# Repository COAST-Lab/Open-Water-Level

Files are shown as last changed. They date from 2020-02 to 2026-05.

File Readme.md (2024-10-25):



# Open Water Level Sensor
## ℹ️ About this Repository
This GitHub repository provides updated designs for a low-cost, open-source, cell-equipped water level sensor. The initial design, published in the journal Oceanography in the special section DIY (do-it-yourself) Oceanography, used a lower resolution sensor and had internal datalogging capabilities. In this repo, we describe how to use a higher-resolution sensor with a cellular modem for near-real-time water level information. 

The article, *A Low-Cost, DIY Ultrasonic Water Level Sensor for Education, Citizen Science, and Research*, can be found here: [https://doi.org/10.5670/oceanog.2023.101](https://doi.org/10.5670/oceanog.2023.101). The article corresponds to an older version of the code which can be found here: [https://github.com/SUPScientist/Seaport_Tide-SLR](https://github.com/SUPScientist/Seaport_Tide-SLR).

Please read the following for a high-level overview of the project and the contents of this repository.

## 🔮 Table of Contents 
Scroll down or click the following links for more information: 
- [Introduction to the Sensor](#-introduction-to-the-sensor)
- [How to Build a Sensor](#-how-to-build-a-sensor)
- [Firmware and getting started guide](Firmware)
- [Deployment Considerations](#-Deployment-considerations)
- [Data Analysis](#-example-data-analysis-routine)

Water level sensor

## 🔌 Introduction to the Sensor
There are several versions of the DIY water level sensor. They include different microcontrollers (e.g., an Arduino-based Feather Adalogger with internal logging capabilities and a Particle Boron with cellular communication capabilities) and sensor interfacing options (analog, serial, and pulse-width modulation). 

If you are looking for a cellular data transmission-enabled device with higher resolution, this repository has what you need. To get started on soldering and building your sensor package, click here [Firmware](Firmware). If you are looking for the original, less expensive Arduino version with internal datalogging capabilities, see [https://github.com/SUPScientist/Seaport_Tide-SLR](https://github.com/SUPScientist/Seaport_Tide-SLR).

The device designs in this repository comprise a low-cost open-sourced sensor package designed to measure distance and transmit and store measurements.  It utilizes a Particle Boron with cellular data transfer, an Adafruit Adalogger Featherwing for local data storage, a Maxbotix ultrasonic rangefinder, a rechargeable lithium-ion battery, and a water-resistant enclosure. 

This repository aims to enable students, communities, businesses, and anyone else to monitor their local water level. To get started, read through this page and subsequent directions. 

## 🔨 How to Build a Sensor
We currently have two effective enclosure designs for the DIY sensor, one using a PVC pipe and the other using a Polycase housing. Below, find links to BOMs, enclosure designs, and datasheets for each model.
- Getting started with the code: [Firmware](Firmware) 
- Link to parts, suppliers, and costs: [PVC BOM](Fabrication/PVC-Enclosure/BOM/), [Polycase BOM](Fabrication/Polycase-Enclosure/BOM/)
- Enclosure designs: [PVC Enclosure & Assembly](Fabrication/PVC-Enclosure/Enclosure-and-Assembly/), [Polycase Enclosure & Assembly](Fabrication/Polycase-Enclosure/Enclosure-and-Assembly/)
- More information on parts: [PVC Datasheets](Fabrication/PVC-Enclosure/Datasheets/), [Polycase Datasheets](Fabrication/Polycase-Enclosure/Datasheets/)

## 🌊 Deployment Considerations
Deployment is the last step but it's probably the most exciting, so we'll start our procedural notes here. The Open Water Level sensor has a ~ 6.5 m (21') range with a 1 cm (0.39") resolution. Deployment locations must be chosen with these values in mind. If you are deploying the monitor at a location reasonably close to an existing NOAA tide station, start by examining the known tidal range at your location: [NOAA tide predictions](https://tidesandcurrents.noaa.gov/tide_predictions.html). You will want to deploy the monitor at a location where it can aim straight down (normal) to the water's surface and at a height slightly higher than the highest high tide or floodwater height that the location is expected to experience. You also want it to be low enough to capture the lowest low water. The package is water resistant, but not fully waterproof if submerged for extended periods.

## 💻 Example Data Analysis Routine
Please see this [example notebook](Data%20Analysis/open_water_level_analysis.ipynb) for Python code that reads in, parses, and plots water level data, including the critical conversion of `distance from the sensor to the water` to a `referenced water level`.

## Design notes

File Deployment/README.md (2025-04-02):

Once you have successfully fabricated the **PVC Model** based on these [steps](https://github.com/COAST-Lab/Open-Water-Level/tree/ac8e949a22b2f5b2a5e1ccd7503b6fde46d579b2/Fabrication/PVC-Enclosure), follow this guide for deployment. Extra supplies needed for these steps are PVC cement, Silicon Sealant, Low Density PTFE seal tape, and O-Ring Silicon Grease.
1. Ensure that the extra LiPo battery and Solar system battery are fully charged.
2. Verify that the correct code and firmware is flashed onto your Boron.
3. We recommend including electrical tape to secure the antenna and 3 pin wires to the side of the chassis. This will help decrease any noise and movement within the PVC during deployment. 
4.Use PVC cement to securely bond the PVC Reducer Bushing, PVC Coupler, and PVC Pipe. Follow the manufacturer's guidelines on the PVC cement packaging for best results. **Safety Note:** Always use PVC cement in a well-ventilated area, preferably outdoors, and wear protective gloves. After cementing, place the assembled product in a fume hood to minimize exposure to fumes.
5. Apply O-ring grease to the O-rings on the PVC end cap and cable gland. **Note:** Before greasing, ensure the O-rings and grooves are completely free of dust and other particles. We recommend using Kimwipes and gloves to clean the rings and grooves thoroughly. Additionally, place Kimwipes on your work surface to keep the components clean during the process.
6.Wrap PTFE seal tape around the threads of the Maxsonar. **Note:** Apply the tape in the same direction as the threading to ensure it remains securely in place when tightened into the PVC bushing, preventing it from unraveling.
7. Once fully charged, place the lipo battery back on the chassis, attach the 3-pin wires together, and slide the chassis into the PVC pipe. 
8. Attach the solar cable gland to the PVC end cap. **Note:** Once the Lipo battery or solar panel cable is plugged into the Boron it will turn on and begin collecting data every hour on the hour. This may be important for your cellular usage. 
9. Once all components are securely placed and connected inside the pipe, attach the PVC cap. Apply silicone sealant to seal the gap between the PVC end cap and the pipe, as well as the space between the solar cable gland and the PVC top.

**Field Specific Deployment Considerations**

According to the ultrasonic sensor's datasheet, objects within a 30 cm radius of a beam normal to the sensor's surface could interfere with its measurements. We recommend deploying the sensor at least **45 cm (or a 50% margin)** away from the closest object to the sensor's downward beam. Also condifer that this sensor has a minimum report distance of **25 cm** and a maximum report distance of **700 cm**.

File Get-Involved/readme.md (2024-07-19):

- Check out the "Get Involved" pamphlet above (available in .pdf and .pptx formats) for ways to become involved with the Open Water Level Sensor project!

- Visit this [link](https://blog.iorodeo.com/author/grace/) for articles featuring the water level sensor project on the IO Rodeo Blog, guest-written by lab member Grace Lower.

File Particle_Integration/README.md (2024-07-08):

# Particle Cloud —-> Google Sheets Integration
1. Get an access token: https://docs.particle.io/reference/cloud-apis/access-tokens/
2. Create a new Google Sheet
3. In Google Sheets, navigate to Extenstions --> Apps Script
4. Copy and paste the `particle_integration.js` file into the Apps Script
5. Replace `{YOUR_PARTICLE_TOKEN_HERE}` with your token from #1
6. Save/rename Apps Script
7. Deploy --> New Deployment (if first time deploying)
8. Select type --> Web App
9. Execute as --> Me
10. Who has access --> Anyone
11. Deploy --> Authorize access --> Click through and allow
12. Under Web App and URL, there should be a URL beginning https://script...; click Copy
13. In `console.particle.io`, navigate to your product (or device) and create a new integration
14. Create Webhook and select Edit --> Custom template
15. Copy and paste text from `particle_integration.json` and replace `{GOOGLE_SHEETS_SCRIPT_URL}` with the URL that you get after deploying the Apps Script (Step 12); save.
16. Run your Particle firmware that is supposed to publish to the cloud and check if it ran at all (e.g., any LED or Log indicators). Then, check the device in `console.particle.io` to see if it published, check the integration to see if it triggered, and check your Google Sheet to see if the data have shown up.

## Credit
This routine borrows from and slightly updates [https://docs.particle.io/integrations/community-integrations/publish-to-google-sheets/](https://docs.particle.io/integrations/community-integrations/publish-to-google-sheets/). Hints on what needed to be updated came largely from [https://community.particle.io/t/pushing-data-to-google-sheets-new-thread/60138](https://community.particle.io/t/pushing-data-to-google-sheets-new-thread/60138).

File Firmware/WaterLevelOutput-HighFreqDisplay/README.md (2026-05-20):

# WaterLevelOutputActivity

This firmware project was created using [Particle Developer Tools](https://www.particle.io/developer-tools/) and is compatible with all [Particle Devices](https://www.particle.io/devices/).

Feel free to replace this README.md file with your own content, or keep it for reference.

## Table of Contents
- [Introduction](#introduction)
- [Prerequisites To Use This Template](#prerequisites-to-use-this-repository)
- [Getting Started](#getting-started)
- [Particle Firmware At A Glance](#particle-firmware-at-a-glance)
  - [Logging](#logging)
  - [Setup and Loop](#setup-and-loop)
  - [Delays and Timing](#delays-and-timing)
  - [Testing and Debugging](#testing-and-debugging)
  - [GitHub Actions (CI/CD)](#github-actions-cicd)
  - [OTA](#ota)
- [Support and Feedback](#support-and-feedback)
- [Version](#version)

## Introduction

For an in-depth understanding of this project template, please refer to our [documentation](https://docs.particle.io/firmware/best-practices/firmware-template/).

## Prerequisites To Use This Repository

To use this software/firmware on a device, you'll need:

- A [Particle Device](https://www.particle.io/devices/).
- Windows/Mac/Linux for building the software and flashing it to a device.
- [Particle Development Tools](https://docs.particle.io/getting-started/developer-tools/developer-tools/) installed and set up on your computer.
- Optionally, a nice cup of tea (and perhaps a biscuit).

## Getting Started

1. While not essential, we recommend running the [device setup process](https://setup.particle.io/) on your Particle device first. This ensures your device's firmware is up-to-date and you have a solid baseline to start from.

2. If you haven't already, open this project in Visual Studio Code (File -> Open Folder). Then [compile and flash](https://docs.particle.io/getting-started/developer-tools/workbench/#cloud-build-and-flash) your device. Ensure your device's USB port is connected to your computer.

3. Verify the device's operation by monitoring its logging output:
    - In Visual Studio Code with the Particle Plugin, open the [command palette](https://docs.particle.io/getting-started/developer-tools/workbench/#particle-commands) and choose "Particle: Serial Monitor".
    - Or, using the Particle CLI, execute:
    ```
    particle serial monitor --follow
    ```

4. Uncomment the code at the bottom of the cpp file in your src directory to publish to the Particle Cloud! Login to console.particle.io to view your devices events in real time.

5. Customize this project! For firmware details, see [Particle firmware](https://docs.particle.io/reference/device-os/api/introduction/getting-started/). For information on the project's directory structure, visit [this link](https://docs.particle.io/firmware/best-practices/firmware-template/#project-overview).

## Particle Firmware At A Glance

### Logging

The firmware includes a [logging library](https://docs.particle.io/reference/device-os/api/logging/logger-class/). You can display messages at different levels and filter them:

```
Log.trace("This is trace message");
Log.info("This is info message");
Log.warn("This is warn message");
Log.error("This is error message");
```

### Setup and Loop

Particle projects originate from the Wiring/Processing framework, which is based on C++. Typically, one-time setup functions are placed in `setup()`, and the main application runs from the `loop()` function.

For advanced scenarios, explore our [threading support](https://docs.particle.io/firmware/software-design/threading-explainer/).

### Delays and Timing

By default, the setup() and loop() functions are blocking whilst they run, meaning that if you put in a delay, your entire application will wait for that delay to finish before anything else can run. 

For techniques that allow you to run multiple tasks in parallel without creating threads, checkout the code example [here](https://docs.particle.io/firmware/best-practices/firmware-template/).

(Note: Although using `delay()` isn't recommended for best practices, it's acceptable for testing.)

### Testing and Debugging

For firmware testing and debugging guidance, check [this documentation](https://docs.particle.io/troubleshooting/guides/build-tools-troubleshooting/debugging-firmware-builds/).

### GitHub Actions (CI/CD)

This project provides a YAML file for GitHub, automating firmware compilation whenever changes are pushed. More details on [Particle GitHub Actions](https://docs.particle.io/firmware/best-practices/github-actions/) are available.

### OTA

To learn how to utilize Particle's OTA service for device updates, consult [this documentation](https://docs.particle.io/getting-started/cloud/ota-updates/).

Test OTA with the 'Particle: Cloud Flash' command in Visual Studio Code or the CLI command 'particle flash'!

This firmware supports binary assets in OTA packages, allowing the inclusion of audio, images, configurations, and external microcontroller firmware. More details are [here](https://docs.particle.io/reference/device-os/api/asset-ota/asset-ota/).

## Support and Feedback

For support or feedback on this template or any Particle products, please join our [community](https://community.particle.io)!

## Version

Template version 1.0.2

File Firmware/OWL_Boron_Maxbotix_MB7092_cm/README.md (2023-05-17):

# SLR_Boron_Maxbotix_MB7092_cm

Script intended to operate a 1 cm resolution, waterproof ultrasonic sensor (MB7092 from Maxbotix) with a Particle Boron. Uses SLR_Boron_Maxbotix_Analog firmware and modifies that script (which was designed for a different sensor with 1 in resolution). Modified by L. Edwards in Spring 2023 and pushed to GitHub initially on 17-May-2023 by P. Bresnahan.

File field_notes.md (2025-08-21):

# Field Notes
NB: Bresnahan has spreadsheet with Device IDs, Device OS, user firmware version (e.g., OWL v1.1.0 or 1.0.0, etc.) in Dropbox. This document is intended for miscellaneous notes from the field jotted quickly while servicing instruments.

### 21-Aug-2025
- SMC-N23 is gone. Entire mount missing from bridge. Only epoxy remaining.
- SMC-KERR updated to Device OS 6.3.3 and firmware built to that OS with `const unsigned long MAX_TIME_TO_PUBLISH_MS = 600000;` Used Workbench "flash application and device OS (local)" option.
- Update: SMC-KERR did not connect to cloud after using Workbench flash application and device OS option so used online Device Restore USB option to 6.3.3 which received a success message. 

### 6-Aug-2025
- At SMC-KERR and BMCUpdated Device OS to 6.2.1 and flashed firmware built to that OS with `const unsigned long MAX_TIME_TO_PUBLISH_MS = 600000;` Used Workbench "flash application and device OS (local)" option.

### 19-May-2025
- From SMC-N23, traded solar panel and interior battery due to inexplicable battery failure (suspected to be issue with solar panel/pack)

### 11-Mar-2025
- Chestnut St and Burnt Mill Creek installed
- Activated 10:36 am EDT, waterLevel_0006, longer pvc

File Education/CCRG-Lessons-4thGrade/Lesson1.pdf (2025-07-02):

What is a Watershed?
Location: Classroom
Time: 50+ Minutes

General Lesson Overview: In this lesson, students will learn what a watershed is and how elevation is important in identifying watershed boundaries in a community. Students will learn how to make a topography map and will practice making a 3D model from a topographical map of a watershed. For this lesson in particular we focus on Burnt Mill Creek, but this could be recreated with any watershed as the location.

- ESS.4.2.3. Use models to explain changes in Earth’s surface over time (to include slow changes of erosion and weathering, and fast changes of earthquakes, landslides, and volcanic activity).

Background Information:
What is topography and why is it important?

Topography is the study of the forms and features of land surfaces. When we talk about topographic maps, we are usually referring to maps with elevation contour lines drawn. Understanding variations in elevation helps us to understand how water may move across the surface. We can determine direction by knowing that water moves from higher to lower elevations, or speed by knowing the influence of slope. Elevation and proximity to water features like streams and rivers can also be used to predict potential flooding.

How do you collect elevation data?
Elevation data can be collected in several ways. Ground surveys can be conducted using RTK (Real-Time Kinematic) GPS. Aerial surveys may also be conducted using sensors (typically LiDAR) mounted on drones or piloted aircraft. Stereo photogrammetry, where photographs taken at slightly different locations are cross-referenced against each other and a known surveyed target, may also be used for gathering elevation data.
What is our community's topography?
We reside in the Coastal Plain for North Carolina which is flat and low lying. The gentle slope of the Coastal Plain make the high velocity water associated with flash flooding unlikely, however, we have an abundance of water features, like the Cape Fear River, our various creeks, and the ocean, which may flood nearby low-lying areas when their water levels rise.
What is GIS, how were the maps made?
Maps are made using Geographic Information Systems (GIS), which are computer systems that analyze geographically referenced information. The data processed using GIS can be gathered via ground survey, aerial survey, or satellite.

Materials and supplies:
- Powerpoint Watershed Modeling Lesson.pptx
- Contour box – with preset measuring units on the side
- Water (in gallon jugs)
- Food coloring - blue
- wet/dry erase
- Sections of watershed topomaps
- White Legos or block landforms
- Lego base or landform base

Procedure:
1. Introductions to the project and the task of today.
a. Today we are focusing on understanding the watershed that we live in and how water flows in our community by looking at maps and understanding elevation data.
b. Have you ever been impacted by flooding?
2. What is a watershed? Do you know what watershed you live in?
a. Have student Think, Pair, Share what is a watershed
b. Guide students to the definition of a watershed.
i. A watershed is a land area that drains water to a common outlet, such as a river, bay, or reservoir. Watershed can also be called a drainage basin or catchment.
3. Scientists use maps to talk about land areas. What do you use a map for?
a. Use the powerpoint to project the google earth map of Wilmington. The purpose of looking at this map is for students to see how we talk about land and how directional and landmark data is displayed on 2D models aka the map.
4. Click to the GIS map of the watershed (the map displayed could be of whatever watershed is in discussion). For this lessons purpose we are focusing on Burnt Mill Creek watershed. The watershed is outlined and shown in blue.
a. Ask students to tell you where rain would gather if it rained at different places in the map.
b. Ask student how they think the watershed was identified. What type of data did scientists maybe use? Guide them if you can to elevation data or how high the land is.
5. What is elevation?
a. Elevation is the height of a location above or below sea level.
b. Let's find out how scientists use maps to communicate elevation!
6. Contour box activity – students will draw a topographical map.
a. Demo how students will work in science teams through this activity. By showing how to do the first level at 2cm then pass out the materials to each small group. (prefer 8 small groups)
i. Pour water to 2cm line
ii. Replace lid.
iii. Trace with a marker
iv. Label with the level and also put a dot on the corner where the ruler is so that you always put the lid on the box the same.
b. Pass out boxes, water, marker.
c. Ok everyone goahead and pour to your first line. Once you meet the line set your pitcher down and put the lid on and draw. Raise your hand when you are done.
d. Alright everyone got that? Awesome. Let'sdo the next level together. Pour water to the third line. Ready go.
i. Put your lid on and draw. Raise your hand when you are done.
e. Next level.
f. 5

th level.
g. 6

th level.
7. Great job! you just drew a topographic map of the mountain.

a. What did you find challenging?
b. What are some observations of your map?
i. Some lines are tight together. At those spots on the landform what do you notice? The land is steep!
c. How do you think someone might use this type of map?
*** Clean up the activity by pouring water back into the milk jugs.
d. Jug in a bucket, funnel over hole, mountain out of shoe box, and pour.
e. This can be done by one person while the other walks around during the Lego build part.
8. You all just drew a topo map from a 3D representation of land. Now we are going to work in reverse! In your small groups you guys are going to take a section of the Burnt Mill Creek watershed and build a 3D model using Legos (older students) or other stacking tools (watershed ).
a. Each small group has a map in front of them. What do you see on the map in front of you?
i. There might be landmarks on your map that you recognize or there might not. Have you ever looked at your neighborhood on a map?
ii. What other things do you see on your map?
1. Numbers – the numbers represent elevations just like what you did on the previous activity. That elevation data was most likely collected using LiDar attached to a drone or via satellite. may have been collected using a
2. A grid – to provide you with guidance as you build up the watershed.
a. To do this you will follow the grid pattern on the lego board and map.
i. 1 grid (1.5cmX1.5cm) = 2X2 lego brick = 845ft
ii. 1 brick height = 5 ft. In elevation
b. Demo doing a grid or 2 with the group. Let the groups test it out. Walk around and support students. If everyone is really struggling get the classes attention and open the floor for students share their challenge and work as a class to solve.
9. What does the elevation LOOK like? How does water flow?
10. Any thoughts on why we would start our discussions of flooding by talking about elevation?
- Water flow to the lowest point and it important to understand when those low spots are in a community.
- As rain increase what else increases? Amount of water the the covers more land.
- What is the other thing scientists should study when they are studying flooding and also want communities to stay safe?
- Water LEVEL! The next time we see you we will be engineering a tool that scientists could use to monitor water levels.
11. Put the landform models into the AR Sandbox and see what happens when it rains.

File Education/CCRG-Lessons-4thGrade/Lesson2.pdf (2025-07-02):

Engineer a water level monitoring tool Location: Classroom
Time: 1 hr

General Lesson Overview: In this lesson, students will engineer a water level tool with consumable materials. Students will interact with a water level sensor and learn about data output for water level during a number of different scenarios.

Background Information:

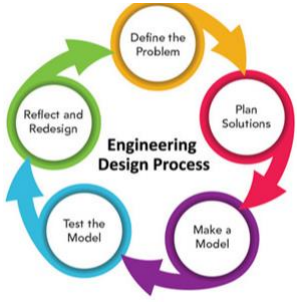
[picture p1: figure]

75% of the world’s population lives within 30 | miles
of a coastline and 90% live within even closer to
freshwater. Our development close to water
bodies requires that water levels stay mostly
stable. Drought that reduces water levels may | have
negative effects on water quality, and excess rain
results in flooding. This is why we monitor water
levels very closely. Federal, state, and local
governments want to know so that we can best prepare and manage.

Why do we care about water level? Flood risk
management, emergency action planning, and | land
and habitat management.
- Environmental health
- Too low = Loss of habitat/food/drinking water, higher concentration of pollutants, erosion or exposed soils.
- Too high = erosion of riverbanks/beds, spread of pollutants and silt, damage vegetation and development, loss of life.
- To manage these risks we engineer levees, spillways, dams ect.
What can we do with water level data?
- Optimize engineering efforts to mitigate flood risks.
- Anticipate floods and take protective measures to reduce people from harms way. Water level measurement methods
1. Staff gauge – giant stick out in the water
2. Wire-weight gauge
3. Shaft encoder/ strip chart recorder – early sensor

4. Pressure transducer – sensor type
5. Bubbler– sensor type
6. Radar– sensor type
7. Hydroacoustic sensors – sensor type - doppler principle to measure.
Definitions:
Water level – the vertical distance (or elevation) from a specific point of reference to the water’s surface. In rivers and streams, it is often referred to as gauge height or stage.
Flood – water on land that is normally dry. Common natural occurrence impacting every US state and territory. Costs of flooding estimate is $8.2 billion and rising annually.
Crest Gage: A Quick Way to Measure River Stage | U.S. Geological Survey (https://www.usgs.gov/special-topics/water-science-school/science/crest-gage-a-quick-way-measure-river-stage)
Materials:
- Bottle caps
- Dowels
- Clear tubing
- Ruler tape
- Floating Styrofoam
- Floats
Procedure:
1. Begin this lesson by having students think about how water moves during a rainstorm. With that in mind, read the picture book FLOOD. FLOOD is a true picture book and does not have any words.
a. If there is time have students sit in a circle and pass the book around with student telling the story by making up sentences to tell the group what is happening on each page. They can create characters or read in 1st person of a kid in the family.
b. If you are tight on time the instructor can walk around telling the story on each page.
i. Key things to point out in the book include:
1. The water body in the back of the property.
2. Ominous storm rolls in.
3. Parents watching the weather and planning while the kids sleep
4. Preparing the property for the storm.
5. Deciding to evacuate.
6. Flood happening overtime
7. Receding flood
8. Resilient and rebuild as community not alone.
2. Review the definitions of a flood and water level, can use to accompanying PowerPoint, EngineerAWaterLevelMonitoringTool.pptx (https://uncw4.sharepoint.com/:p:/r/sites/MarineQuest/Lessons%20and%20Curriculum/Grants/WRRI.CCRG%20-%20Water%20Level/EngineerAWaterLevelMonitoringTool.pptx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)
a. Flood: An overflowing of water onto land that is normally dry.
b. Water level: the vertical depth of water from a reference point. Often referred to as gauge height or stage.
3. Why do we care about the water level???
a. After asking students why we should monitor the water level in present the photo and figure to them.
b. The photo on the slide shows Smith Creek at Kerr Ave. Ask them if they can guess when based on the graph the photo was taking. Using a few context clues they might be able to guess that the photo was taken during TS Debbie in August 2024.
4. Using the engineering cycle, students are tasked with engineering a no tech water level monitoring tool.

a. Present the engineering cycle
b. Brainstorm solutions that are already in existence.
i. Photo of crest gauge.
ii. Ask if they can think of anything students have already seen in the environment.
c. Present the problem: engineer a water level monitoring tool that doesn’t require you to be in the environment to see the highest height of the water level.
d. Review materials with the students

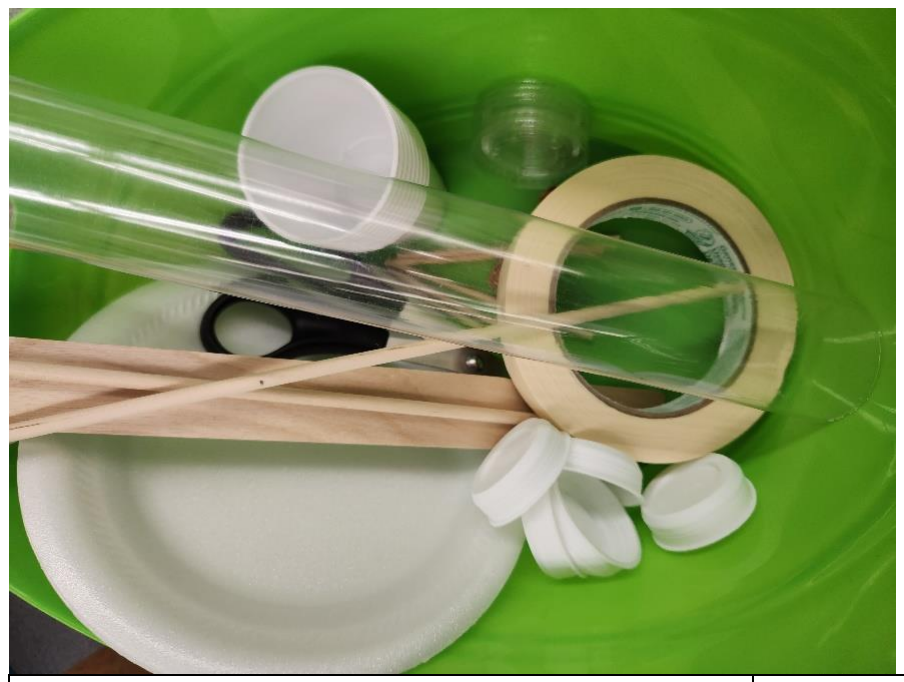
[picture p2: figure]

e. 5 minutes to talk with their table team and draw their design.
f. 10-15 minutes to build.
i. Drilling, box cutting, and dowel cutting ask teacher for help.
g. Test by adding water into a bucket.
i. With about 3 inches of water as the existing water level place the design in the water, for some kids this could be up to the 0 level or at the normal level of the water body (A). Then add more so that the water level increases. You can mimic waters receding as you slowly pull up the monitoring tool (B).

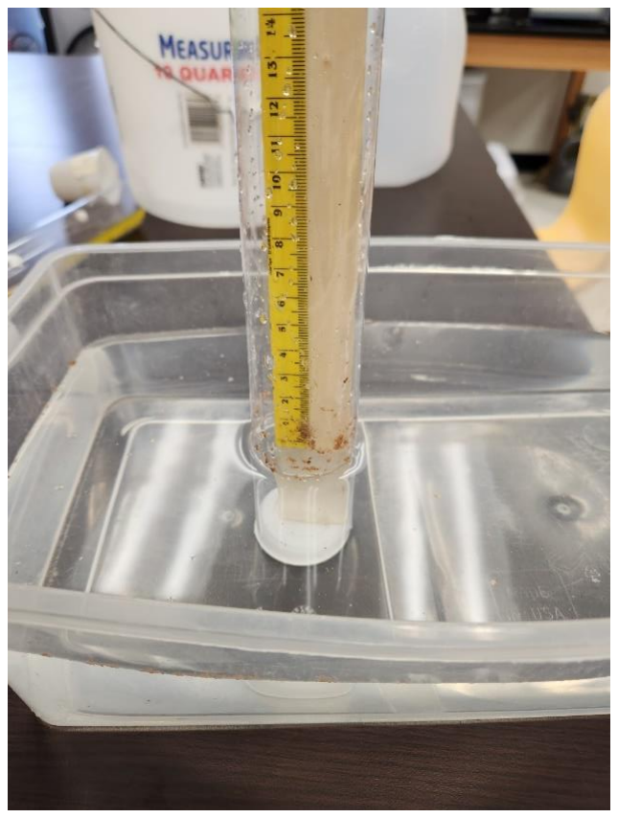
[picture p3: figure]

A. Water monitoring tool in water at mean level.

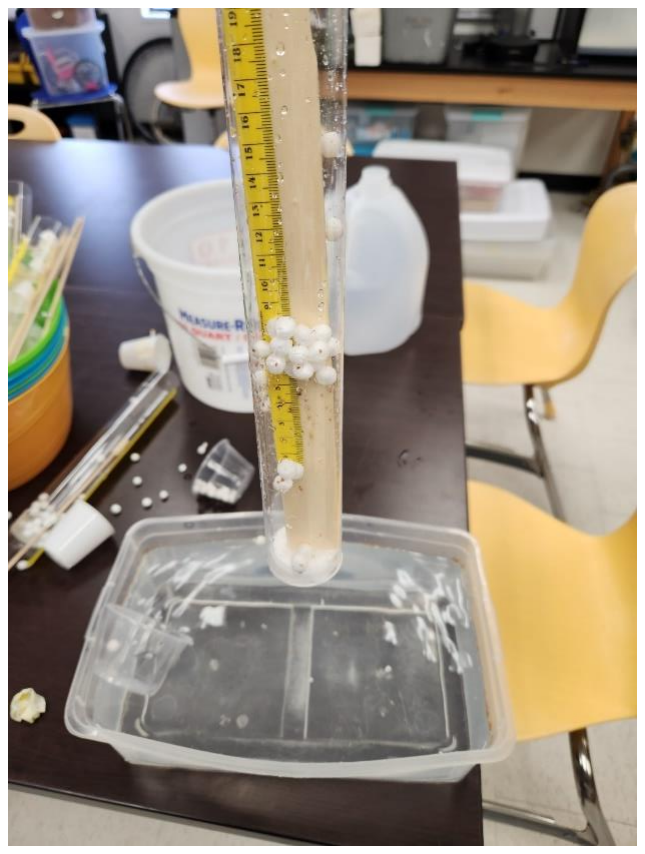
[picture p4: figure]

B. Water level monitor being removed from a flood stage test mimicking water levels receding. Notice how the cork dust and Styrofoam balls stay at the highest high level.
5. If there is time have students present their tool. They should identify pros and cons of their design and what they would do in their redesign.

6. Show students the USGS cork tool.
7. Now that students have designed and identified pros and cons I’m sure they all will want to add some TECH! In the next 5 minutes introduce how electronics have revolutionized environmental monitoring.
a. Show students how the ultrasonic water level sensor works.
b. Give students and opportunity to ask questions and look at the sensor up close.

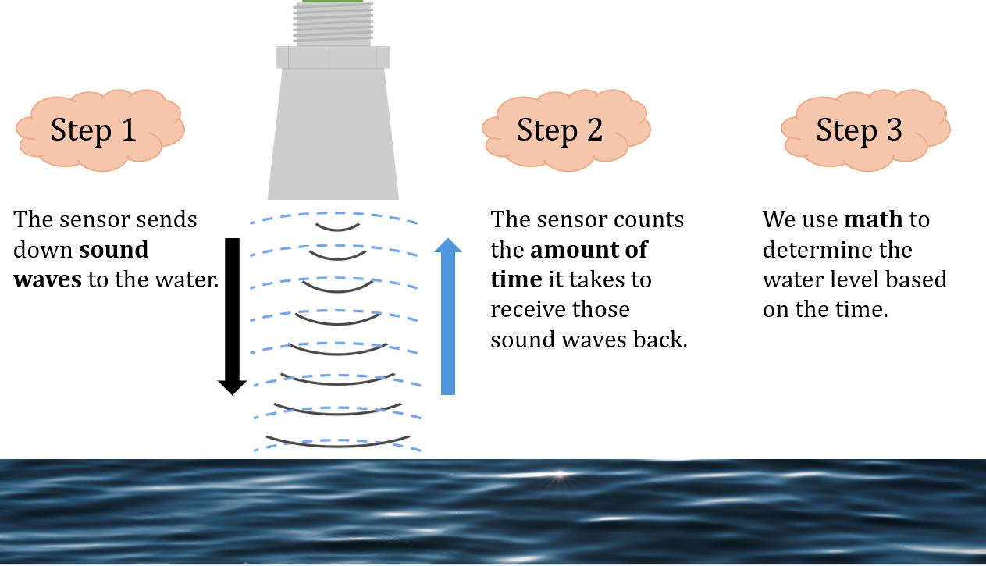
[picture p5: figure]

References:
https://blog.aem.eco/fundamentals_of_water_level_measurement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
Increase the challenge:
Give students a budget for their supplies and they must purchase supplies for the build.

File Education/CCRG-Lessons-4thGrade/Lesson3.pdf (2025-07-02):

VR Burnt Mill Creek Experience
Location: Classroom
Time: 1 hr

General Lesson Overview: Provide students with an immersive experience seeing and making observations of Burnt Mill Creek. This is a general overview of the creek from the headwaters to where it flows into a larger creek, Smith Creek.
Materials:
VR headsets and phones with Expeditions Pro App downloaded
Tablets with Expeditions Pro App downloaded
Wi-Fi router
Internet for downloading the tour onto the tablet https://tours.expeditionspro.com/tour/7929 ***UNCW CESTEM has VR sets available for check-out with the completion of a training course.
Prep:
- Before students arrive, you will need to set up the VR headsets. The phones in the headsets must be charged, have the same version of the app as the teacher tablet, and be connected to the no internet Wi-Fi router if you are using the CESTEM set.
- You must download the tour on the teacher tablet under your specific user account while on the internet. Procedure:
1. Today we are going to go on a virtual field trip hike along Burnt Mill Creek. Using a projected map like the one below, tell the students where they will be going. Headwaters to where the creek joins a larger creek called Smith Creek.

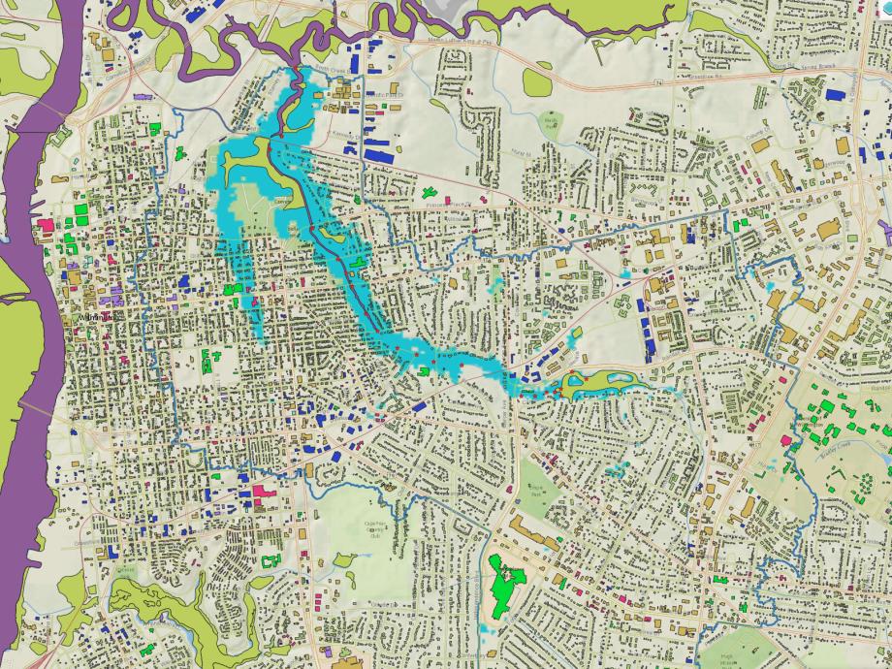
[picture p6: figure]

2. Before students put their headsets up to their faces, please review VR rules and expectations of listening while on the tour.
a. You can stand or sit with the VR headsets. Do not walk.
b. It's ok if you start to feel a little woosie. Just set down your headset. We have a few tablets that we can pass out so that you can still participate.
c. At each tour stop you will have about a minute to look around on your own and be amazed. Once I call everyone back, please stop talking so that everyone can hear.
d. The instructor leads the field trip and will be the one who changes the scene.
3. Let's go! The leader/instructor uses the scene description and asks observation-based questions to keep students engaged.

Trouble shooting
- Make sure the phone is on the correct wi-fi.

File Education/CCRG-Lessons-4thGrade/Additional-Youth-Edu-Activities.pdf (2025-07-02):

# FLOODING LESSON PLAN

Objective: Children of all ages will learn about the effects of flooding and how it connects to the community in Wilmington.

Overview: Kids will be split into two groups based on grade and work on the following highlighted activities about flooding, the issues it brings, and working towards resiliency.

Activity 1: Watersheds (20-30 min)

Kids will work together (can be in groups if there are a lot) to work on the following activities. This gives the kids an understanding of how and where water flows before they move onto the hands-on approach in the next activity.

Group 1 (younger kids) - Branching Out Activity:

Overview: Ideally for ages K-2, kids will use pipe cleaners to make a branching system that goes from streams to rivers. For older students, they can also help name creeks that are local to Wilmington.

Materials needed:

- Pipe cleaners
- Colored pencils, markers, crayons, pencils
- Lined and blank sheets of paper

Directions:

1. Starting with one pipe cleaner, explain to students how this represents a body of water called a creek. Help them understand that this one creek is a small part of the system.
2. Before moving on, relate the creek location to a nearby location (school, community, park, etc.)
3. Continue the branch system by adding another pipe cleaner to the original, making another creek. Help students imagine water flowing from the multiple creeks into the same place.
4. Add more pipe cleaners until you’ve created a stable center connection. Have students guess what this could represent. If they aren’t able to guess correctly, let them know it is a river.
5. Discuss some of the following questions upon completing:

a. What do you think the river flows into? (ocean)
b. Do you think the creeks and river would look the same in a thousand years? Have them think of natural and human-related effects.
c. What would happen if it started to rain a lot?
6. If time permits, students can write a story about or draw a picture of how or where the river flows.

Group 2 (older kids) – Land Coverage Maps

Overview: Students will have maps of Wilmington from two time periods to compare how much land coverage has changed over time and how that can affect runoff in watershed.

Materials:

- Maps of Wilmington from different years
- Wilmington Area Watersheds page

Directions:

1. Ask kids what some major cities might have been like 100 or 50 years ago and how growth has changed those communities today.
2. Present kids with copies of Wilmington from *past year* and present time. Have them look for schools, businesses, restaurants, or others new buildings that didn't exist in the first picture.
3. Once they have pinpointed a few locations, have the kids look to see if they are near water.
4. Introduce the watersheds of this area and have kids compare the locations they have focused on to which watershed that building is a part of.

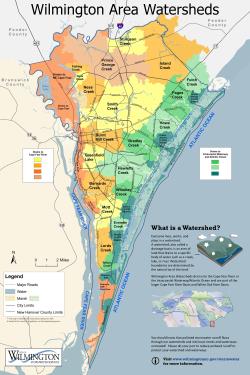
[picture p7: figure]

5. After giving them a few minutes, ask the kids how they think the growth of the city has affected creeks and the river over the years.
a. How would this affect the watersheds?
6. Other questions to ask:
a. How could the proximity to water affect the condition of the buildings?
b. How could these factors contribute to flooding? Have them think about land loss and possible resiliency.
c. How could more greenery reduce flooding?
d. What are other human impacts on water? (ex- trash, runoff)
e. Would you have handled development differently?

Activity 2: Enviroscapes (30-40 min)

Overview: Children will work with Enviroscapes to simulate how flooding works. Ideally, they can split into groups depending on size and age, with each station focusing on something geared more towards the age.

Materials:

- Enviroscape (2)
- Spray bottles (4)
- “Pollution”
- Plastic
- Pet waste (cocoa puffs)
- Oil (soy sauce)

- Chemicals (Kool aid)
- Natural barriers
- Clay or Lego

Directions:

Group 1:

1. Before starting, discuss what flooding is, how it happens, and why it can be dangerous.
2. Start with water filled up in the river and strategically set up buildings and other props to have a better simulation of flooding effects.
3. Have kids observe the water line and building locations close to the river.
4. Students will spray the enviroscape with multiple bottles to simulate a heavy storm for 30 seconds to one minute until an appropriate amount of time has created flooding.
5. Children will then observe the water line again and if any “damage” has occurred.
6. If time permits, sprinkle a pollutant or two around and have the kids spray again. Have them observe where the pollutants go.

Group 2:

1. Before starting, discuss what flooding is, how it happens, and why it can be dangerous. Additionally, discuss the issues pollution and erosion can cause during flooding events.
2. Start with water filled up in the river and strategically set up buildings and other props to have a better simulation of flooding effects.
3. Have kids observe the water line and identify pollutants and/or building locations close to the river.
4. Children will spray the enviroscape with multiple bottles to simulate a heavy storm for 30 seconds to one minute until an appropriate amount of time has created flooding.
5. Children will then observe the water line again and if any “damage” has occurred. They should indicate where pollutants ended up and how much is left in the original location.
6. Next, put up “natural barriers” to simulate shoreline greenery. Explain to students that this strengthens the soil to prevent erosion in addition to providing a barrier to the amount of water getting through.
7. Have kids spray water again and discuss the differences observed versus not having the barriers. If time permits, further discuss real life barriers that could provide solutions to flooding resiliency.

Activity 3: Post Flood Drawing (1 hour)

Overview: Using available tools, kids will choose from the following topics to express their thoughts on one of the given prompt options. Kids can choose to spend their time with just one or move through multiple if they desire. Topics/prompts are bulleted with prompts listed beneath.

*Can be on one large sheet or provide smaller individual one if preferred? Or could be split based on topic

Materials:

- Sheets of paper (medium-large)
- Colored pencils, markers, crayons, pencils
- Prompt cards?

Directions:

Group 1:

- How does flooding make you feel?
- Where have you seen or experienced flooding before? If you haven’t, talk to someone who has.
- How can you stay safe if it’s going to flood?
- What does your nearest river or creek look like?

Group 2:

- Where have you seen or experienced flooding before?
- What did it feel like after a flooding event occurred?
- How can flooding be prevented in the future? Choose one to focus on.
- Living shorelines
- As the name implies, this is a naturally made barrier that provides a habitat for living animals. It creates additional support between land and water to reduce the impact of water and wind hitting the shoreline.
- Land acquisition
- This process involves taking over land to turn it into conservation or preservation areas that provide important greenery to the environment.
- Stormwater drainage systems
- These systems include installing permeable pavement and strategically placed drains to prevent the water from building up quickly.
- Wetland restoration

- In addition to protecting these wetlands, we can plant trees and other native plants near bodies of water to control erosion and store water in their roots
- Rain gardens
- These gardens are built at a lower elevation to collect water from places like gutters, roads, or driveways to reduce runoff and filter pollution. Shrubs and flowers are often used to create one of these gardens.

Conclusion/Take home:

- flood kit sheet
- aimed towards younger children, can realistically be given to anyone who wants to complete
- ICE – have one available for each kid to take home

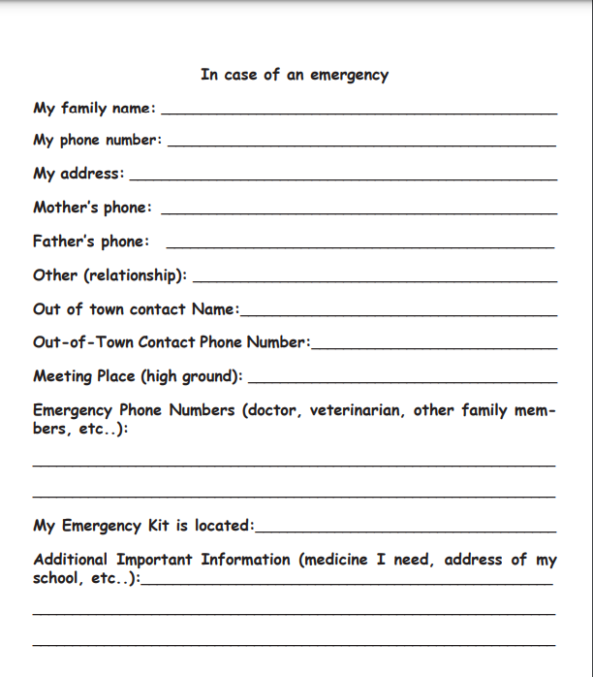
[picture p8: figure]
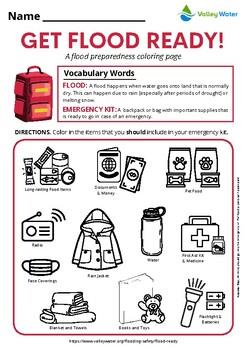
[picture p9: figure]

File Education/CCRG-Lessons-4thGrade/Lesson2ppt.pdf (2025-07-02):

# Flooding and

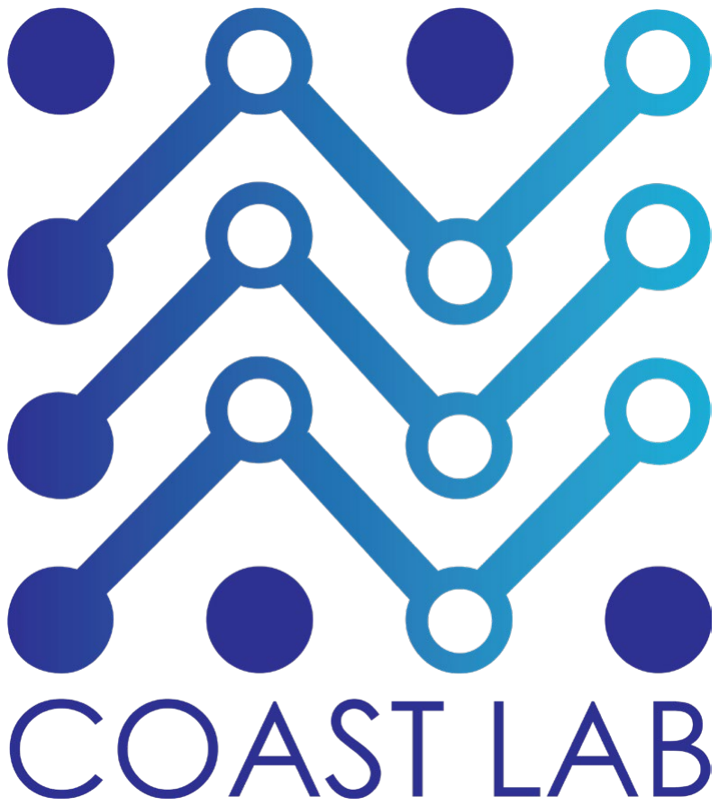
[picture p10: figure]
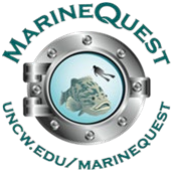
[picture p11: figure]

# Water Level Monitoring

## What is flooding?

An overflowing of water onto land that is normally dry.
We monitor and describe flooding with water level data.

Water level – the vertical depth of water from a reference point. Often referred to as gauge height or stage.
- NOT the depth of the water. It’s the deviation from normal or mean if the area is tidal.

## Why do we monitor water

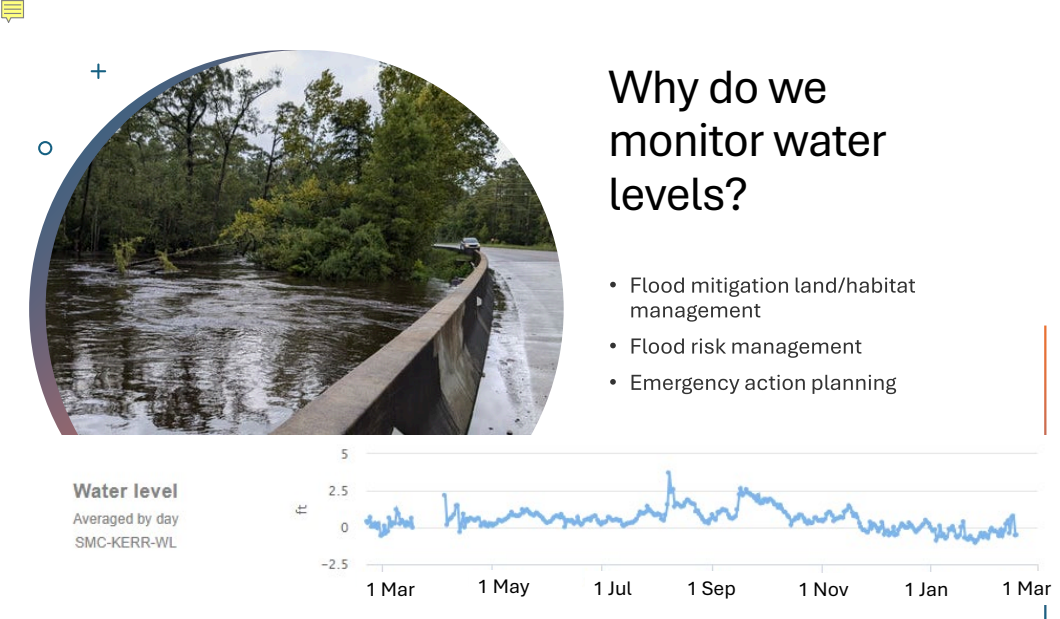
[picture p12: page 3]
levels?; 1 Mar; 1 May; 1 Jul; 1 Sep; 1 Nov; 1 Jan

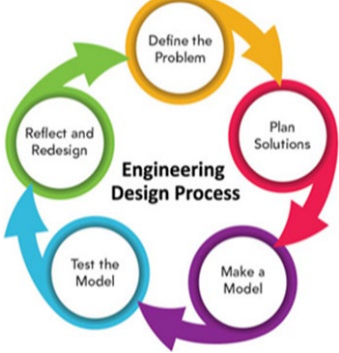
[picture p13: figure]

## The Engineering Cycle

Problem: Notify communities when they need to be prepared for flooding impacts.

1. Brainstorm solutions and research what's already in existence
2. Make a model
3. Test

## Low-tech No-tech monitoring

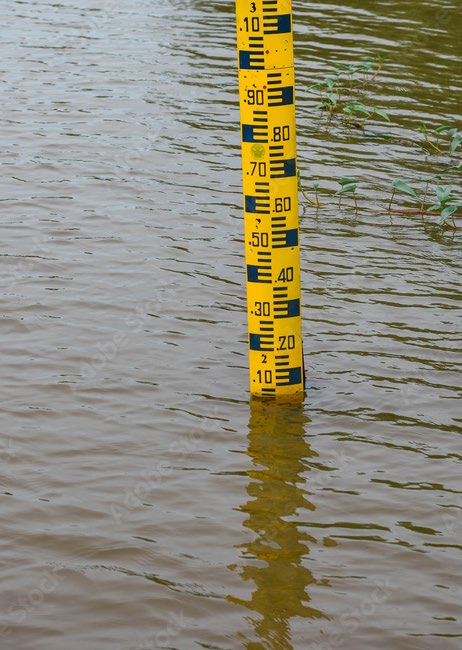
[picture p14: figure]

Pros | Cons
- Low cost
- Easy
installation
- Must monitor
| by viewing at regular intervals.

## Procedure

- 5 minute make a plan
- 10 minutes build
- Test
- While you wait to test…
- What are pros & cons
of your design?
- What would you do in
a redesign?
Pros | Cons

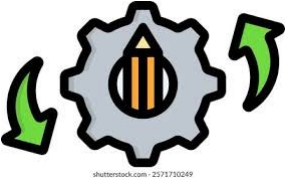
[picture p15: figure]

## USGS Crest Stage Guage

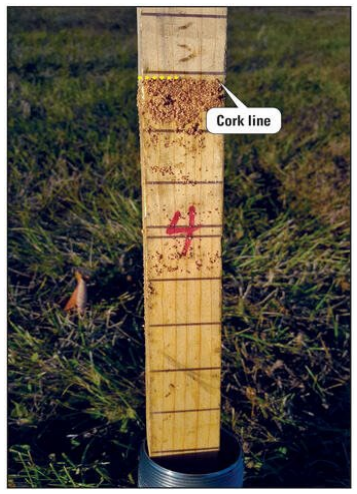
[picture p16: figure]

Pros | Cons
- Records the
highest water
level
- Don’t have to be
in the field to
record the high.
- Must reset
| between each storm.
- Increased room
| for error.

# Step 1 Step 2 Step 3

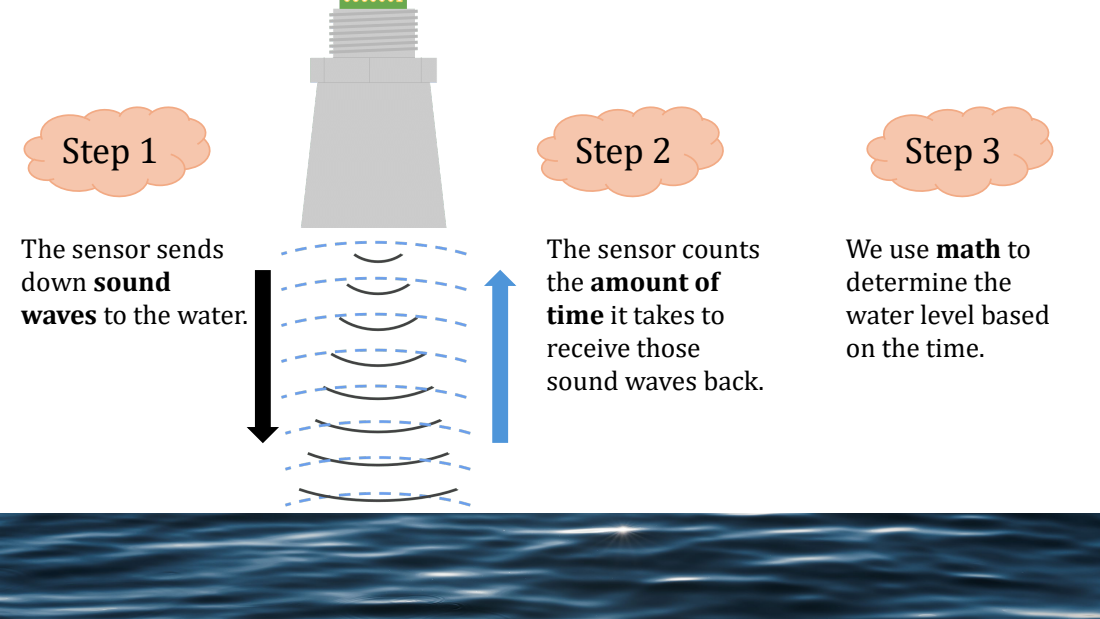
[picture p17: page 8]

The sensor sends
down sound
waves to the water.

We use math to
The sensor counts
determine the
water level based
time it takes to
on the time.
receive those
sound waves back.

the amount of

## What does the data look like?

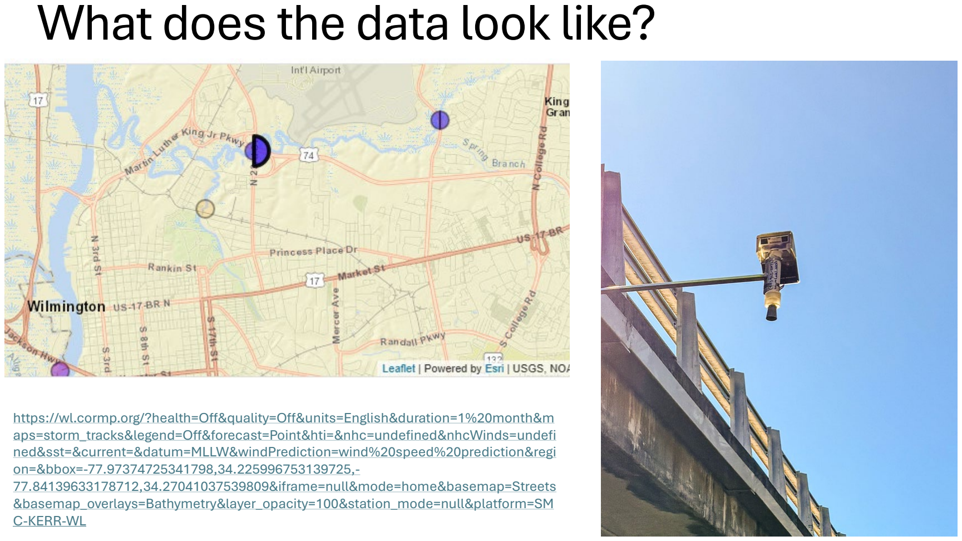
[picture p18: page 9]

https://wl.cormp.org/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,34.225996753139725,-77.84139633178712,34.27041037539809&iframe=null&mode=home&basemap=Streets &basemap_overlays=Bathymetry&layer_opacity=100&station_mode=null&platform=SM C-KERR-WL (https://wl.cormp.org/?health=Off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)

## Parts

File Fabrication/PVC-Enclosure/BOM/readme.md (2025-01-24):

# Bill of Materials for PVC Design
Please note: Prices are listed in USD and are subject to change based on market value and availability.

Parts | Function | Cost | URL
| :---------------- | :------ | :---- | :---- |
Boron LTE CAT-M1 (NorAm) with EtherSIM (BRN404X) | Microcontroller, cell modem, power management | $65.31 (available at lower cost from Particle?) | https://www.digikey.com/en/products/detail/particle-industries-inc/BRN404X/17632424
Antenna (included in above) | Cellular communications | |
MB7092 XL-MaxSonar-WRMA1 | Distance sensor | $99.95 | https://www.adafruit.com/product/1137
Adalogger FeatherWing - RTC + SD Add-on For All Feather Boards | Data storage board | $8.95 | https://www.adafruit.com/product/2922
Stacking header pins for FeatherWing | Stack Boron on FeatherWing | $1.95 | https://www.adafruit.com/product/2940
PVC Pipe 1-1/2 in. x 10 ft. 330 psi Schedule 40 DWV | Enclosure | $1.28 per ft; $10.24 | https://www.homedepot.com/p/1-1-2-in-x-10-ft-330-psi-White-PVC-Schedule-40-DWV-Plain-End-Pipe-531111/100135041
PVC Pipe Fitting for Water, Bushing Reducer, 1-1/2 Socket Male x 3/4 NPT Female | Connect ultrasonic distance sensor to PVC pipe | $2.63 | https://www.mcmaster.com/4880K208/
PVC Pipe Fitting for Water, Straight Connector 1-1/2 Socket-Connect Female | Connect pipe bushing to PVC | $1.27 | https://www.mcmaster.com/4880K75/
FormLabs Clear Resin V4 | Chassis to secure internal parts | $150 per L | https://formlabs.com/store/materials/clear-resin-v4/
Super-Corrosion-Resistant 316 Stainless Steel Socket Head Screw M2x0.4mm Thread, 16mm long | Secure Boron and FeatherWing to chassis | $13.32 per 50; $1.0656 for 4 | https://www.mcmaster.com/92290A746/
Super-Corrosion-Resistant 316 Stainless Steel Hex Nut M2x0.4mm Thread 1.6mm height | Receive 16mm screws | $5.88 per 50; $0.4704 for 4 | https://www.mcmaster.com/94150A305/
SD/MicroSD Memory Card (8 GB SDHC) | Data storage | $9.95 | https://www.adafruit.com/product/1294
Loctite Epoxy Marine | Glue hex nuts to chassis, seal holes | $5.88 per 25 mL | https://www.loctiteproducts.com/products/central-pdp.html/loctite-epoxy-marine/SAP_0201OIL029V5.html
3-pin cable | Power, ground, and analog signal to/from sonar | $0.95 | https://www.adafruit.com/product/4721
5 Watt 5 Volt 35Wh Solar System | Solar charging | $99.00 | https://voltaicsystems.com/5-watt-5-volt-35wh-solar-system/
USB A to Micro-B cable | Splice to solar panel power for Boron USB connection | $2.95 | https://www.adafruit.com/product/592
Cable gland for 0.08"-0.24" Cord OD | Waterproof cable entry | $2.45 | https://www.digikey.com/en/products/detail/lapp/S2209/11200603
1/2" x 520" PTFE pipe tape | Tape threads on distance sensor | $1.68 per roll | https://www.homedepot.com/p/William-H-Harvey-Company-1-2-in-x-520-in-White-PTFE-Tape-177333/100025685
Gripper 1-1/2 in. Plastic Mechanical Test Plug | Sealing end of PVC | $5.65 | https://www.homedepot.com/p/Oatey-Gripper-1-1-2-in-Plastic-Mechanical-Test-Plug-33400D/100342630
FormLabs Clear Resin V4 | Chassis to secure internal parts | $150 per L | https://formlabs.com/store/materials/clear-resin-v4/
FormLabs Tough Resin 2000 | Resin for PVC Top | $149.00 | https://formlabs.com/store/materials/tough-2000-resin/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
O-rings | Seal on PVC end cap | $7.81 | https://www.mcmaster.com/9464K291/
Lithium Ion Battery Pack - 3.7V 4400mAh | Adjacent battery | $19.95 | https://www.adafruit.com/product/354
PVC Coupler | Attachment between Maxsonar and PVC pipe | $5.79 | https://www.amazon.com/LASCO-FITTINGS-429-015-SLIP-COUPLING/dp/B004VU99S4
Silicon Grease |O-ring effectiveness and ease with PVC top removal| $24.92 | https://www.grainger.com/product/436P94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
Silicon Sealant |Water and air protection| $11.32 |https://www.grainger.com/product/3LA50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
PVC Cement | Water and air protection| Dependent on type |https://www.grainger.com/category/adhesives-sealants-and-tape/caulks-sealants-gasket-makers/pipe-sealants/pipe-cement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
1-1/2" x 3/4" Schedule 40 PVC Reducer Bushing| Connector between PVC and Maxsonar|$1.73|https://www.pvcfittingsonline.com/438-210-1-1-2-x-3-4-schedule-40-pvc-reducer-bushing-flush-style.html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
PVC Pipe Tape |Tape around Maxsonar threads | $1.07| https://www.grainger.com/product/3PDL5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
Cell plan (for now: Particle's Free Plan) | Cloud data management | $0.00 | [INSERT LINK]
Approx. cost per sensor unit | | ~311 USD |

Adafruit wishlist: http://www.adafruit.com/wishlists/589193  
Digi-Key wishlist: https://www.digikey.com/en/mylists/list/3G4W9NENB6

Please note: These wishlists may need to be udpated as design changes progress.

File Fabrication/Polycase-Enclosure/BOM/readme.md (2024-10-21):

We're working on this page! An updated BOM will be added soon.

# Bill of Materials for Polycase Design
Please note: Prices are listed in USD and are subject to change based on market value and availability.

Parts | Function | Cost | URL
| :---------------- | :------ | :---- | :---- |
Boron LTE CAT-M1 (NorAm) with EtherSIM (BRN404X) | Microcontroller, cell modem, power management | $65.31 | https://www.digikey.com/en/products/detail/particle-industries-inc/BRN404X/17632424
Antenna (included in above) | Cellular communications | |
MB7092 XL-MaxSonar-WRMA1 | Distance sensor | $99.95 | https://www.adafruit.com/product/1137
Adalogger FeatherWing - RTC + SD Add-on For All Feather Boards | Data storage board | $8.95 | https://www.adafruit.com/product/2922
Stacking header pins for FeatherWing | Stack Boron on FeatherWing | $1.95 | https://www.adafruit.com/product/2940
ML-24F Outdoor NEMA Enclosure | Enclosure | $14.24 | https://www.polycase.com/ml-24f
FormLabs Clear Resin V4 | Chassis to secure internal parts using | $150 per L | https://formlabs.com/store/materials/clear-resin-v4/
Rounded Head Thread-Forming Screws for Brittle Plastic, 18-8 Stainless Steel, #4-24 1/4" long | Mounting chassis to Polycase | $5.29 per 100; $0.2116 per 4 | https://www.mcmaster.com/97349A415/
18-8 Stainless Steel Socket Head Screw M2.5x0.45mm Thread, 18mm long | Mounting Boron + FeatherWing and antenna frame to chassis | $15.75 per 50; $1.26 per 4 | https://www.mcmaster.com/91292A028/
18-8 Stainless Steel Hex Nut M2.5x0.45mm Thread, 2mm height | Receive chassis screws | $6.45 per 100; $0.258 per 4 | https://www.mcmaster.com/91828A113/
SD/MicroSD Memory Card (8 GB SDHC) | Data storage | $9.95 | https://www.adafruit.com/product/1294
3-pin cable | Power, ground, and analog signal to/from sonar | $0.95 | https://www.adafruit.com/product/4721
5 Watt 5 Volt 35Wh Solar System | Solar charging | $99.00 | https://voltaicsystems.com/5-watt-5-volt-35wh-solar-system/
USB A to Micro-B cable | Splice to solar panel power for Boron USB connection | $2.95 | https://www.adafruit.com/product/592
Cable gland for 0.08"-0.24" Cord OD | Waterproof cable entry | $2.45 | https://www.digikey.com/en/products/detail/lapp/S2209/11200603
1/2" x 520" PTFE pipe tape | Tape threads on distance sensor | $1.68 per roll | https://www.homedepot.com/p/William-H-Harvey-Company-1-2-in-x-520-in-White-PTFE-Tape-177333/100025685
Loctite Epoxy Marine | Glue hex nuts to chassis, seal holes | $5.88 per 25 mL | https://www.loctiteproducts.com/products/central-pdp.html/loctite-epoxy-marine/SAP_0201OIL029V5.html
Cell plan (for now: Particle's Free Plan) | Cloud data management | $0.00 | [INSERT LINK]
Approx. cost per sensor unit | | ~312 USD |

Adafruit wishlist: http://www.adafruit.com/wishlists/589193
Digi-Key wishlist: https://www.digikey.com/en/mylists/list/3G4W9NENB6
*Please note: These wishlists may need to be udpated as design changes progress.*

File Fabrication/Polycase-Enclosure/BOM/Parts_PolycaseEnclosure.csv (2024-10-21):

Part | Size | Link
Polycase (ML-24F) + screws | External: 114 x 67 x 52 mm, Internal: 106 x 59 x 44 mm | ML-24F Outdoor NEMA Enclosure
Chassis | Custom | 3D printed chassis
FormLabs Resin | 1 L | Clear V4 Resin
Mounting screws for chassis | #4-24 1/4" | Mounting boss screws
Boron 404X | 0.9 x 2 in | Boron 404X
Adalogger FeatherWing | 50.8 x 22.9 x 1.6 mm | Adalogger FeatherWing
Stacking header pins | 12- & 16-pin | Short header pins
Mounting screws for electronics | M2.5 x 0.45, 18mm length | M2.5 screws
Hex nuts for electronics | M2.5 x 0.45, 2mm height, 5mm width | M2.5 hex nuts
Cellular antenna (included with Boron) | 122.1 x 12.8 x 0.2 mm | Antenna
Maxbotix Ultrasonic Rangefinder | 71.09 x 43.84 mm | Maxbotix
Pipe tape | 1/2" x 520" | Pipe tape
3-pin cable | 40 cm x 1.25 mm | 3-pin cable
Solar system | See site for parts dimensions | 5 Watt 5 Volt 35Wh Solar System
USB cable | USB A to Micro-B | USB Cable
Cable gland | Cable range 0.08" - 0.24" | Cable gland
Adhesive | 25 mL | Loctite Marine Epoxy

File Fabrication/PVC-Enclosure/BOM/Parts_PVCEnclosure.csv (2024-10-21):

Part | Size | Link | Notes
PVC pipe | Nominal internal diameter 1.5" x 10' | 1-1/2 in x 10 ft 330 psi PVC
End cap (gripper) | 1.5" (40mm) | Oatey Gripper
Pipe bushing | 1-1/2" pipe, 3/4" NPT | Pipe bushing
Pipe coupling | Pipe size 1-1/2" (ID) | Pipe coupling
Adhesive | 25 mL | Loctite Marine Epoxy | Can be used for gluing hex nuts into chassis, connecting PVC pipe/coupling/bushing, & sealing external holes (if not using cable glands)
Pipe cement primer | 8 fl oz | Pipe cement primer | Not needed if using marine epoxy instead
Pipe cement | 8 fl oz | Pipe cement | Not needed if using marine epoxy instead
Chassis | Custom | 3D printed chassis
FormLabs Resin | n/a | Clear V4 Resin
Boron 404X | 0.9 x 2 in | Boron 404X
Adalogger FeatherWing | 50.8 x 22.9 x 1.6 mm | Adalogger FeatherWing
Stacking header pins | See website | Short header pins
Mounting screws for electronics | M2 x 0.4, 16mm length | M2 Screws
Hex nuts for electronics | M2 x 0.4, 1.6mm height | Hex Nut
MicroSD card | 8 GB | SanDisk MicroSD
Cellular antenna (included with Boron) | 122.1 x 12.8 x 0.2 mm | Antenna
Maxbotix Ultrasonic Rangefinder | 71.09 x 43.84 mm | Maxbotix
Pipe tape | 1/2" x 520" | Pipe tape
3-pin cable | 40 cm x 1.25 mm | 3-pin cable
Solar system | See site for indv'l parts dimensions | 5 Watt 5 Volt 35Wh Solar System
USB cable | USB A to Micro-B | USB Cable

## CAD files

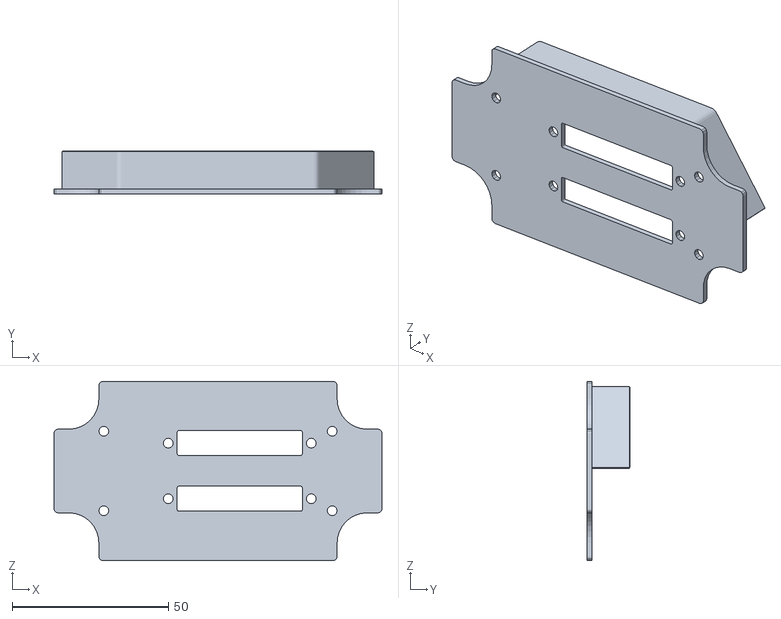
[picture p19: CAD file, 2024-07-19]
Fabrication/Polycase-Enclosure/Enclosure-and-Assembly/Chassis_Polycase_20240718.stl
104.9 x 13.6 x 57.3

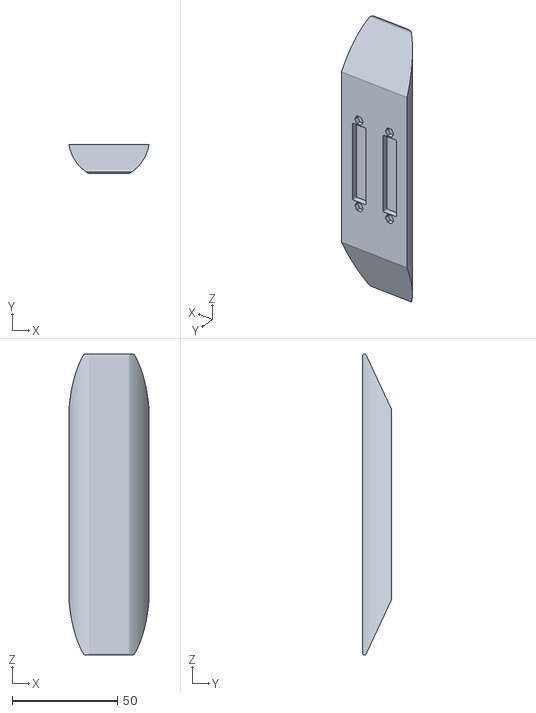
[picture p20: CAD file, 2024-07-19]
Fabrication/PVC-Enclosure/Enclosure-and-Assembly/Chassis_PVC_20240718.stl
38.1 x 14.0 x 143.0

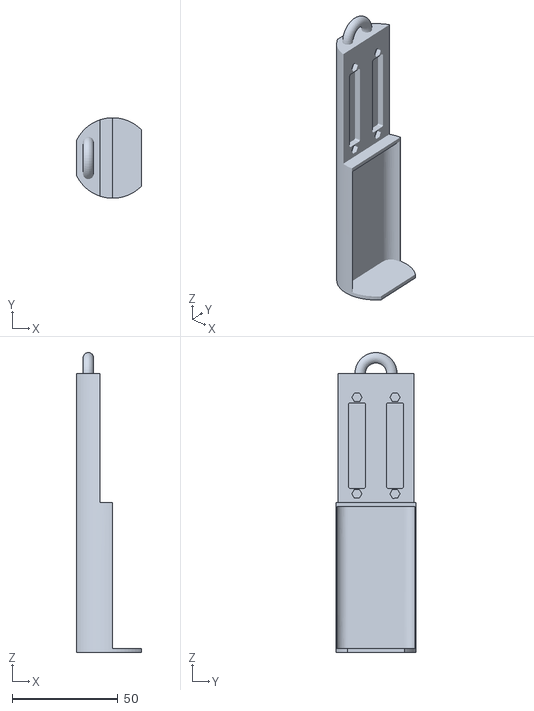
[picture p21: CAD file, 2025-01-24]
Fabrication/PVC-Enclosure/Enclosure-and-Assembly/PVC-Chassis/Chassis_PVC.stl
30.6 x 38.1 x 142.0

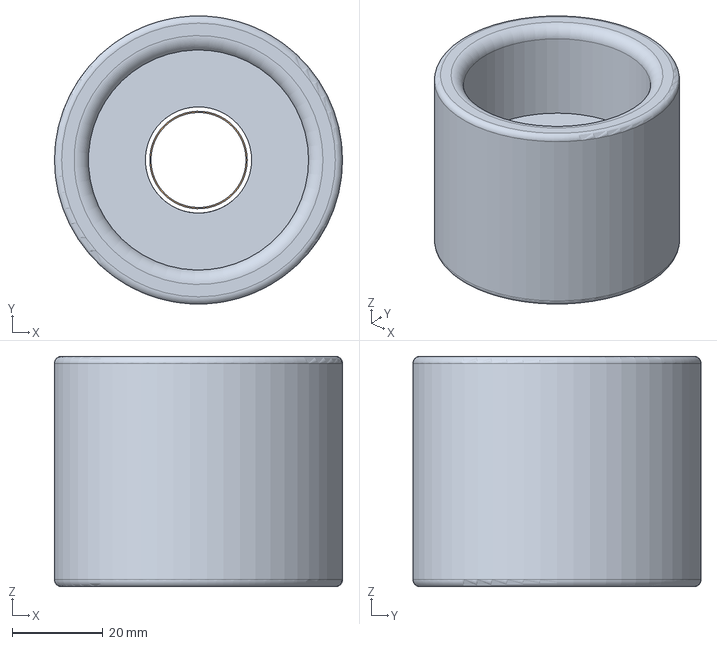
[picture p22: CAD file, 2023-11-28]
Fabrication/PVC-Enclosure/Enclosure-and-Assembly/PVC-End-Caps/STEP/WaterLevel_BottomCap_ACL v2.step
63.5 x 63.5 x 50.8 mm

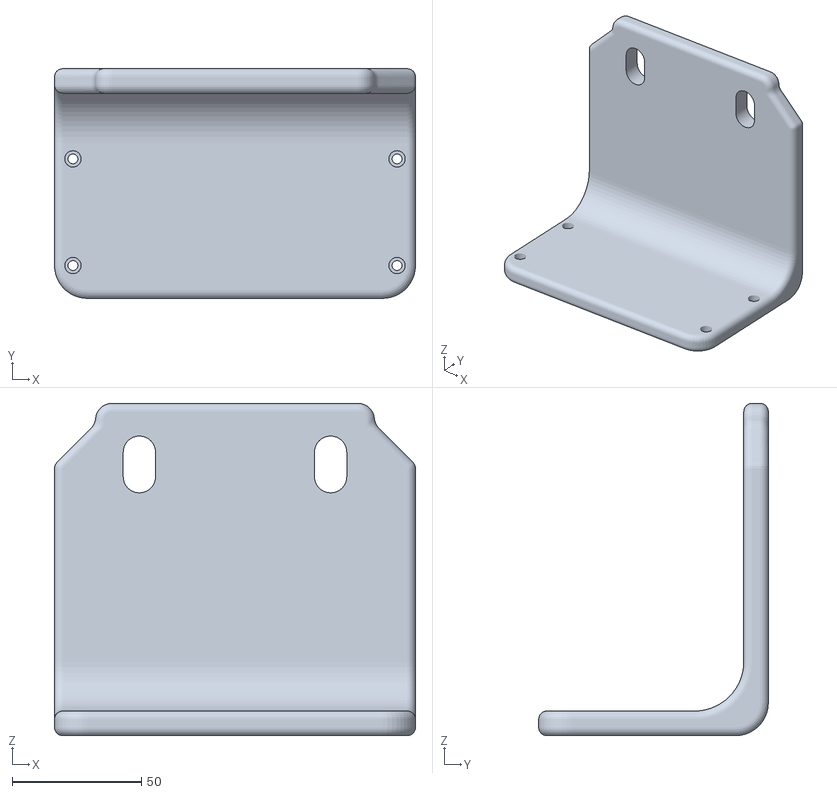
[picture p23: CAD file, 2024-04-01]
Fabrication/PVC-Enclosure/Enclosure-and-Assembly/Voltaic-Polycase-Bracket/Polycase-Voltaic-Bracket v12.stl
139.7 x 88.9 x 128.6

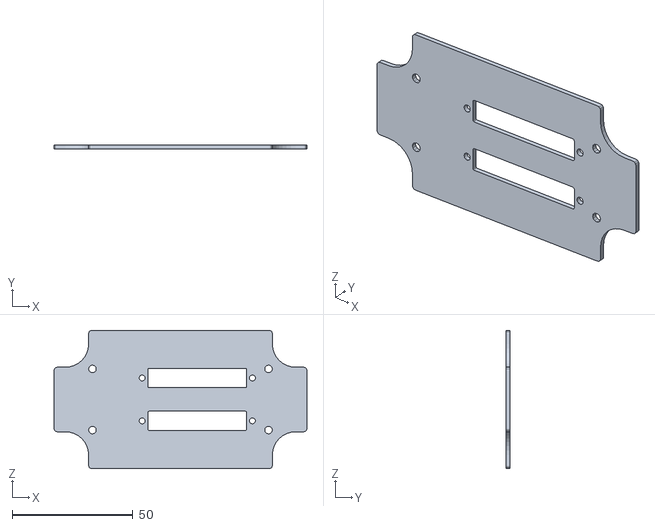
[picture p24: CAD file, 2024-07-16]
Fabrication/Polycase-Enclosure/Enclosure-and-Assembly/Chassis_Polycase_20240702.stl
104.9 x 1.59 x 57.3

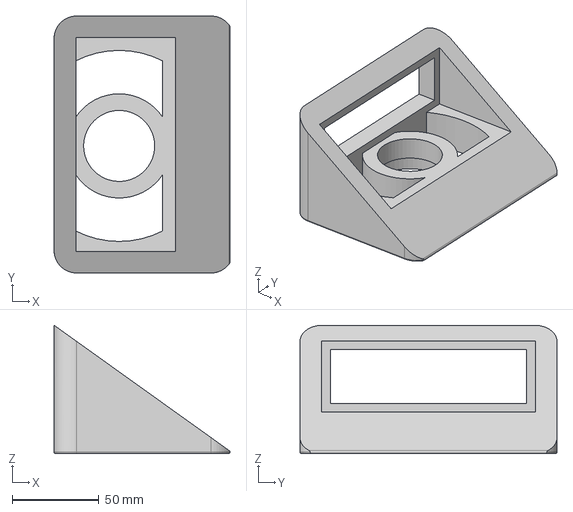
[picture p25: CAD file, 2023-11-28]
Fabrication/PVC-Enclosure/Enclosure-and-Assembly/PVC-End-Caps/STEP/WaterLevel_Top v10.step
101.3 x 148.0 x 74.0 mm

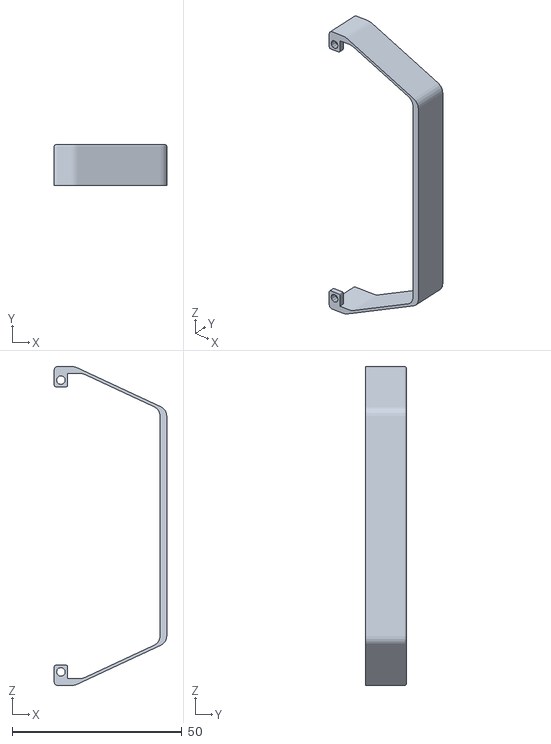
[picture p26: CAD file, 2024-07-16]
Fabrication/Polycase-Enclosure/Enclosure-and-Assembly/AntennaFrame_20240702.stl
33.2 x 12.0 x 93.9

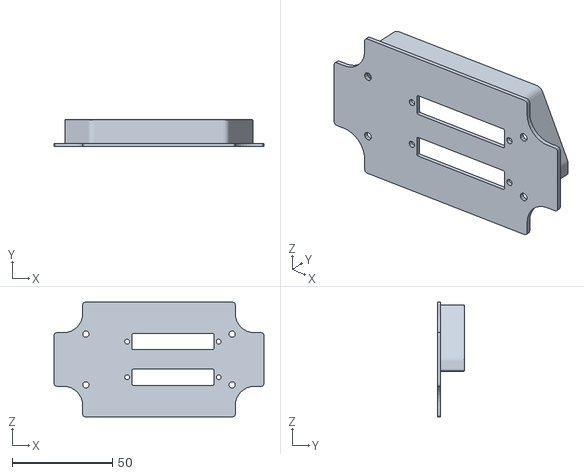
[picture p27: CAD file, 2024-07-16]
Fabrication/Polycase-Enclosure/Enclosure-and-Assembly/Chassis_Polycase_Simplified_20240709.stl
104.9 x 13.6 x 57.3

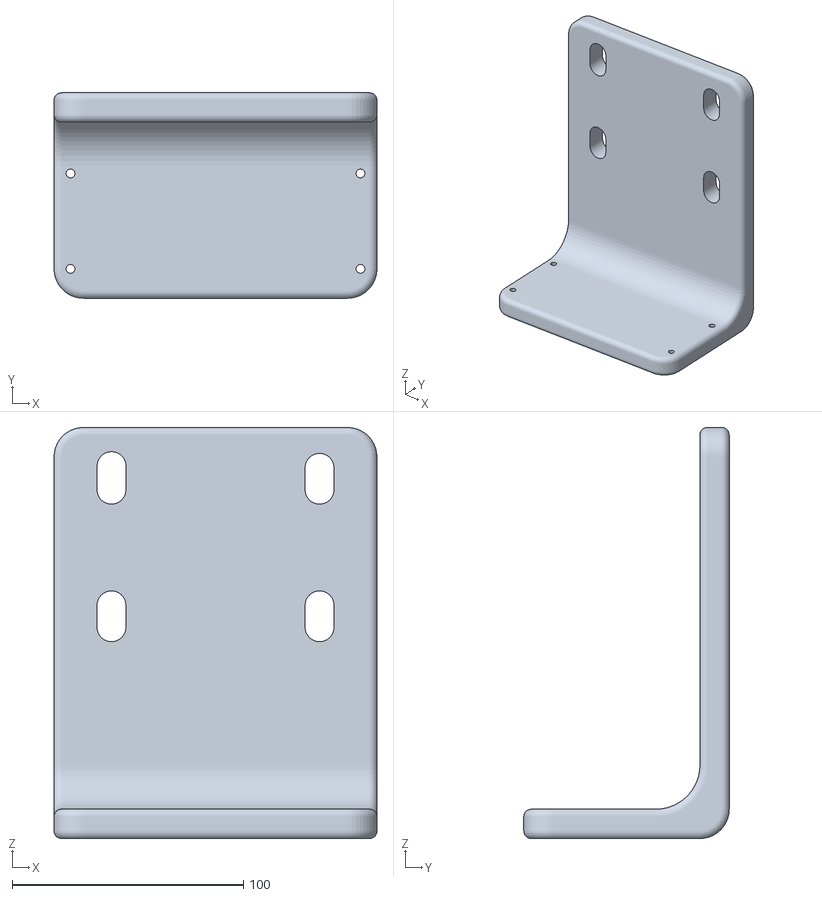
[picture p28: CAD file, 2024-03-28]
Fabrication/PVC-Enclosure/Enclosure-and-Assembly/Voltaic-Polycase-Bracket/Polycase-Voltaic-Bracket_shorter.stl
139.7 x 88.9 x 177.8

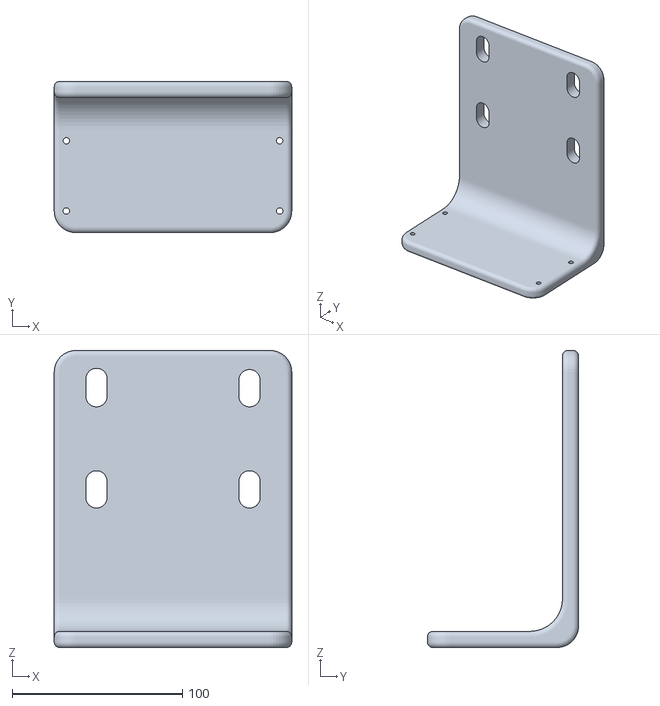
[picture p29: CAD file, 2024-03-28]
Fabrication/PVC-Enclosure/Enclosure-and-Assembly/Voltaic-Polycase-Bracket/Polycase-Voltaic-Bracket_shorterThinner.stl
139.7 x 88.9 x 174.6

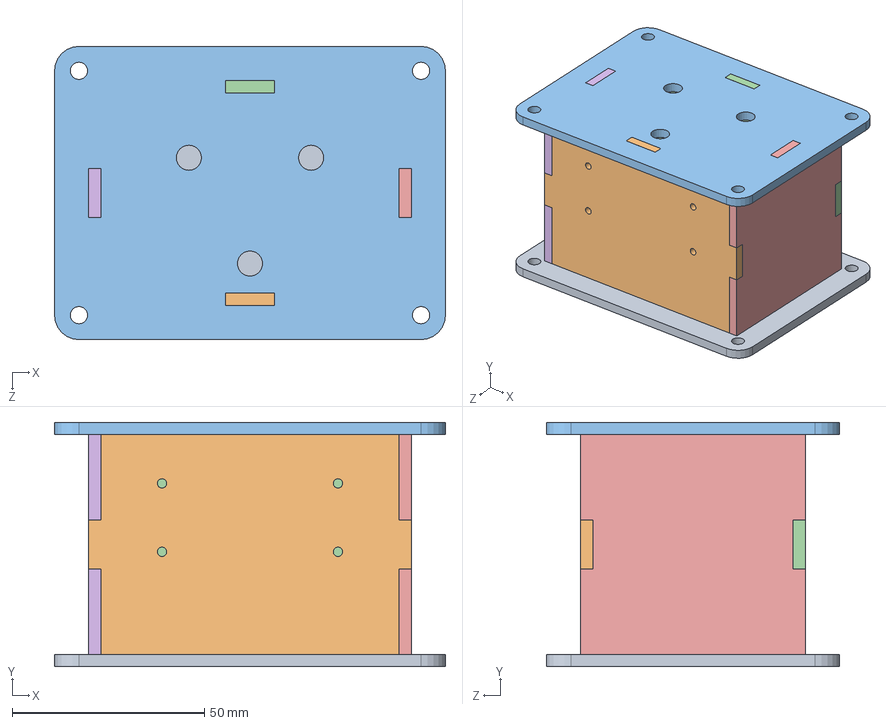
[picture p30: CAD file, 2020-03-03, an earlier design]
Fabrication/Old/Enclosure and Assembly/SolidWorks/Enclosure.SLDASM
101.6 x 63.5 x 76.2 mm
Bottom
Front
Top
Back
Left
Right

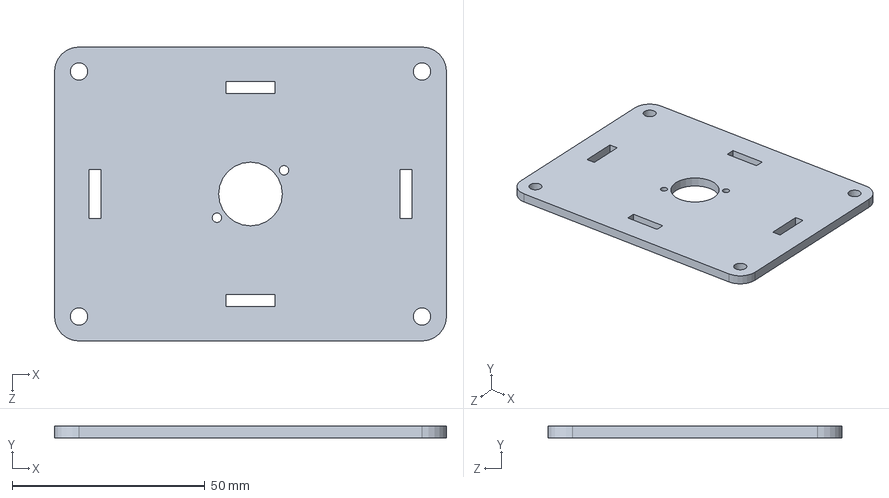
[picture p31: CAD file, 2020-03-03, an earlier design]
Fabrication/Old/Enclosure and Assembly/SolidWorks/Bottom.SLDPRT
101.6 x 3.17 x 76.2 mm

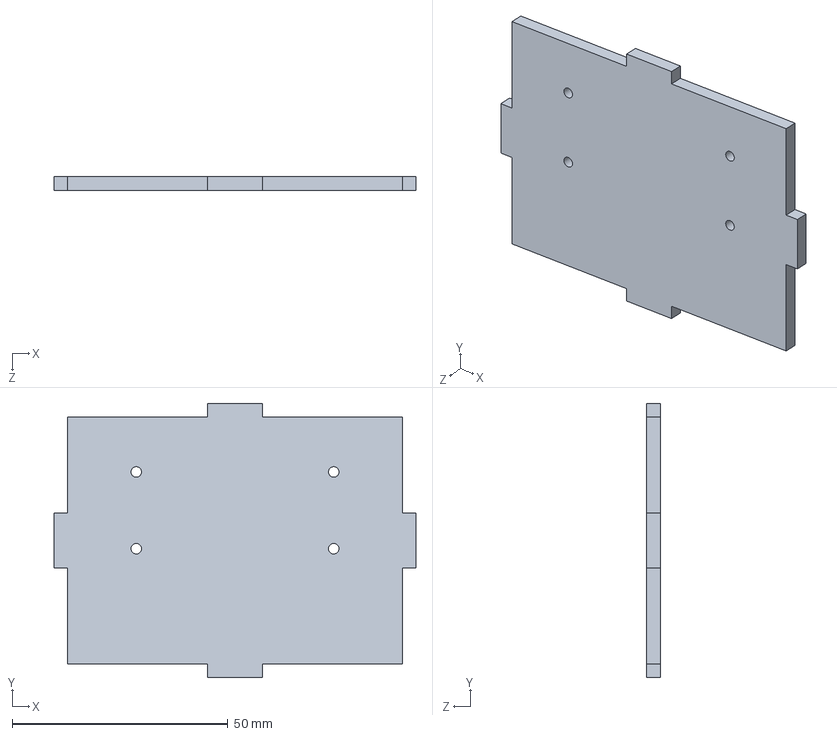
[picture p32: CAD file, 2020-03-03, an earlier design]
Fabrication/Old/Enclosure and Assembly/SolidWorks/Front.SLDPRT
83.8 x 63.5 x 3.17 mm

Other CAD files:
Fabrication/PVC-Enclosure/Enclosure-and-Assembly/Chassis_PVC_20240701(1).stl
Fabrication/Polycase-Enclosure/Enclosure-and-Assembly/Chassis_Polycase_Simplified_20240715.stl
Fabrication/Old/Enclosure and Assembly/SolidWorks/Back.SLDPRT
Fabrication/Old/Enclosure and Assembly/SolidWorks/Enclosure Drawing.SLDDRW
Fabrication/Old/Enclosure and Assembly/SolidWorks/Left.SLDPRT
Fabrication/Old/Enclosure and Assembly/SolidWorks/Right.SLDPRT
Fabrication/Old/Enclosure and Assembly/SolidWorks/Top.SLDPRT
Fabrication/PVC-Enclosure/Enclosure-and-Assembly/PVC-Chassis/Chassis_PVC.f3d
Fabrication/PVC-Enclosure/Enclosure-and-Assembly/PVC-End-Cap/PVCEndCap.ipt
Fabrication/PVC-Enclosure/Enclosure-and-Assembly/PVC-End-Caps/F3D/WaterLevel_BottomCap_ACL v2.f3d
Fabrication/PVC-Enclosure/Enclosure-and-Assembly/PVC-End-Caps/F3D/WaterLevel_Top v10.f3d
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

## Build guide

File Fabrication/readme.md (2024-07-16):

# What's in this `Fabrication` directory?
## Inside the "PVC-Enclosure" and "Polycase-Enclosure" folders, find:
- "BOM" (Bill of Materials) lists parts, costs, and where to purchase them.
- "Enclosure-and-Assembly" houses information about assembling the hardware for your sensor.
- "Datasheets" are documents from manufacturers that detail individual parts.

## What design should I use?
If you're deciding whether to proceed with a PVC or Polycase housing for your DIY sensor, we suggest exploring the folders in this directory to determine which design best fits your needs.

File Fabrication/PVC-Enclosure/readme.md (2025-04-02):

We're working on this page!
Come back soon for accurate step-by-step assembly instructions.

# How to assemble a DIY Open Water Level Sensor with a PVC enclosure
See:
- BOM, for bills of materials / lists of parts
- Datasheets, for manufacturer datasheets
- Enclosure and Assembly, for 3D print files

## Assembling the chassis
Parts:
- Boron 404X
- Adalogger FeatherWing
- MicroSD card
- Short stacking header pins
- 1.5” sch-40 330 psi PVC
- 3D printed custom chassis
- M2x0.4mm threaded 16mm screws
- M2x0.4mm 1.6mm hex nuts
- Cellular antenna
- Maxbotix Ultrasonic Rangefinder
- 3-pin cable
- Solar system
- USB A to Micro-B cable
- 1.5" gripper
- Pipe bushing
- Pipe coupling
- Pipe tape
- Epoxy

# Fabricating electronics to prepare for firmware update
1. Place the stacking header pins through the pin holes of the Adalogger FeatherWing; solder.

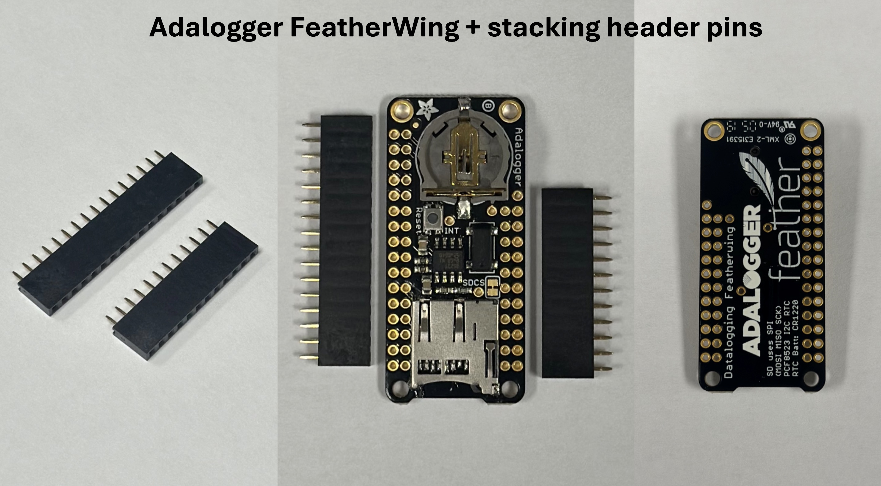
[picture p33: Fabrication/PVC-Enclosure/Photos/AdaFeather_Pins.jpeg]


2. Place the Boron 404X atop the Adalogger FeatherWing so the Boron pins fit into the stacking header holes. (The assembled Boron 404X, Adalogger FeatherWing, and stacking header pins will hereby referred to as the BAda.)
- MicroUSB connector
- O-rings
- Lithium Ion Battery Pack - 3.7V 4400mAh

1. Update Boron 404X system firmware to match current firmware as shown in the Firmware/target directory.

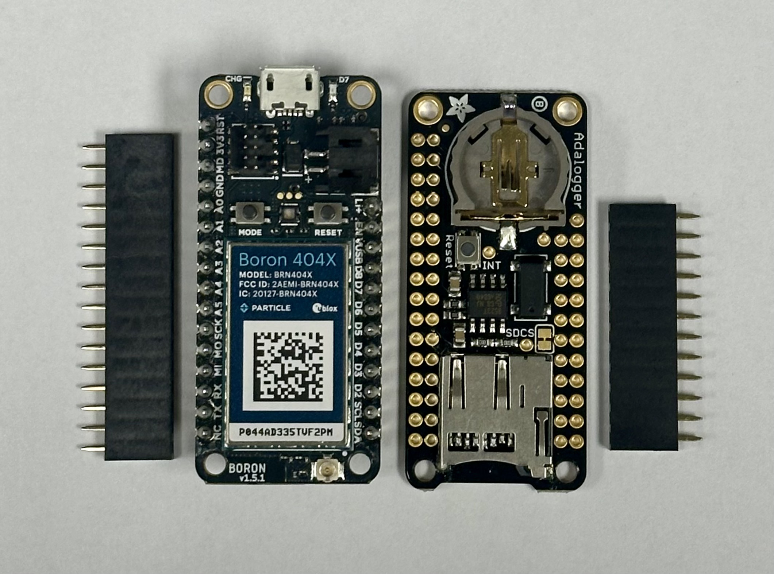
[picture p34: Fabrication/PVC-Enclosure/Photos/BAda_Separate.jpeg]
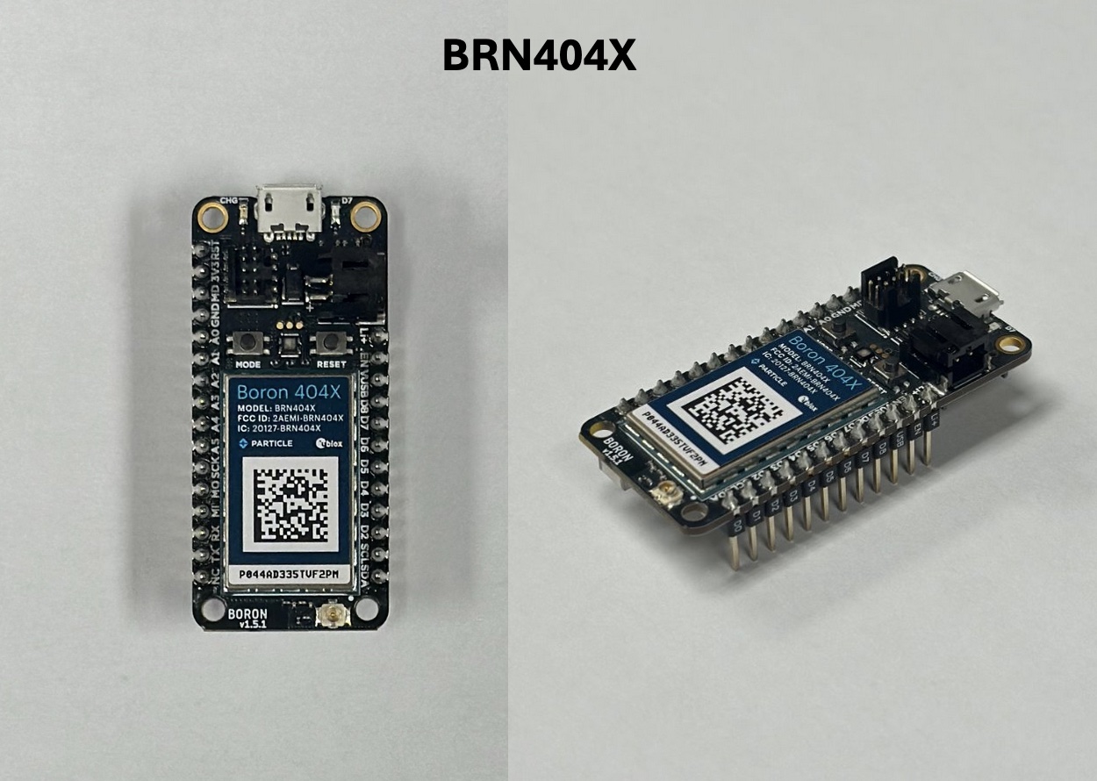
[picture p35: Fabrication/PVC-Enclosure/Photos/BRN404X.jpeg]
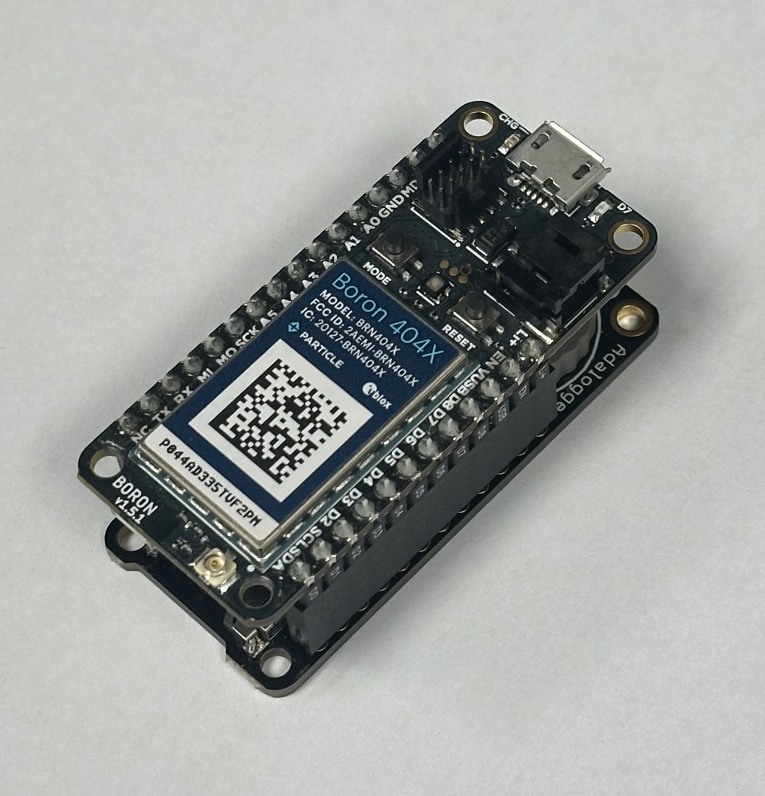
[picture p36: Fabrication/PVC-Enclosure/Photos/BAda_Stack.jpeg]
  

3. Gently press the microSD card into the Adalogger FeatherWing until it clicks into place.
2. Using epoxy, carefully glue four M2x0.4mm 1.6mm length hex nuts in the four hexagonal holes of the chassis. Let dry / cure fully.

3. Solder microUSB connector to solar cable with shrink tubing over the bare wire.

4. Stack short stacking header pins onto Adalogger FeatherWing; solder.



5. Insert microSD card into FeatherWing microSD port. (microSD card may need to be manually formatted by inserting it into your computer first.)

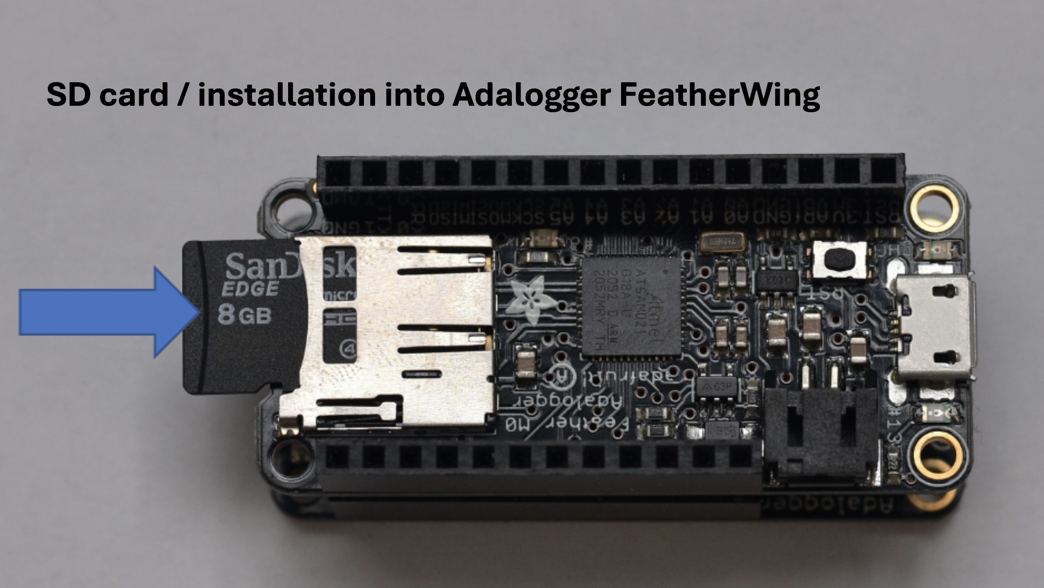
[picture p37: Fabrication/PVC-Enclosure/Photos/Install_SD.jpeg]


4. Using the USB A to Micro-B cable and your computer, udate the Boron's system firmware using the steps listed in the `Firmware` directory.

# Fabrication of electronics with enclosure

*Note: Start by taking the Boron off the Adalogger FeatherWing for ease.*
8. Stack Boron 404X on FeatherWing; solder.

1. Using epoxy, carefully glue four M2x0.4mm 1.6mm length hex nuts in the four hexagonal holes of the chassis. Let dry / cure fully.

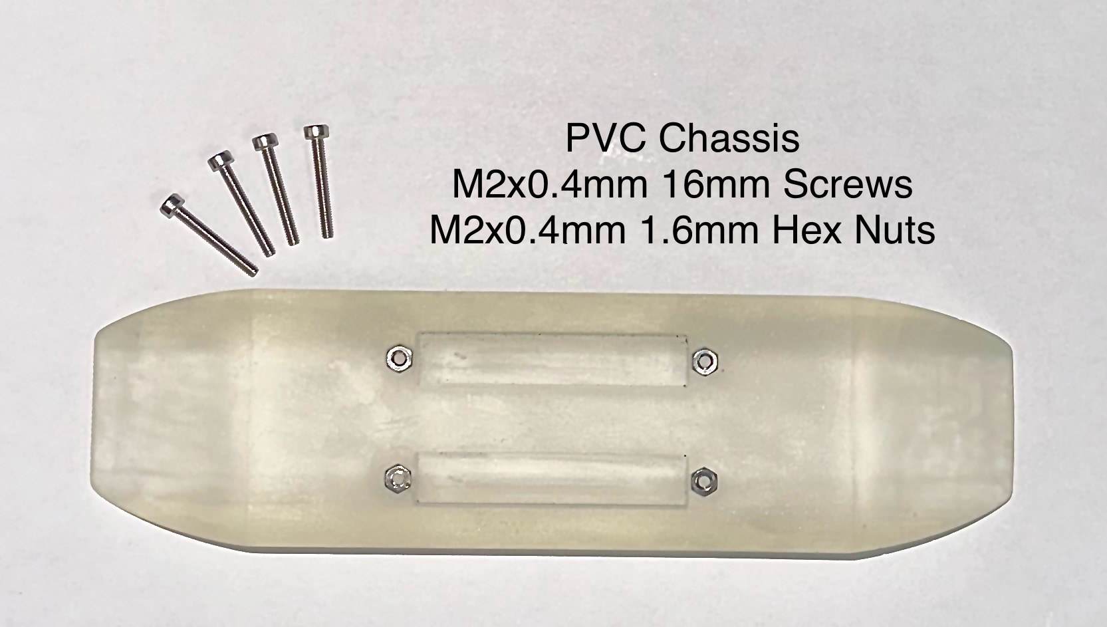
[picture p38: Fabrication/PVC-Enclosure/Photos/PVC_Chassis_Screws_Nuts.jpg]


Optional: Twist the 3-pin cables (insert into a drill bit and spin slowly). Use shrink tubing to cover the cables.
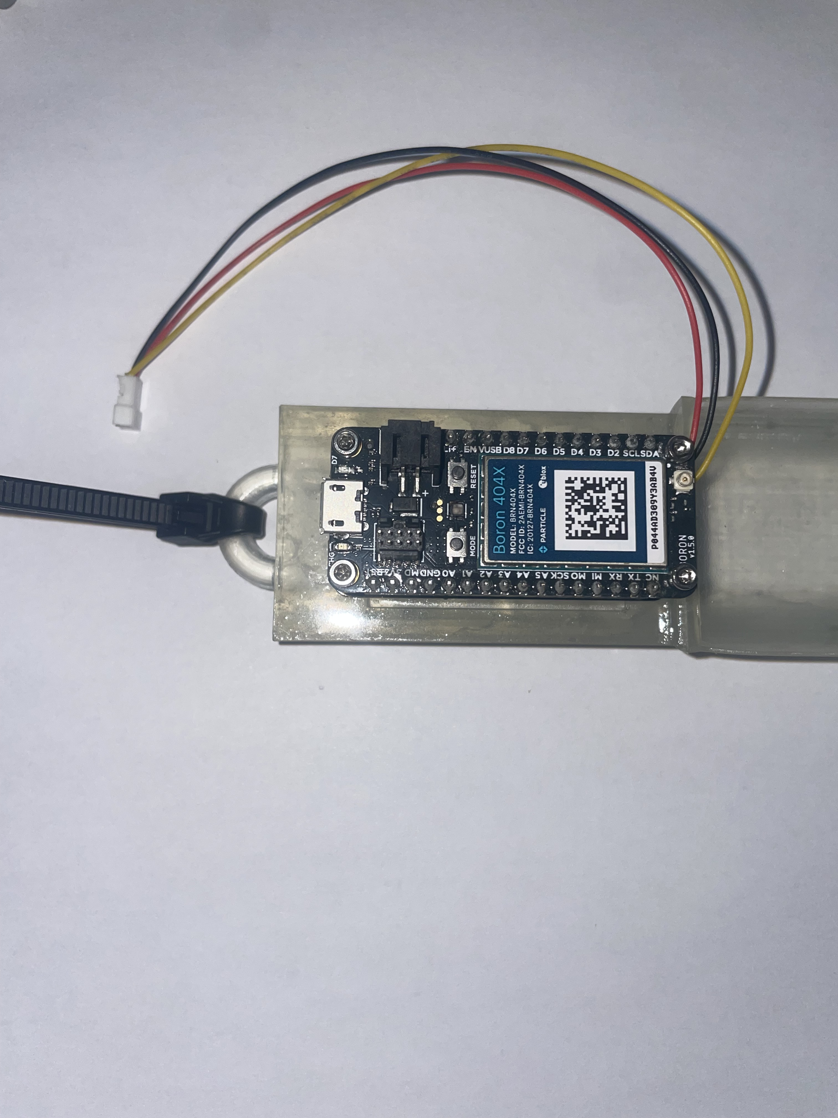
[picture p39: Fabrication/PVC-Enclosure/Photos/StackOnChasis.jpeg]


2. Solder the 3-pin cable female receptacle onto the FeatherWing spare pins corresponding to the power, ground, and analog inputs.

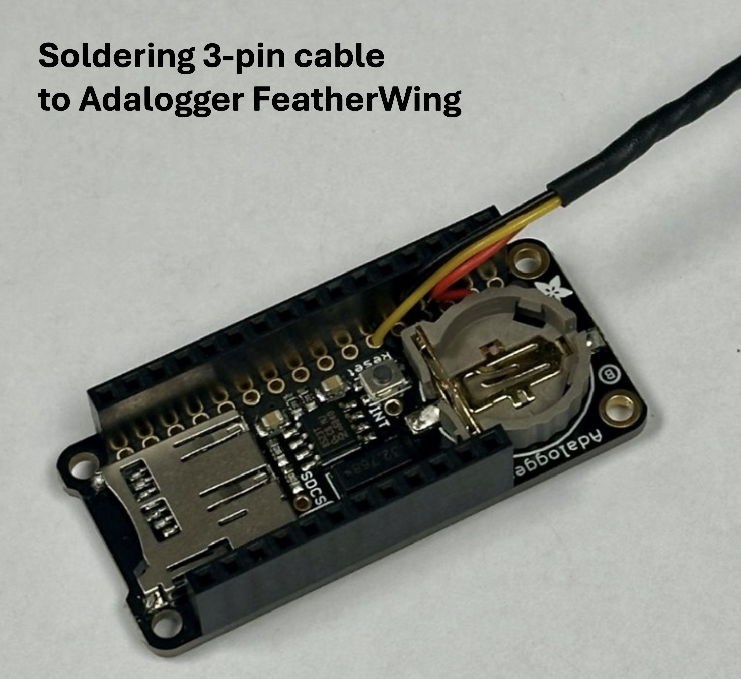
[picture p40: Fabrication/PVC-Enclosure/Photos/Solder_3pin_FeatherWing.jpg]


3. Solder the 3-pin cable male block onto the ultrasonic distance sensor on pins corresponding to the power, ground, and analog outputs.

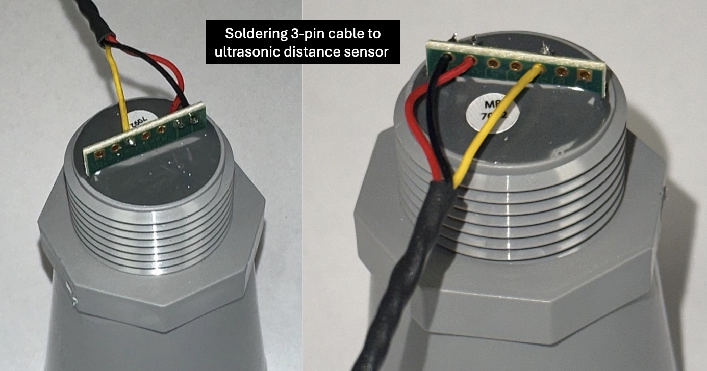
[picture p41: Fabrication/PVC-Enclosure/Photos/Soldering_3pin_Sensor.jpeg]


4. Using M2x0.4mm screws, attach the BAda atop the chassis so that ...
- ... the soldered header pins rest in the rectangular slots without touching anything
- ... the screw holes in the Boron and FeatherWing line up with the four hex nuts in the chassis

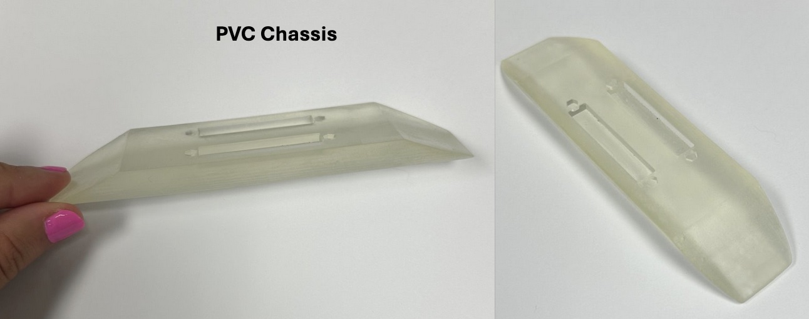
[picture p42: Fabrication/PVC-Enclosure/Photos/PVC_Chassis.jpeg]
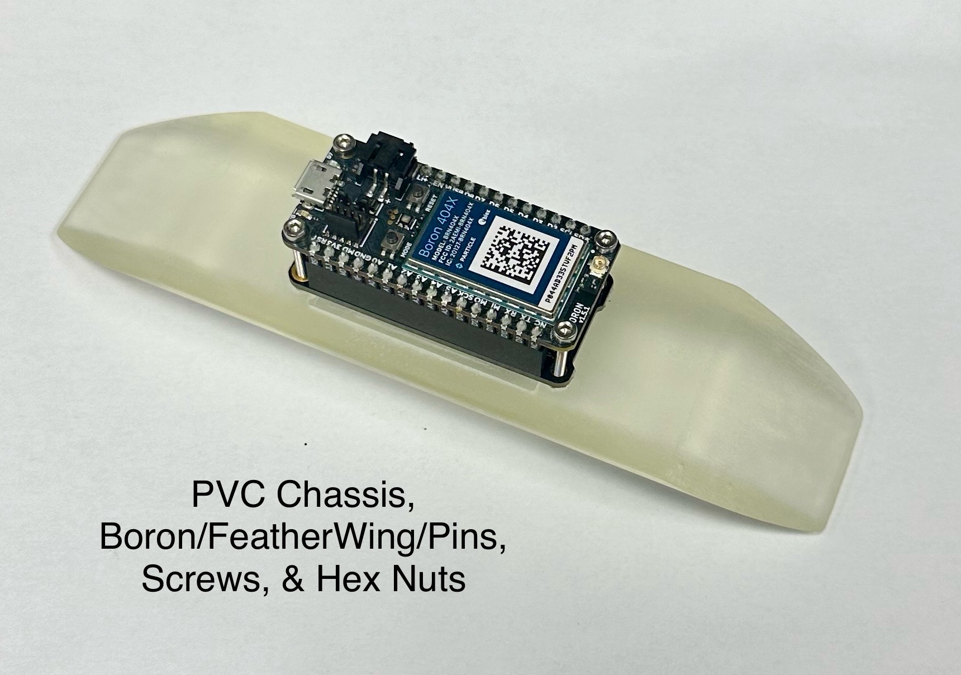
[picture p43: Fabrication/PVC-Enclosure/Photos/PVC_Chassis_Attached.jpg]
 

5. Attach cellular antenna cable to Boron 404X.

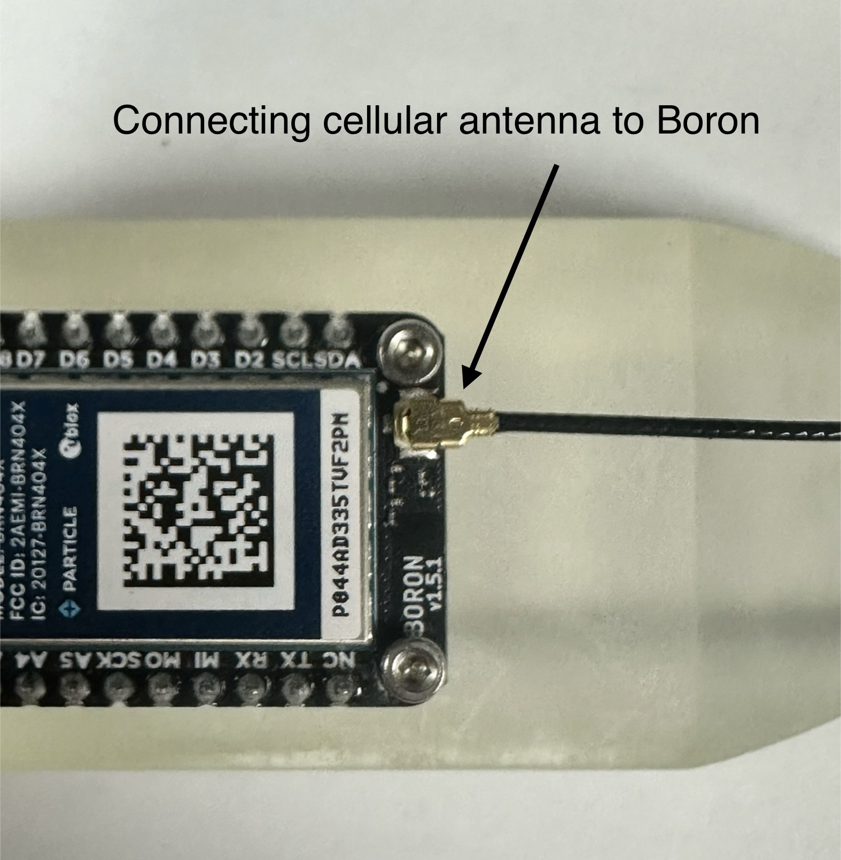
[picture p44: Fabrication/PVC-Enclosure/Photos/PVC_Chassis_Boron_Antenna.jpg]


6. Peel sticker backing off of cellular antenna and gently stick to flat underside of chassis.

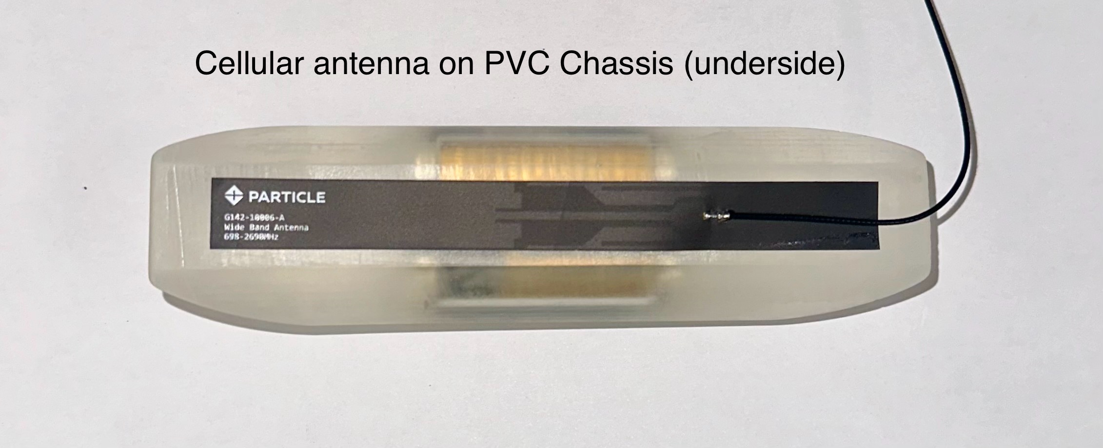
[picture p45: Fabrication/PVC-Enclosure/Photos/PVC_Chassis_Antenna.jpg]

12. Attach the lithium battery to the slot under the Boron/FeatherWing stack.

13. Attach a zip tie to designated hook on the chasis. This will help with electronic removal from within the PVC pipe.

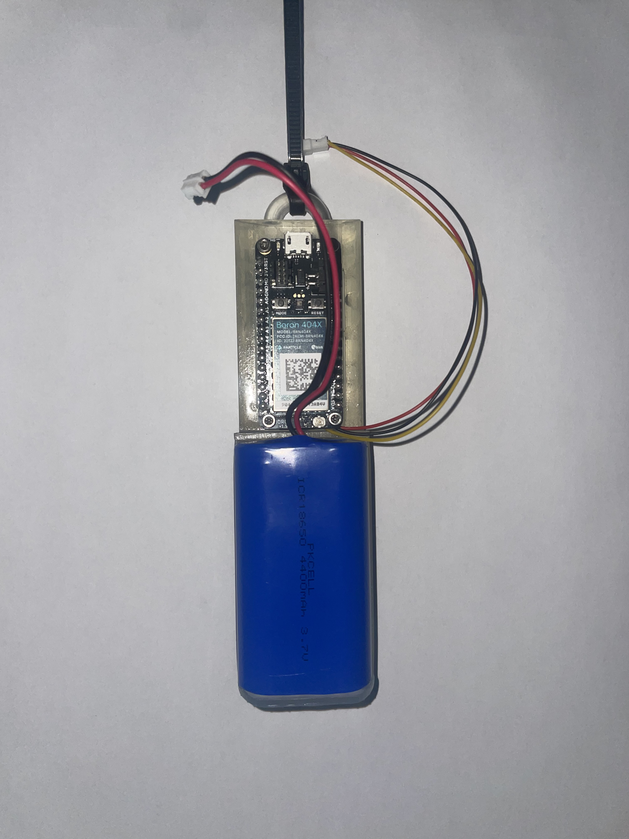
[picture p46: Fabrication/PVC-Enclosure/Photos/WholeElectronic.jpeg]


7. Chop 1.5" sch-40 PVC into an 8" section.

8. Drill a 9/64" hole 5cm from top of an 8" PVC section (this hole will be for solar panel cable).

9. Cut the female 5V 2A connector off of the solar cable and feed it through the 9/64" hole so the stripped end is inside the PVC pipe.
 
10. Cut the USB A connector of the USB A to Micro-B cable and strip the end.

11. Solder the +5V wires and GND wires of the USB and solar cables together. (Can use shrink tubing to keep red and black internal wires separate). Cover this connection with shrink tubing / electrical tape / your preference.

12. Plug the Micro-B connector into the Boron's Micro-B port.

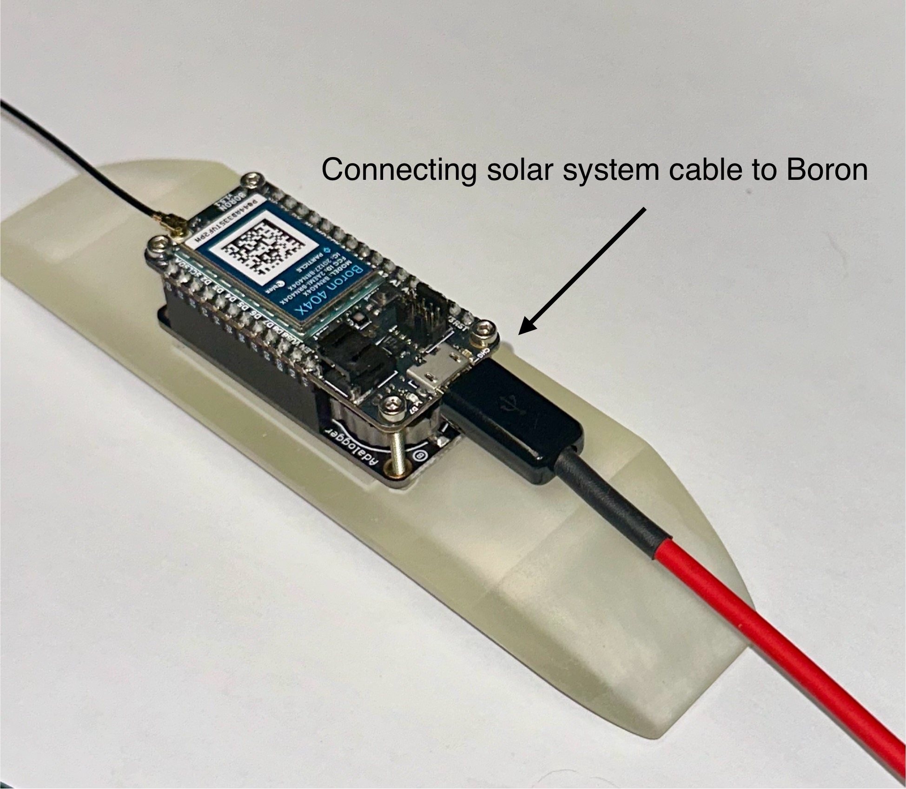
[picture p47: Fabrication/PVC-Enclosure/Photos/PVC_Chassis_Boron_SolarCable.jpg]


## Assembling the PVC enclosure
Parts:
- 1.5” sch-40 330 psi PVC
- PVC coupler
- PVC reducer
- Maxbotix Ultrasonic Rangefinder
- Solar system
- Silicon grease
- Silicon sealant
- PVC cement
- PVC pipe tape
- Assembled chassis with electronics
- 3D printed PVC Cap

1. Chop 1.5" sch-40 PVC into 8" sections.
2. Designate one side for the solar cable connection and one for the coupler and MaxSonar
3. The side you have designated for the solar cable connection slightly shave down the internal edge. 
4. On the PVC printed end cap attach the cable gland. Run the spliced solar cable through this cable gland.
5. Using silicon grease carefully place O-rings onto designated grooves on end cap. Be sure to wipe the o-rings and grooves with a Kim wipe to remove any particles or lint before adding grease.
6. Place cap, with o-rings and cable gland, onto desginated end.

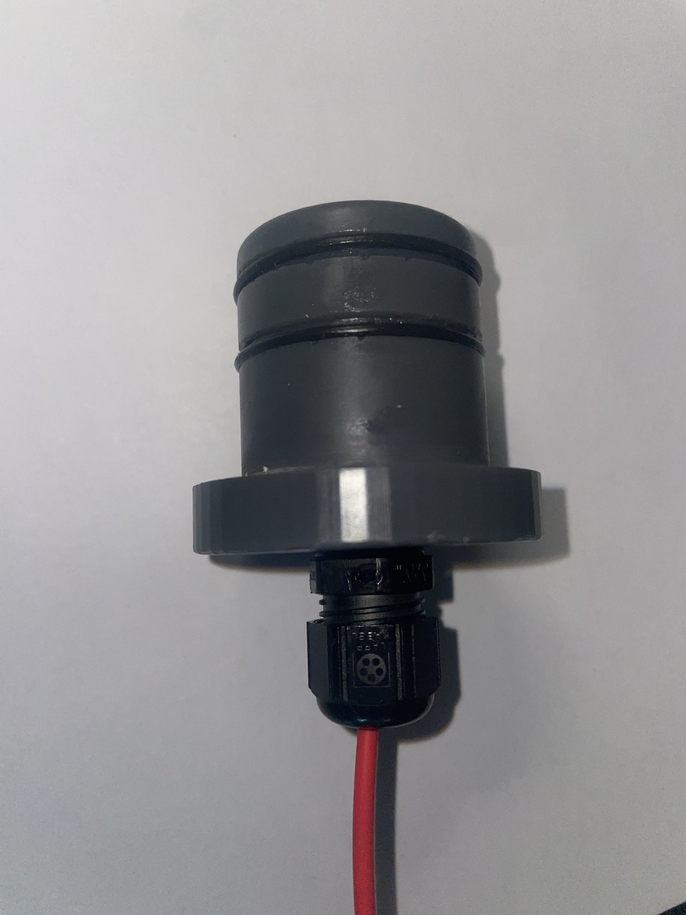
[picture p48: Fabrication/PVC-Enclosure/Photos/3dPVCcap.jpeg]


7. Put coupler and PVC Reducer Bushing together
   
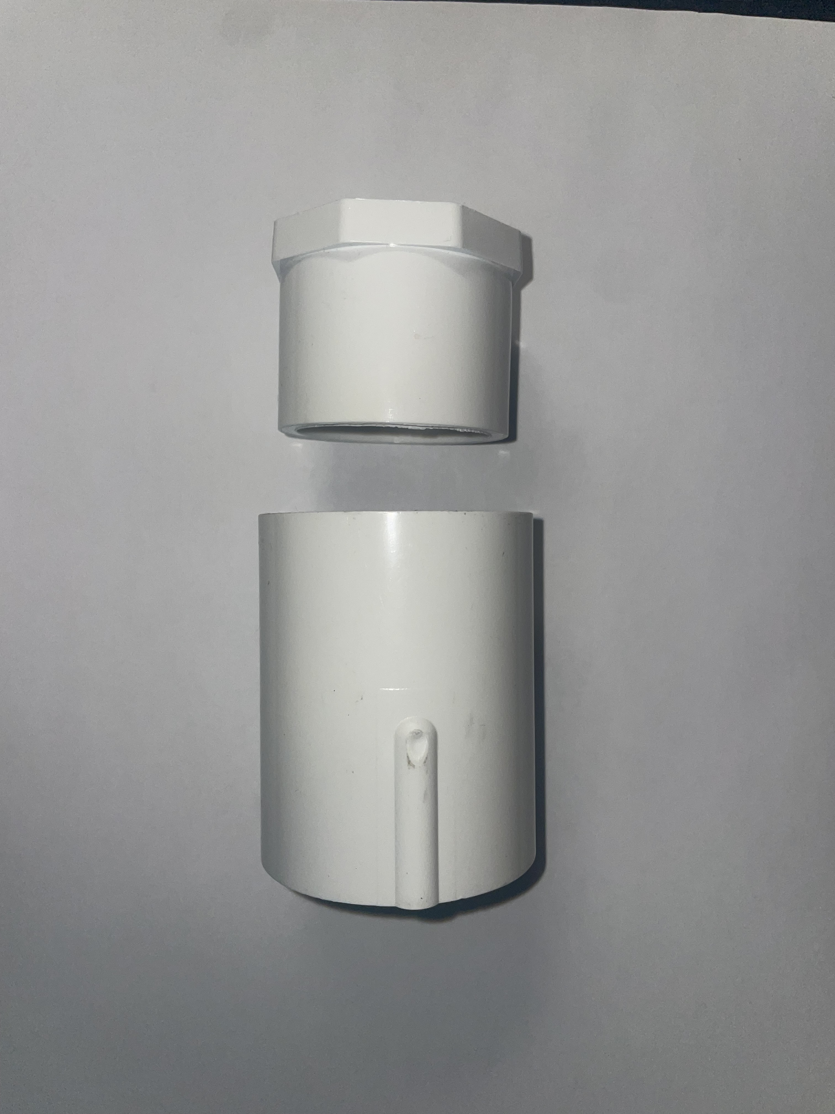
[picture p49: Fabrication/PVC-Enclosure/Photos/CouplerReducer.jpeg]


**Deployment (more details found in Deployment Folder)**
   
8. Wrap Maxsonar threads with PVC pipe tape (only usable for one entry and removal). Attach coupler/reducer part with MaxSonar.

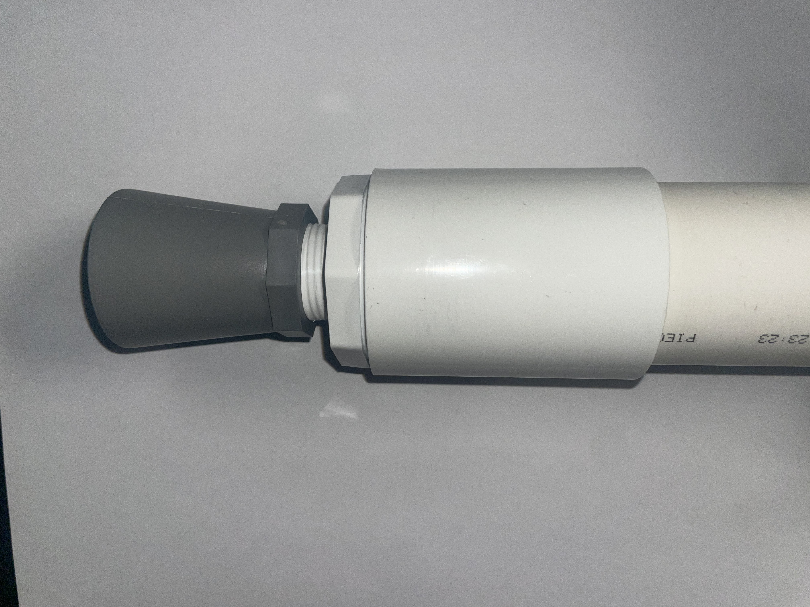
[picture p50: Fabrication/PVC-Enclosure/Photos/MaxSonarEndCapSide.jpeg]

    
9. Attach solar cable to Boron; Attach 3 pin on stack to Maxsonar 3-pin. Connect 3-pin wire between Boron stack and Maxsonar; slide chassis and electronics into PVC pipe. 

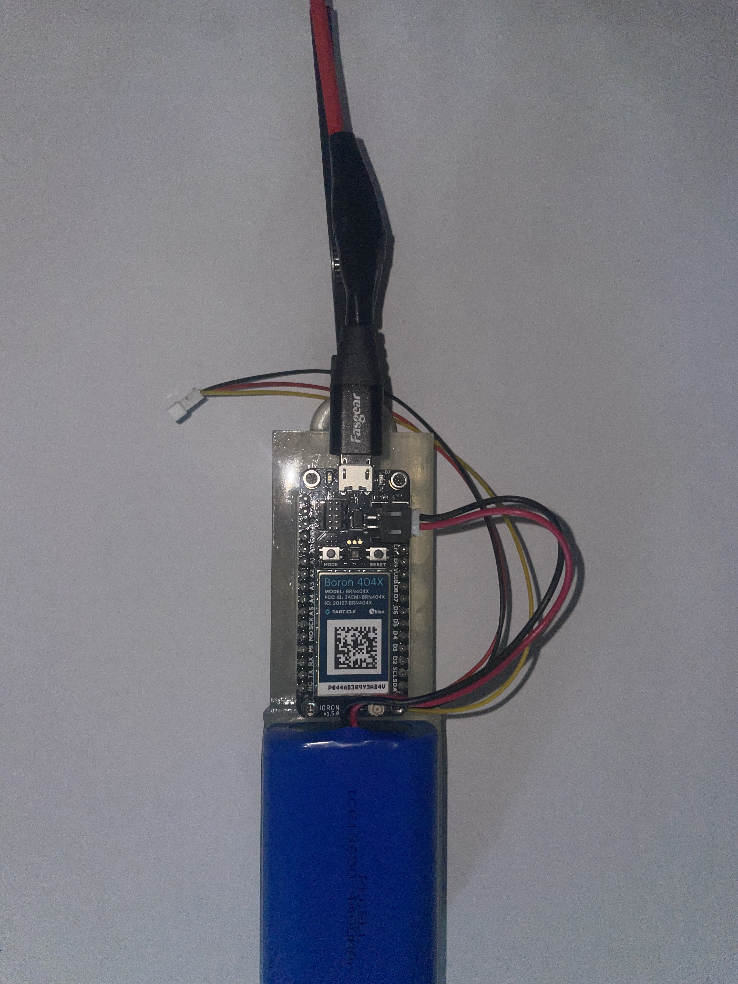
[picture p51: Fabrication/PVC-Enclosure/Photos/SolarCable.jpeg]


10. We recommend including electrical tape to secure the antenna and 3 pin wires to the side of the chassis. This will help decrease any noise and movement within the PVC during deployment. 

11. Once everything is inside of the PVC pipe and you are ready for deployment, grab the silicon sealant and PVC cement.
    
12. Using silicon sealant, seal where the PVC 3D cap directly meets PVC pipe, seal around the cable gland o-ring too.

13. Lastly, using PVC cement, seal the space between the coupler and PVC pipe. 

14. Wrap the ultrasonic distance sensor's threads with pipe tape; gently screw the distance sensor into pipe bushing.

15. Using the pipe coupling, connect the pipe bushing (with distance sensor) and the PVC pipe. Make sure you connect the white cap ends of the 3-pin cables inside the enclosure.

16. Seal the opposite PVC end with the 1.5" gripper.

17. Seal the solar cable entry hole with silicon sealant to prevent water damage.

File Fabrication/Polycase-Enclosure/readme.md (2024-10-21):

# How to assemble a DIY Open Water Level Sensor with a Polycase enclosure

See:
- BOM, for full bill of materials
- Datasheets, for manufacturer datasheets
- Enclosure and Assembly, for 3D print files

Parts:
- Boron 404X
- Adalogger FeatherWing
- MicroSD card
- Short stacking header pins
- 3D printed custom chassis
- M2.5x0.45 screws/hex nuts
- Cellular antenna
- Polycase ML-24K + screws (included)
- Hi-Lo #4-24 screws
- Maxbotix Ultrasonic Rangefinder
- 3-pin cable
- Solar system
- USB A to Micro-B cable
- Pipe tape
- Epoxy

# Fabricating electronics to prepare for firmware update

1. Place the stacking header pins through the pin holes of the Adalogger FeatherWing; solder.



2. Place the Boron 404X atop the Adalogger FeatherWing so the Boron pins fit into the stacking header holes.

  

3. Gently press the microSD card into the Adalogger FeatherWing until it clicks into place.



4. Using the USB A to Micro-B cable and your computer, udate the Boron's system firmware using the steps listed in the `Firmware` directory.

# Fabrication of electronics with enclosure

*Note: Start by taking the Boron off the Adalogger FeatherWing for ease.*

Optional: Twist the 3-pin cables (insert into a drill bit and spin slowly). Use shrink tubing to cover the cables.

1. Solder the 3-pin cable female receptacle onto the FeatherWing spare pins corresponding to the power, ground, and analog inputs.



2. Solder the 3-pin cable male block onto the ultrasonic distance sensor on pins corresponding to the power, ground, and analog outputs.



3. Using a 5/8" spade bit, drill a hole in one of the Polycase's short ends 3/4" from the inner lip and centered horizontally.

4. Cut a 1" hole 1-1/4" into the Polycase lid. Tap 3/4 NPT threads

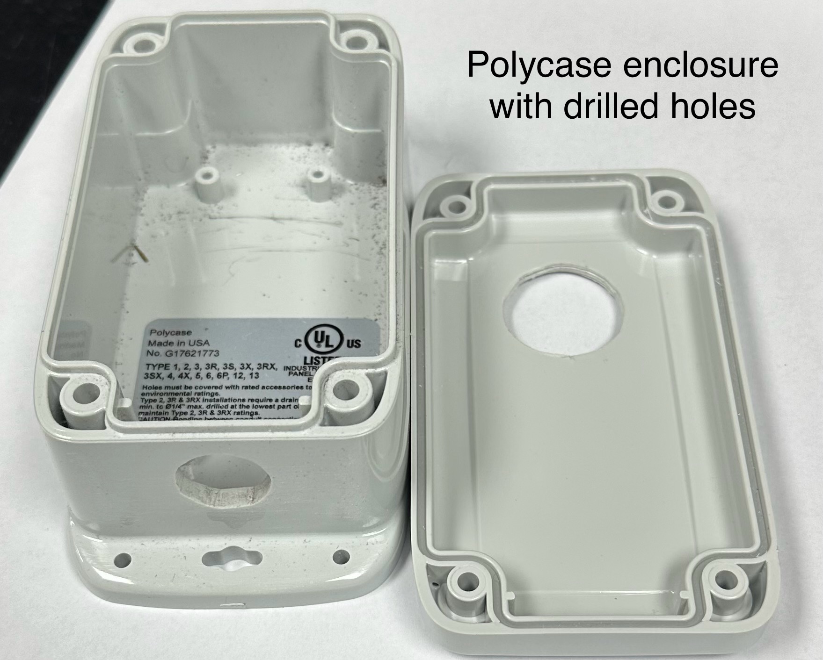
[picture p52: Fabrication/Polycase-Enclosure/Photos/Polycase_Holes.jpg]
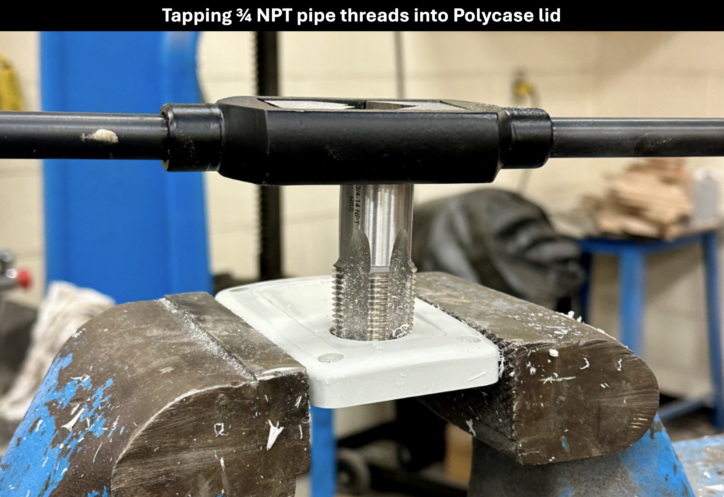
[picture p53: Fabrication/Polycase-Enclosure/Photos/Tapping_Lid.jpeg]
 

5. Wrap the ultrasonic distance sensor's threads with pipe tape; gently screw the distance sensor into the lid's hole. Use marine epoxy to create a waterproof connection here.

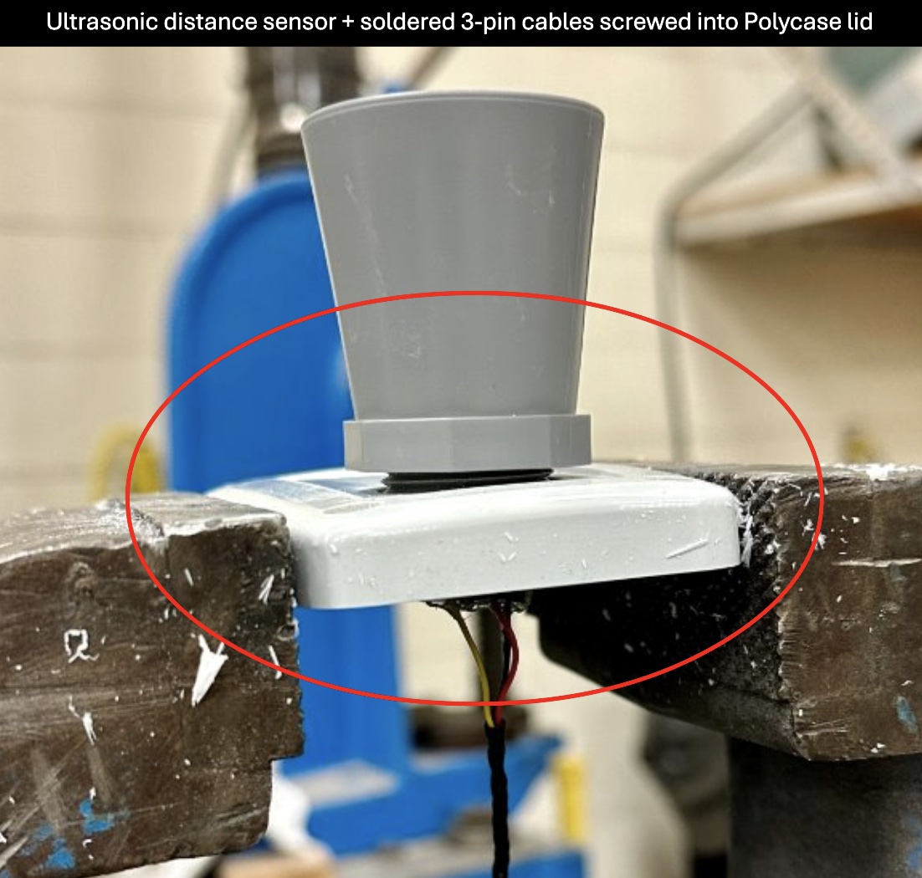
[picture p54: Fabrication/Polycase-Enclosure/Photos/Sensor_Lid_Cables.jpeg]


6. Cut the female 5V 2A connector of of the solar cable and strip the end. Cut the USB A connector of the USB A to Micro-B cable and strip the end. Solder the +5V wires together and the GND wires together. (Can use shrink tubing to keep red and black internal wires separate.) Cover this connection with shrink tubing / electrical tape / your preference.

7. Thread the upper two components of the cable gland onto the solar cable. Thread the solar cable through the 5/8" hole. Thread the bottom component of the cable gland onto the solar cable from inside the enclosure. Tighten cable gland.

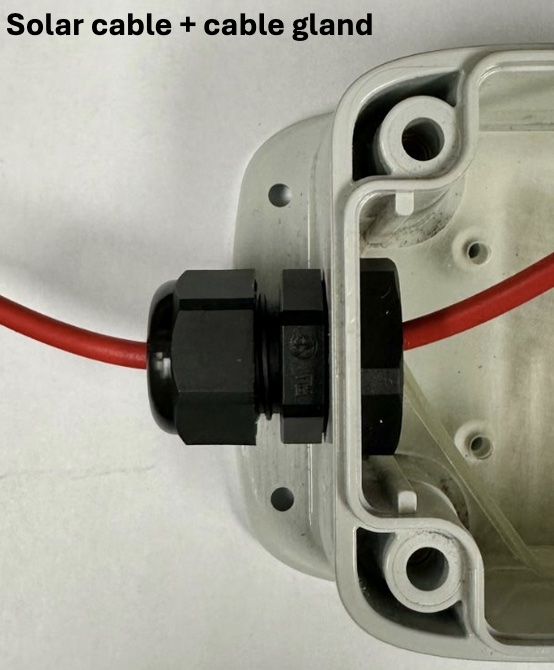
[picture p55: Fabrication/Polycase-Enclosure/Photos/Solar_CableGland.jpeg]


# Assembling the Chassis

1. Lay the Boron 404X and Adalogger FeatherWing with soldered header pins (hereby referred to as the BAda) atop the chassis so that the ...
- pins fit in the rectangular slots
- four holes in the BAda corners align with the four small holes in the chassis
- the microUSB port and 3-pin cable of the BAda are facing the end of the chassis with more lengthwise space

2. Screw the BAda to the chassis using the M2x0.45 18mm screws. Screw M2.5x0.45mm threaded 2mm length hex nuts to the screws on the underside of the chassis.
- Be cautious not to move too quickly or harshly, as you can strip the screw / hex nut, or crack the chassis!

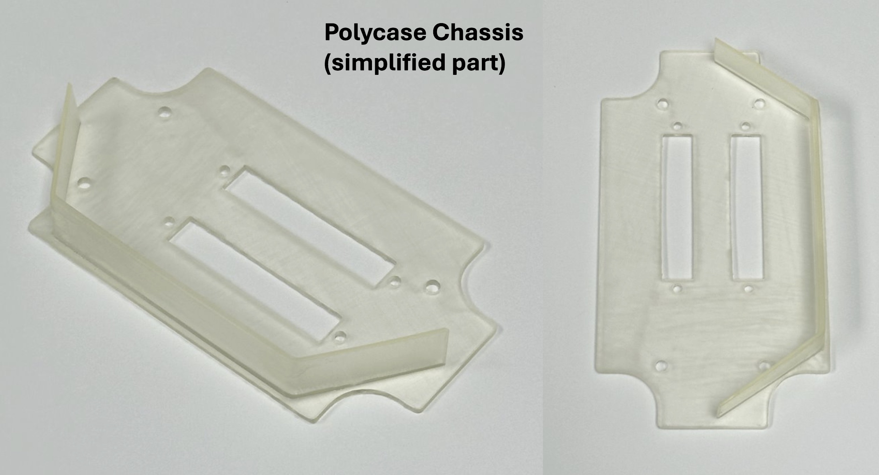
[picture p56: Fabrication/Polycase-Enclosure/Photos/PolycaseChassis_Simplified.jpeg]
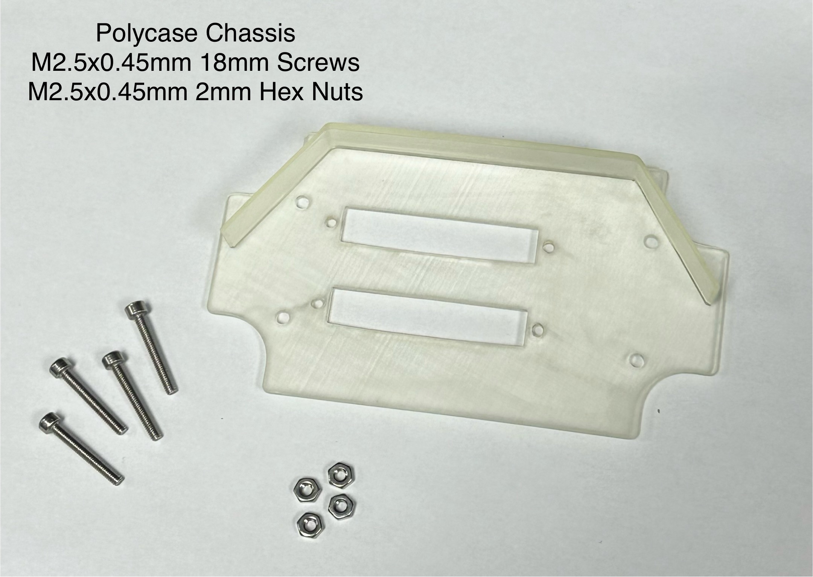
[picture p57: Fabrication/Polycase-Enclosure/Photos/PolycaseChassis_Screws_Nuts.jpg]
 
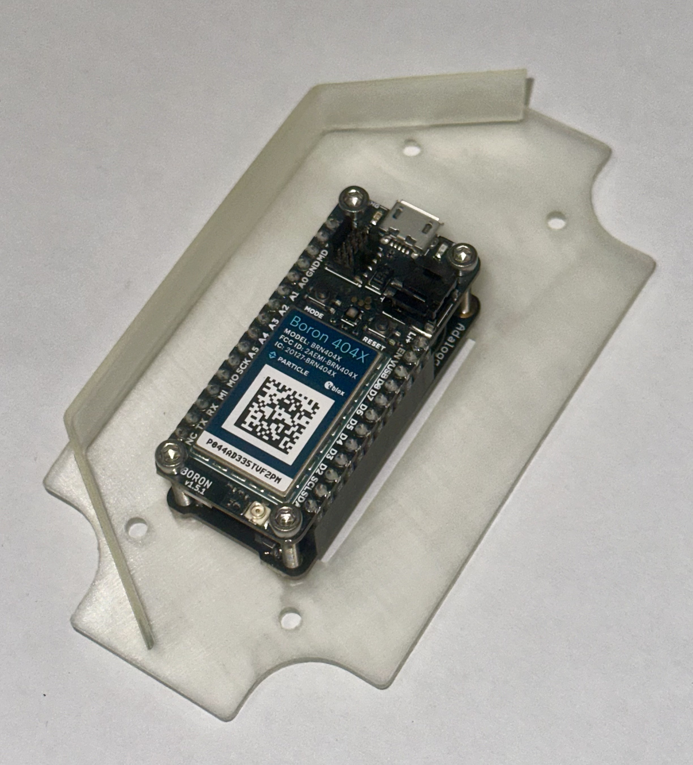
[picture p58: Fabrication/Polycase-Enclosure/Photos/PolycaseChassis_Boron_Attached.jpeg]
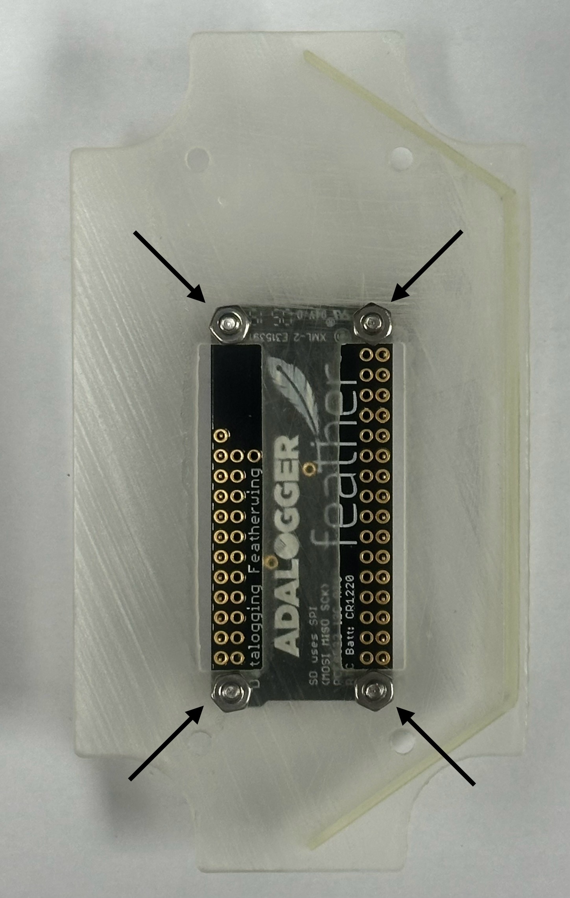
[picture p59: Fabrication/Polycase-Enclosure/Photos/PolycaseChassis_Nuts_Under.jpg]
 

3. Carefully peel the sticker backing off of the cellular antenna and gently stick to the outside of the antenna frame on the chassis. Attach the antenna cable to the BAda.

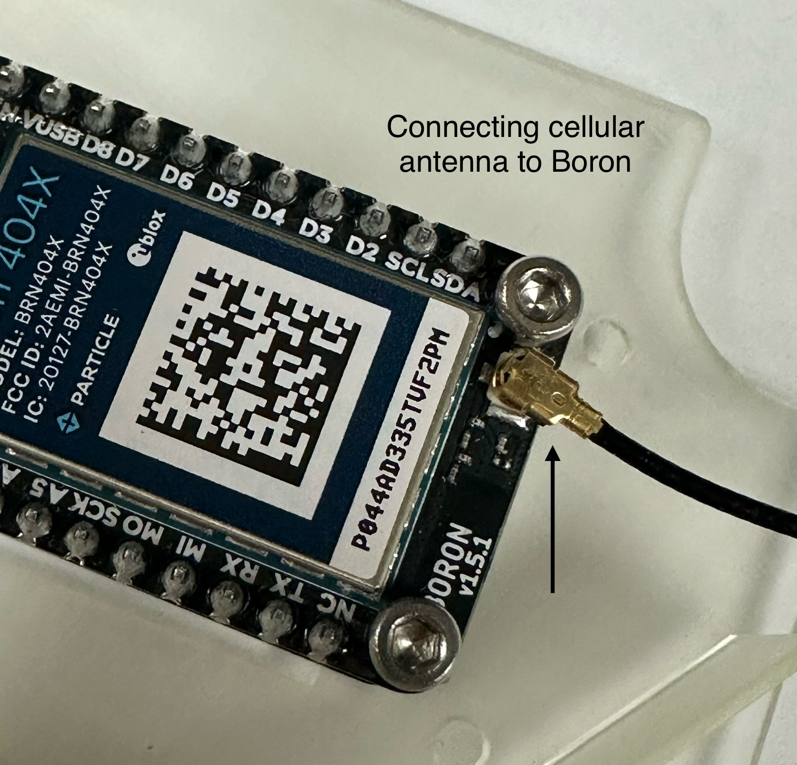
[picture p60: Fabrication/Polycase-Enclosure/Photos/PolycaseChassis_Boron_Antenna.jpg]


4. Lay the chassis and electronics inside the Polycase so the BAda's microUSB port faces the side with the solar cable entry / cable gland.

5. Plug the microUSB solar cable into the port.

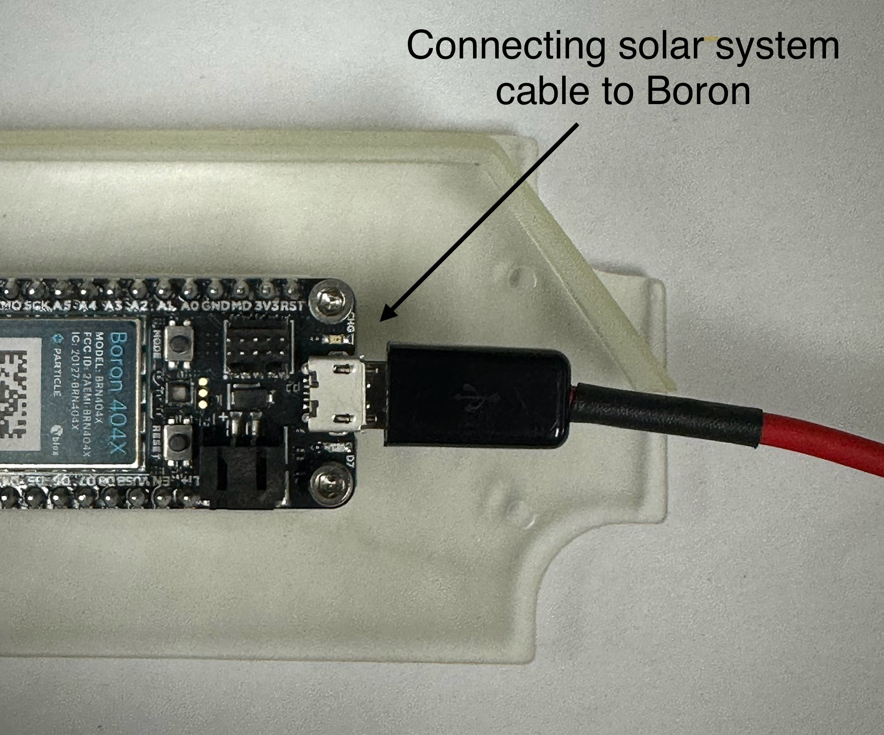
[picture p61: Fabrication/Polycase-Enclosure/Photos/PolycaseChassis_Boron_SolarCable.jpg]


6. Screw the chassis with attached electronics into the Polycase using the Hi-Lo screws.
- Move with caution so as not to cause stripping!

7. Connect the white cap ends of the 3-pin cables.

8. Carefully fit all cords into the Polycase enclosure.

9. Place the Polycase lid on the enclosure, screwing it on with the included screws.

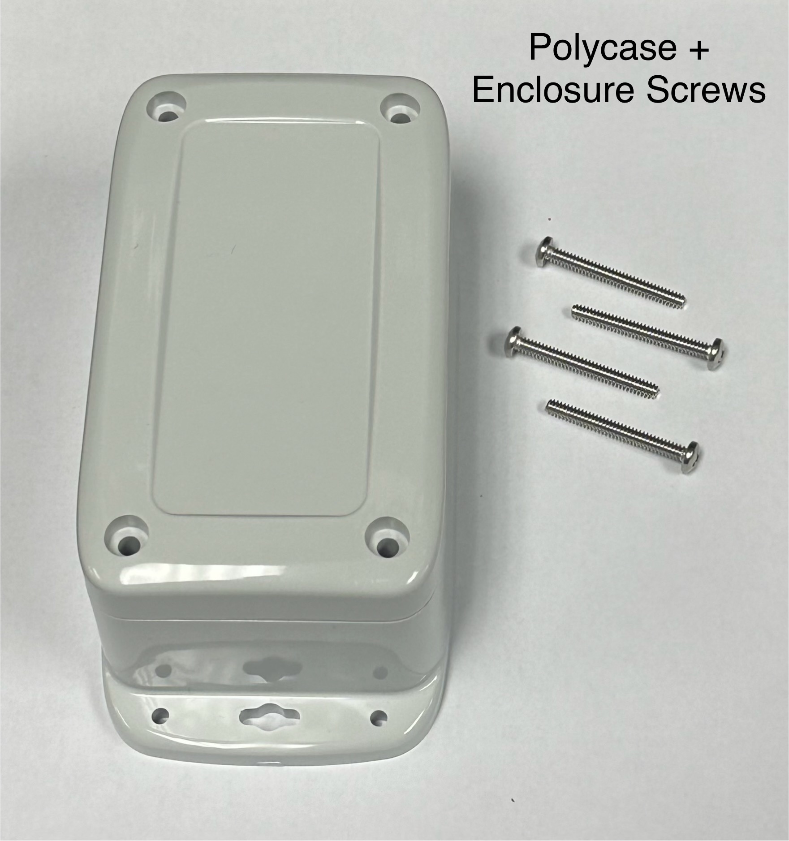
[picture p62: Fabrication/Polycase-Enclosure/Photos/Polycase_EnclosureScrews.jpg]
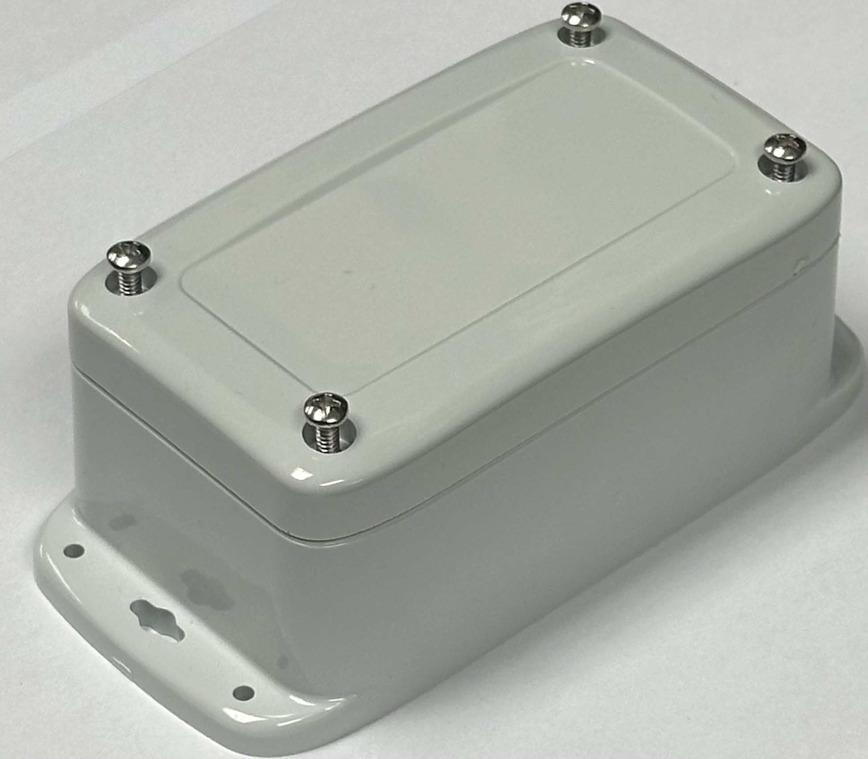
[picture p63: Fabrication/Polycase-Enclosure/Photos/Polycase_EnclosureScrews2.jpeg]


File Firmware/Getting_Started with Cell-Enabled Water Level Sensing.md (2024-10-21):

# Getting Started with Cell-Enabled Water Level Sensing
## Particle and Visual Studio
This section will help you set up Visual Studio Code and Particle Workbench, two important platforms you'll need for the following exercises.

1. Download Visual Studio (the one with the blue icon, not purple) [here](https://code.visualstudio.com/).
2. Download Particle Workbench [here](https://www.particle.io/workbench/) and create an account using your email address of choice (select 'Education' for account type if applicable). Make sure you have Visual Studio installed prior to running the installer.
	- The installer says that it will install Visual Studio (VS) along with Particle, but this does not work properly and will fail if VS is not installed first.
3. Log into Particle on Visual Studio if it doesn’t automatically (this is important because you won’t be able to install necessary libraries without being logged in).

## Useful features
This section lists some commands and programming features that will be helpful in the following exercises.

1. Open the Particle Command Palette: Ctrl+Shift+P on Windows; or Command+Shift+P on Mac; or select the 'view' tab -> Command Palette; or click the 'Launch Command Palette' button on the 'welcome' tab).
2. In the top right corner, there are some important symbols in white circles:
	- Compile: checkmark
	- Flash: lightning bolt
3. These symbols will be used later to compile and flash code (i.e. importing code to the Boron device).
4. Save your projects frequently using Ctrl+S on Windows or Command+S on Mac. Make sure your directories are exactly how you want them to avoid pathway issues in your coding projects!
5. Keep this in your back pocket, but don't use it yet: in cases where the Boron stops responding as expected or displaying error LED sequences, you may need to restore the device. Particle has an online, USB-based option here: [https://docs.particle.io/tools/device-restore/device-restore-usb/](https://docs.particle.io/tools/device-restore/device-restore-usb/).

## Common problems
This section lists some common problems you may encounter in the following exercises and how to address them.

Skip this section for now and try the **Practice Code with Boron** section first. Refer back to this list if you encounter problems.
1. If you receive a "No Device Found" or "Serial Time Out" message when using "Particle: Identify" ... First, double-check that you have selected Boron in the bottom right bar, have selected the correct OS version (for me, it is 4.2.0), and put the device in listening mode (by pressing and holding the Mode button until the LED blinks blue). If those settings are correct but you're still having issues, try unplugging/replugging the device or restarting VS and/or your computer.
2. If you have problems in **Practice code with Boron and Adalogger** ... If Initializing SD Card and initialization failed, check that the micro SD card is empty. Plug it into your computer, open the SD card, and delete every file on it.
3. If met with unsuccessful compiling and a message stating that your file is dirty, try accepting the offer to 'clean' your file. If this doesn't fix the issue, try closing VS, deleting the project from your computer, and starting over.

## Practice code with Boron
This section will take you through an exercise to set up your Boron device and practice using code with it.

1. Plug in the Boron device to your computer using a micro-USB cable. Visit [https://docs.particle.io/tools/device-restore/device-restore-usb/](https://docs.particle.io/tools/device-restore/device-restore-usb/) and click 'Select Device.' Restore to the default system firmware version matching the example (not 'custom user firmware') and set the current compiled [target](SLR_Boron_Maxbotix_MB7092_cm/target) to be 4.2.0 (this is the version I am using).
	- Note: If you get the message `Could not identify device: No serial port identified` but the Boron powers up, ensure that your cable has data transfer capabilities (many are only capable of charging). Or, if no device is found using the device restore page, Put the Boron into DFU (Device Firmware Update) mode by pressing and holding the 'Mode' button on the Boron while simultaneously pressing and releasing the 'Reset' button.
2. Create a folder on your computer to store Particle-related items (no spaces in the title; use underscores (_) ... something like Particle_Items).
3. Create a new project by opening the Particle Command Palette (see: 'Useful features') and selecting 'Particle: Create New Project.' You can also click the blue text that says 'Create New Project' on the welcome page under Development Workflow -> Code.
4. Choose the folder you just made on your computer for this class when asked to choose the 'parent' folder.
5. Once you have the directory in which you want to store your Particle projects, create a project name (no spaces) ... Something like Blink_LED.
6. Copy the code from the file named `Blink_LED.ino` (not the one you just made but from the example [here](https://github.com/SUPScientist/Smart-Coasts/blob/main/Class-01-Intro/Blink_LED.ino)).
7. Navigate to the .cpp file that is generated for your new project under the 'src' tab on the left-hand side of screen (under 'explorer').
8. Delete all the text in the .cpp file after line 10 and paste the code you just copied.
	- Note: Make sure you leave lines 9-10 (seen below), as your .cpp file will not run properly without line 10. <br />
`// Include Particle Device OS APIs` <br />
`#include "Particle.h"`
	- Optional: Fill in lines 2-4 of the .cpp file (i.e. project name, author name, date); this info is for organizational purposes and will not affect your code if you leave it blank.

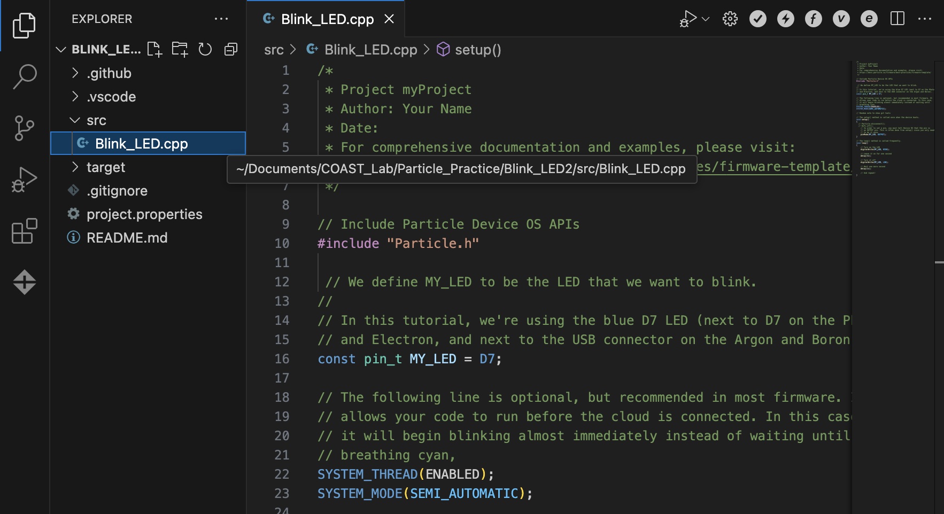
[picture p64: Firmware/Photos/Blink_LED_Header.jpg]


9. Open the Command Palette. Type 'Particle' and select 'Particle Launch CLI.'
10. Configure Workbench to work with the Device OS that you confirmed you're using in the beginning of this section. Your settings should be across the bottom of the page; make sure the first setting says 'Boron' and the second says "deviceOS@[4.2.0 or your specific number]" by clicking and changing them if need be.
11. Put the Boron into DFU (Device Firmware Update) mode again by pressing and holding the 'Mode' button on the Boron while simultaneously pressing and releasing the 'Reset' button. Continue holding 'Mode' until the RGB (Red Green Blue) LED starts flashing yellow.
12. Put the Boron in listening mode by pressing and holding 'Mode' until the LED blinks blue).
	- Note: You may have to press the ‘Reset’ button after putting the Boron in DFU mode and before putting it in listening mode if the LED doesn't begin blinking blue after a few seconds.
13. Type the following command into the CLI: `particle identify` ... The CLI results should present the OS with which you're working; for me, it is 4.2.0.
14. Open the Command Palette and run 'Particle: flash application (local)' to compile and flash your script (your .cpp file) to your device. If successful, this will result in the blinking of a blue LED near the micro-USB socket on the Boron.
15. Be sure to save your project before closing it.

## Practice code with Boron and Adalogger 
This section will take you through an exercise to set up the Boron and Adalogger devices and practice using code with them.

1. Stack the Boron on top of the Adalogger using female headers.

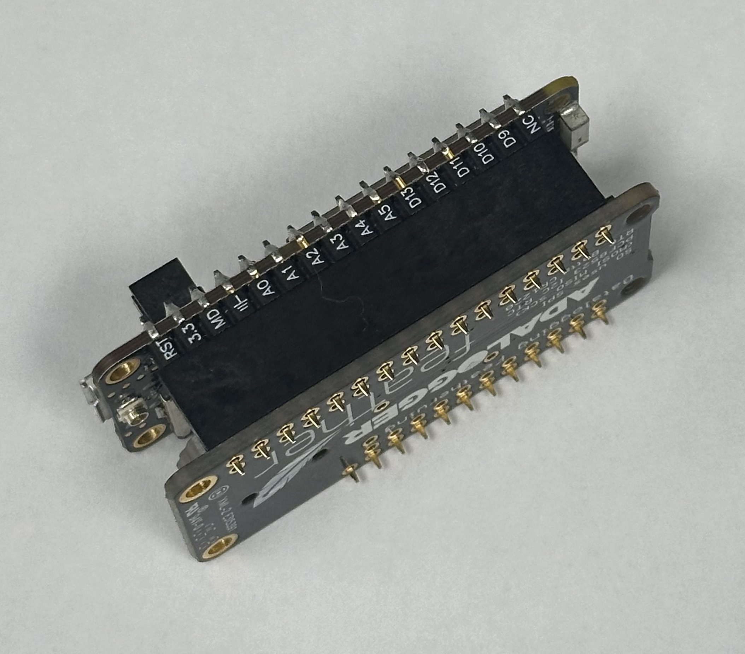
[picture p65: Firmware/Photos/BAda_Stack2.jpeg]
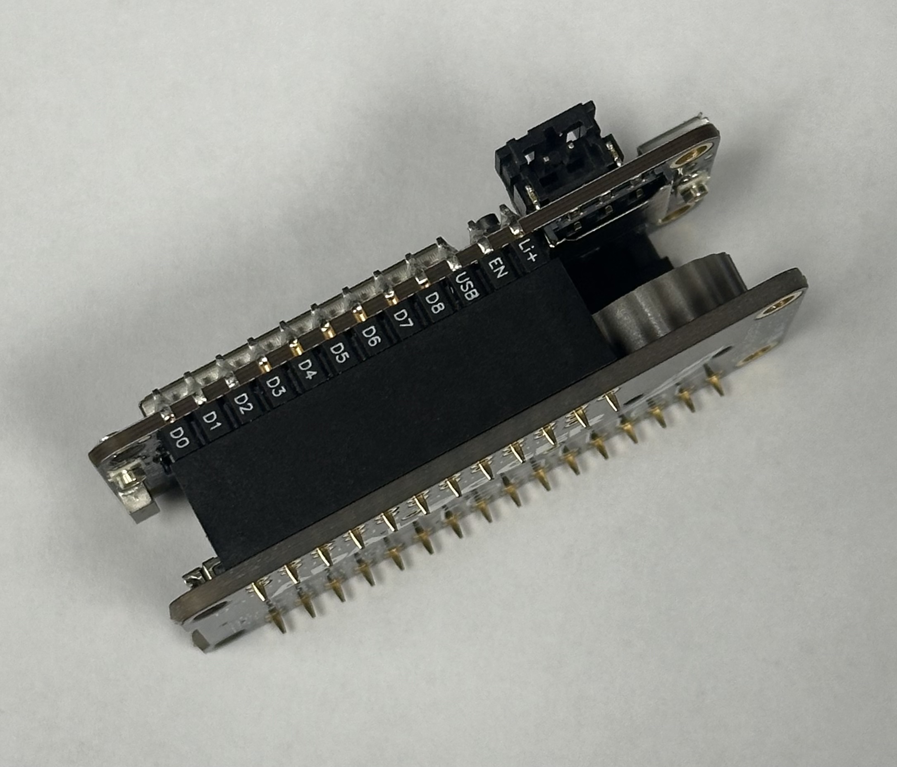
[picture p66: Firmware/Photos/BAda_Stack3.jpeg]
   

2. Plug in the Boron and put it in listening mode again (by pressing and holding 'Mode' until the LED blinks blue). Type `particle identify` into the CLI again and make sure 'Boron' and the correct Device OS (e.g. 4.2.0) are selected in the bottom bar.
3. Create a new project (I named mine RTCtest).
	- See 'Useful features' and 'Practice code with Boron' if you need a refresher on how to create a new project.
	- Make sure this new project is located exactly where you want it on your computer to avoid pathway issues (i.e. nesting this project under 'Particle_Items' is okay, but do NOT nest it within 'Blink_LED' as that is an unrelated project.)
4. Open the Command Palette and type 'Particle: Install Library'
5. Type in 'SdFat' and press enter to install the SdFat library.
6. A new tab titled 'lib' should now be under the 'explorer' tab for this project on the left ... open it!
7. Click on 'examples' -> 'ReadWrite' -> 'ReadWrite.ino' 
8. Copy all the code on this page.
9. Now click the tab that says 'src' on the left, then '[yourprojecttitle].cpp'
10. In the .cpp file, delete all code after line 10 and paste the new code you just copied from the 'ReadWrite.ino' file.
	- Like earlier, make sure `#include "Particle.h"` is left in the code! Otherwise, your .cpp file won't work properly.
 	- You have the option again to fill in applicable information in lines 2-4.

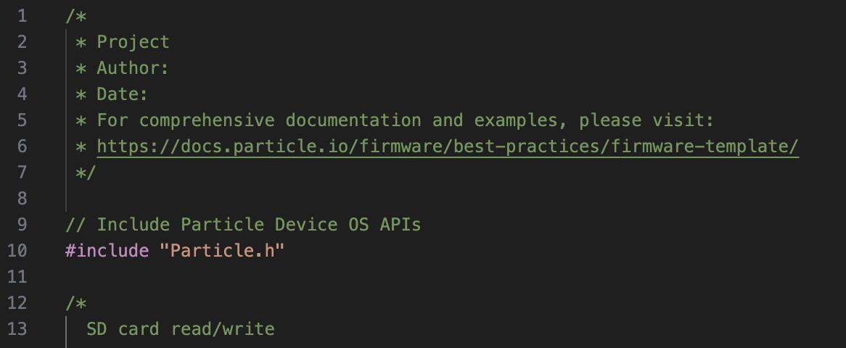
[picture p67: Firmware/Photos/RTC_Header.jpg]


12. In line 36, change `#define SD_CS_PIN SS` to `#define SD_CS_PIN D5` (SS -> D5)
13. After `File myFile;` create a new line and paste
`SYSTEM_MODE(SEMI_AUTOMATIC);` <br />
`SYSTEM_THREAD(ENABLED);`
14. After `void setup(){` create a new line and paste `Cellular.off();` and in the next line paste `delay(5500);` 
15. Where it says `if (!SD.begin(SD_CS_PIN,)) {` paste `if (!SD.begin(SD_CS_PIN,SPI_FULL_SPEED)) {`

This image shows what your code should look like after you make the changes from steps 12-15.

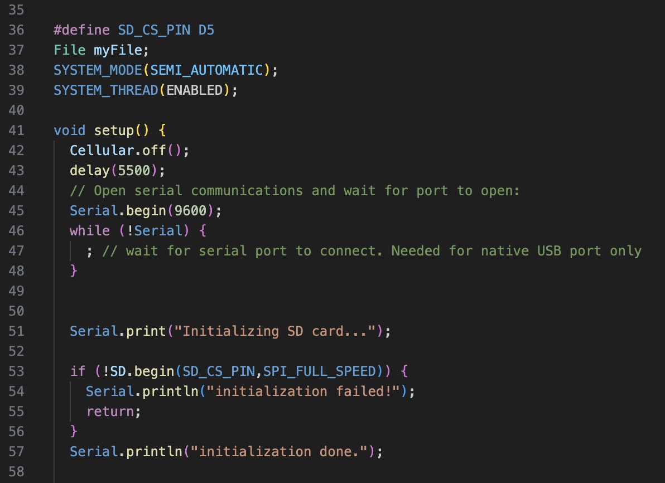
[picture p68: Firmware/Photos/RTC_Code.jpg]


16. Click the checkmark to compile the project (will take a minute).
	- If you are met with errors when trying to compile, make sure you have the correct device and OS selected in the bottom banner, check that all steps were completed correctly, and/or refer back to **Common Problems**.
17. Once it compiles, click the lightning bolt button to flash the code to the Boron. 
	- Boron should flash yellow/green when being put into DFU mode, then should breathe a white/blue light once it’s flashed.
	- Should also say it flashed successfully ... unplugging and re-plugging the cord into Boron can sometimes help if it doesn’t flash.
18. Open the serial monitor: Command Palette -> 'Particle: Serial Monitor'
 	- Select 'yes' if prompted whether you want to 'automatically reconnect when port is closed'
20. If the Adalogger does not work, the serial monitor may read something like the first chunk of text below. If it does work, it should read like the second chunk of text.

**NEED TO UPDATE PHOTOS - I DO NOT HAVE THEM**
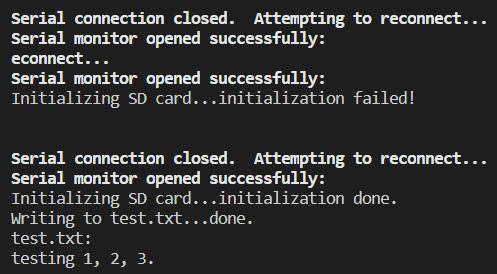
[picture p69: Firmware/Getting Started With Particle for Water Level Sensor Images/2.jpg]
	

22. If you encounter problems, go to **Common Problems** and double check that you did each step correctly. You can also try pressing the 'Reset' button on the Boron, or unplugging and re-plugging the cord.
23. Be sure to save your project before closing it.

## Practice water level sensor full code (Boron and Adalogger) 
This section will allow you to practice using water level sensor code and working with the Boron and Adalogger devices.

1. Wiring Connection between Boron/Adalogger stack and water level sensor: The water level sensor's AN pin will connect to the A1 pin of the Boron. Ground the water level sensor by connecting GND to GND on the Boron and connect to power by connecting +5 to 3v3 on the Boron. Example [here.](https://github.com/COAST-Lab/Open-Water-Level/blob/main/Firmware/Sensor%20How-To%20Images/MAX.jpg) **NEED TO UPDATE PHOTO LINK - I DO NOT HAVE PHOTO**

2. On the GitHub repository, go to 'Firmware' -> 'SLR_Boron_Maxbotix_MB7092_cm' -> 'src' -> 'SLR_Boron_Maxbotix_MB7092_cm.cpp' (or follow [this link](https://github.com/COAST-Lab/Open-Water-Level/blob/main/Firmware/SLR_Boron_Maxbotix_MB7092_cm/src/SLR_Boron_Maxbotix_MB7092_cm.cpp)).
3. Copy all the code on this page after line 13 (i.e. lines 14 onward).
4. In Particle Workbench, create a new project (I named mine BAdaFull).
	- See 'Useful features' and 'Practice code with Boron' if you need a refresher on how to create a new project.
	- Optionally, you can fill in the header with your info (i.e. project, your name, date)

5. Open the Command Palette and type 'Particle: Install Library' 
6. Type in 'SdFat' and press enter to install the SdFat library.
7. Go to the .cpp file in the new project you created (it should have the same name as your project).
8. Delete all code after line 9 (i.e. lines 10 onward) and paste the new code you copied from GitHub (remember: must have `#include "Particle.h"`). Your new header should look like this:

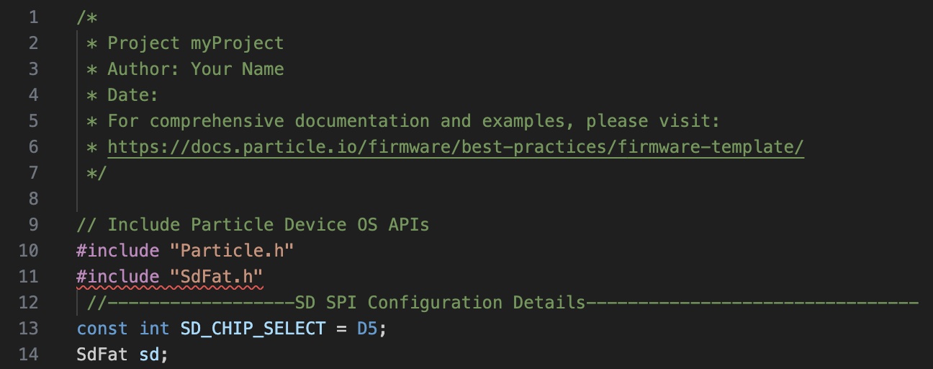
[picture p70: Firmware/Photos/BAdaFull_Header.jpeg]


9. In line 45, make sure the number after `#define PUBLISHING` is `0`.
	- If it says `1`, change it to `0`
 	- This step is crucial! It ensures that we aren't publishing data via cellular connection, which is important since we are just completing a test run.
	- Once a device is deployed with the intent of publishing data and using a cell connection, this binary value can be changed back to `1` ... but we aren't quite there yet, so make sure it says `0`!

10. At this point, I like to compile my code as a sort of "checkpoint" to make sure there aren't any issues. Click the check mark to compile.
	- If met with errors, make sure you have "Boron" and "4.2.0" selected in the page's bottom ribbon, and check that you completed each step of these instructions correctly.

11. Once your code compiles properly, flash it to the Boron by clicking the lightnight bolt. 
	- If your device is not responding or the flash is unsuccessful, make sure the device is in DFU mode, or try unplugging/replugging the cord.

12. Once flashed successfully, quickly open the serial monitor: Command Palette -> 'Particle: Serial Monitor'
13. It may take a moment, but the terminal should look something like the picture below. The serial monitor should say `serial connection closed. Attempting to reconnect…`

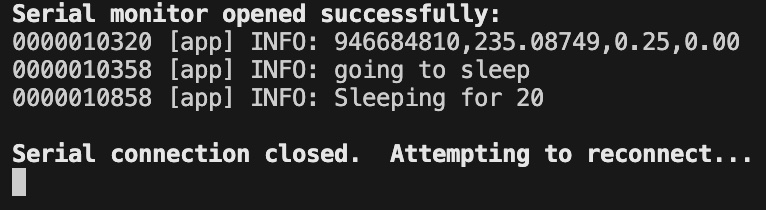
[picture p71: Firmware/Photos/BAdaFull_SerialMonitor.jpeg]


If it still doesn't work, try the problem-solving methods from Step 16 again or visit 'Useful features' and 'Common problems.'

14. The numbers produced under `Serial monitor opened successfully:` represent four useful data values, listed as follows: Unix timestamp, distance measured by the sensor (cm), battery voltage (volts), battery level (%)
	- Lines 135-139 (pictured) show how these values are printed from the code.
	- Please note that Unix timestamps represent seconds since 1 Jan 1970. However, the Unix timestamps from our non-cellular trials represent seconds from 1 Jan 2000 each time the Boron is restarted. Once we use cellular connection when deploying the device, we'll have real time stamps (i.e. since 1970).
	- Please note that the battery voltage and battery level may show values of zero; these measures are related to an external rechargeable battery that we did not connect for these test trials ... Instead, we powered the device from a laptop / computer.

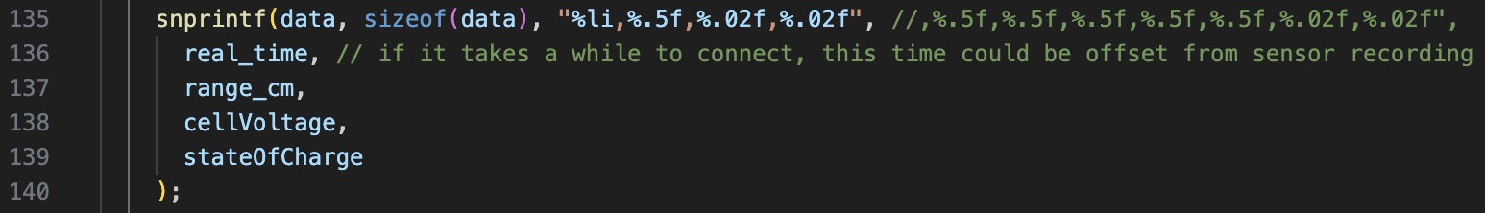
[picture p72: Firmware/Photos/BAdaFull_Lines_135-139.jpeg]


15. To finish collecting data, unplug the Boron to stop the code from running.
	- Don't forget to save your project.
	- If you wish to run this test trial again and recieve data results in faster time intervals, you can change the `SECONDS_BETWEEN_MEASUREMENTS` value in line 74 from `3600` to `30`. This will take readings at 30 second intervals instead of hourly intervals. Just be sure to change this value back to `3600` when you officially deploy the device!

16. To check all the collected values, take out the SD card from the Adalogger and put it into an SD card reader to then plug into your computer.
17. Navigate to 'file explorer' -> 'this PC' -> 'USB drive' -> `distance.csv`. You should see a table with values like below!
	- On Mac, access this file via Finder -> Locations (Untitled) -> `distance.csv`



18. Unix timestamps are listed in the leftmost column, then distance (cm), then battery voltage (volts), and battery level (%) in the rightmost column.
	- If you want to save the data from the micro SD card, press ctrl+s (Windows) or command+s (Mac) to save the data file on your computer.

All done! Now, you're more familiar with powerful tools like the Boron and Adalogger devices and VS Code, and you've learned how to collect and store the distance data. Great work!

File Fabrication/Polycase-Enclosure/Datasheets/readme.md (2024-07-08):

Here, you'll find datasheets for components of the `Polycase design`.

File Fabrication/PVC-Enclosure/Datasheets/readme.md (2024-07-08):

Here, you'll find datasheets for components of the `PVC design`.

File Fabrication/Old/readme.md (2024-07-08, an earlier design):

Files located in the "Old" directory were used in the development process of the low-cost, DIY ultrasonic water level sensors.
Refer to materials in the "PVC-Enclosure" and "Polycase-Enclosure" directories for up-to-date information.

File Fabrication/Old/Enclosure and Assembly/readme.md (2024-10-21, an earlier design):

# How to assemble an Open Water Level sensor
## Rough draft
- [ ] Chop 1.5” sch-40 PVC into 8” sections
- [ ] Drill 9/64” hole 5 cm from top of PVC for solar panel cable (red cable)
- [ ] 3D print top end cap; sand
** Is this the new red screw-in end cap?
- [ ] 3D print bottom end cap; sand
- [ ] Re-tap NPT threads (take care not to use too much force as it can crack the brittle end caps)
** Do we need to include more detail for this step? or is this something we assume users will know how to do?
- [ ] Cut solar panel cable terminator
** Do we need to include more detail for this step? or is this something we assume users will know how to do?
- [ ] Pass solar cable into PVC, taking care to give enough slack inside to make connection/solder to microUSB connector and enough outside to be able to maneuver solar panel onto top end cap
- [ ] Solder microUSB connector to solar cable with shrink tubing over bare wire
- [ ] Solder stacking headers onto adalogger featherwing
- [ ] Update system firmware on Boron to match current firmware as shown in Firmware/target directory
- [ ] Insert microSD card into featherwing (microSD card may need to be manually formatted by inserting it into your computer first)
- [ ] Stack Boron on FeatherWing
- [ ] Attach cellular antenna onto Boron
- [ ] Solder 3-pin cable with female receptacle onto FeatherWing spare pins corresponding to tbe power, ground, and analog inputs
- [ ] Solder 3-pin cable with male block onto ultrasonic distance sensor on pins corresponding to the power, ground, and analog outputs
- [ ] Drill holes in top end cap for solar mounting screws (nb: change end cap design so that drilling isn't necessary)
** I don't think this step is necessary anymore?
- [ ] If end caps are sanded enough to slide onto PVC all the way, epoxy in place. Allow to fully dry/cure.
** I think this step should be changed to account for cable gland, not epoxy, correct?
- [ ] Epoxy solar panel cable in place
** I think this step should be changed to account for cable gland, not epoxy, correct?
- [ ] Thread distance sensor into bottom end cap with pipe tape around sensor threads (3 wraps in proper direction)
** Do we need to include more detail for this step? or is this something we assume users will know how to do?
- [ ] Connect 3-pin cables for distance sensor through inside of PVC
** This step should be changed to account for chassis (e.g. thread through semi-cylinder chassis)
- [ ] Insert remaining electronics
** This step should be deleted, correct? Since all parts will be connected to chassis?
- [ ] Plug battery into Boron
** Is this step still relevant?
- [ ] Plug solar panel cable with newly terminated microUSB plug into Boron USB port
- [ ] Plug top end cap with PVC pipe plug
** Is this step still relevant with the new end cap?
- [ ] Screw solar panel onto top end cap (4-40 screws)
** Are these the correct fabrications considering the new solar panel / battery?

CONT'D
# Instructions: Rough Draft
- [ ] Chop 1.5” sch-40 PVC into 8” sections
- [ ] Drill 9/64” hole 5 cm from top of PVC for solar panel cable (red cable)
- [ ] 3D print top end cap; sand
`Is this the new red screw-in end cap?`
- [ ] 3D print bottom end cap; sand
- [ ] Re-tap NPT threads (take care not to use too much force as it can crack the brittle end caps)
`Do we need to include more detail for this step? or is this something we assume users will know how to do?`
- [ ] Cut solar panel cable terminator
`Do we need to include more detail for this step? or is this something we assume users will know how to do?`
- [ ] Pass solar cable into PVC, taking care to give enough slack inside to make connection/solder to microUSB connector and enough outside to be able to maneuver solar panel onto top end cap
- [ ] Solder microUSB connector to solar cable with shrink tubing over bare wire
- [ ] Solder stacking headers onto adalogger featherwing
- [ ] Update system firmware on Boron to match current firmware as shown in Firmware/target directory
- [ ] Insert microSD card into featherwing (microSD card may need to be manually formatted by inserting it into your computer first)
- [ ] Stack Boron on FeatherWing
- [ ] Attach cellular antenna onto Boron
- [ ] Solder 3-pin cable with female receptacle onto FeatherWing spare pins corresponding to tbe power, ground, and analog inputs
- [ ] Solder 3-pin cable with male block onto ultrasonic distance sensor on pins corresponding to the power, ground, and analog outputs
- [ ] Drill holes in top end cap for solar mounting screws (nb: change end cap design so that drilling isn't necessary)
`I don't think this step is necessary anymore?`
- [ ] If end caps are sanded enough to slide onto PVC all the way, epoxy in place. Allow to fully dry/cure.
`I think this step should be changed to account for cable gland, not epoxy, correct?`
- [ ] Epoxy solar panel cable in place
`I think this step should be changed to account for cable gland, not epoxy, correct?`
- [ ] Thread distance sensor into bottom end cap with pipe tape around sensor threads (3 wraps in proper direction)
`Do we need to include more detail for this step? or is this something we assume users will know how to do?`
- [ ] Connect 3-pin cables for distance sensor through inside of PVC
`This step should be changed to account for chassis (e.g. thread through semi-cylinder chassis)`
- [ ] Insert remaining electronics
`This step should be deleted, correct? Since all parts will be connected to chassis?`
- [ ] Plug battery into Boron
`Is this step still relevant?`
- [ ] Plug solar panel cable with newly terminated microUSB plug into Boron USB port
- [ ] Plug top end cap with PVC pipe plug
`Is this step still relevant with the new end cap?`
- [ ] Screw solar panel onto top end cap (4-40 screws)
`Are these the correct fabrications considering the new solar panel / battery?`

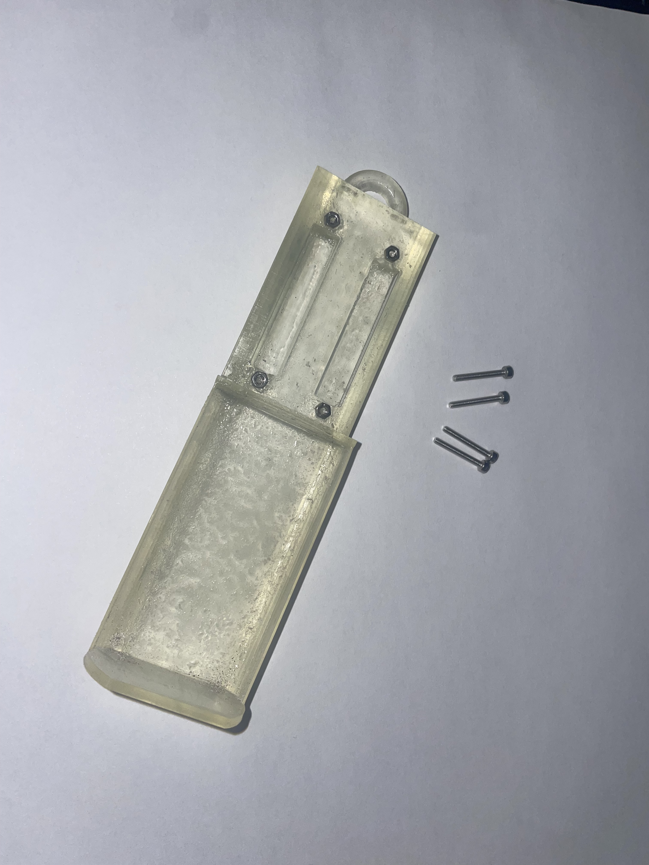
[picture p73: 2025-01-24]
Fabrication/PVC-Enclosure/Photos/ChasisOnly.jpeg

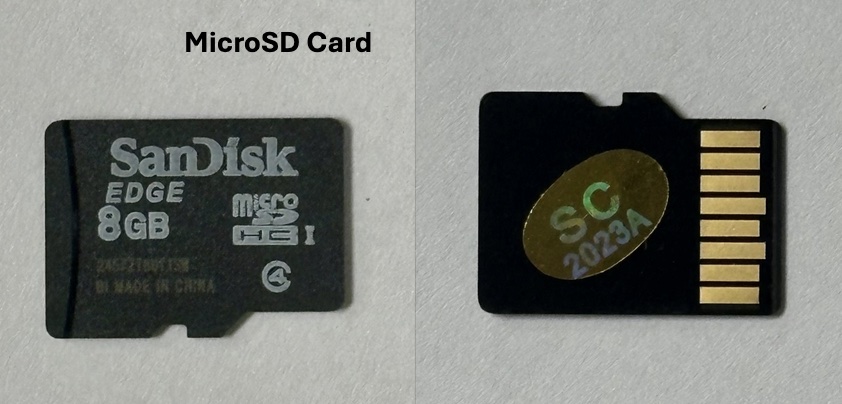
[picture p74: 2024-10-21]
Fabrication/Polycase-Enclosure/Photos/MicroSD.jpeg

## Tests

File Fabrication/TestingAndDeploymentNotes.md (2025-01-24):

# Testing and Deployment Notes for WL_004 and WL_005

## Calculations for WL_0004 

Standard deviation of 5 values over 5 hours: 1.7073168369257 inches 

NOTES: There was human error on the last value that decreased the average by about 2 inches.  

## Power/Deployment Notes for WL_004:  

After testing the water level sensor measurements in the lab, I attached the solar panel on Thursday. I used marine epoxy to seal up the screws on the polycase and left the whole sensor put together in the fume hood until the day of deployment on Tuesday. This did not help with charging the battery so when we deployed WL_004 on CMS dock it had about 0.25 battery.  

Even with a low battery start the solar panel has maintained the running of WL4, however, the charge remains between 0.25 and 0.6 which is not ideal.  

Next time use an extra nut and silicon epoxy on screws that connect polycase to 3D piece.

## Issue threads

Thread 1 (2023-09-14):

Change timing to collect sample at arbitrarily defined times

SUPScientist, 2023-09-14:
Code currently uses a 54-minute sleep timer to determine sample frequency. Change from hard-coded 54 minutes to user-defined time interval (e.g., 6 minutes following NOAA standard) and wake up/sample at as close to exact time as possible. E.g., sample at 12:00, 12:06, 12:12, etc.

Relevant chunk:

https://github.com/COAST-Lab/Open-Water-Level/blob/d125831b358b25830306dcf23a7a3b608678d8ff/Firmware/SLR_Boron_Maxbotix_MB7092_cm/src/SLR_Boron_Maxbotix_MB7092_cm.in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

SUPScientist, 2023-09-14:
This Particle reference (https://docs.particle.io/reference/device-os/api/language-syntax/arithmetic-operators/#-modulo-) may have some useful information for one possible approach. For example, use modulo operator on the current time (decimal minutes??) to determine how long until that modulo would = 0, then sleep for that amount of time.

SUPScientist, 2023-10-17:
Starting point: https://community.particle.io/t/boron-lte-waking-up-from-sleep-mode/64050/4. Includes sleep code and hints at function for calculating sleep time. Looks like it's necessary to keep cell modem in standby mode to avoid getting SIM deactivated for "aggressive reconnection" when sleep time is ≤ 10 mins.

SUPScientist, 2023-10-17:
Attempted fix, yet to be tested: https://github.com/COAST-Lab/Open-Water-Level/tree/iss1

SUPScientist, 2023-10-17:
Prior comment suggests this is an untested solution, but it was tested successfully in a commit that followed.

Closed 2023-10-17.

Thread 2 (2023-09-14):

Break up PUBLISH_STATE to do separate tasks in separate states

SUPScientist, 2023-09-14:
PUBLISH_STATE currently collects and averages data, prints to screen, saves to micro-SD card, and, if cell is activated, publishes to cloud. This should be separated into several discrete states. Or, if it's unnecessary to have state machine structure (since only a single sequence is ever used), at least move code chunks out into separate functions. E.g., a data collection/averaging function, a data printing function, a data saving function, and a data publishing function.

SUPScientist, 2023-10-10:
Hi, Hailey, I'm replying to parts of your email via GitHub so we can track it over here in the context of this issue. Here are a few comments/next steps on what I see from your recent work.

Instead of dropping the file you've been working on into the main repo's top directory, edit the code of the .ino file directly. In this case, that would be https://github.com/COAST-Lab/Open-Water-Level/blob/main/Firmware/SLR_Boron_Maxbotix_MB7092_cm/src/SLR_Boron_Maxbotix_MB7092_cm.ino. You can just copy and paste your new code into that file, save, commit, etc. and then git/GitHub will show what are called "diffs" (or differences) from the old version to your modifications. Then we'll be able to track the changes you're making as you make and commit them. Nice work creating a new branch, starting some changes, and committing them, and connecting things to this issue.

SUPScientist, 2023-10-10:
Assigning this to @hseppey since she's taken ownership of this issue.

hseppey, 2023-10-16:
When committing the changes I have made so far, should I commit them to the main branch or to the new branch I made for this issue?

SUPScientist, 2023-10-17:
If changes relate to this issue, then commit those changes to the branch you created for this issue. That way the main branch will remain "as is" so people can use the old code until we can verify the functionality of your new code.

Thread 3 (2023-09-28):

Add wiring instructions to getting started readme

SUPScientist, 2023-09-28:
The [Getting Started Readme](https://github.com/COAST-Lab/Open-Water-Level/tree/main/Firmware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) in the firmware subdirectory has a section on using the water level sensor after two intro exercises ((1) Blink LED and (2) write data to SD card).

This [section on water level sensing/logging](https://github.com/COAST-Lab/Open-Water-Level/tree/main/Firmware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) has good software/firmware guidance but no hardware/wiring instructions.

Add wiring instructions to this readme file so that others can learn how to set up the hardware. Note that there's a related example here: https://github.com/COAST-Lab/Open-Water-Level/blob/main/Firmware/Sensor%20How-To.md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. However, that related example is for a slightly different sensor. It should still work for the new and improved sensor, perhaps with minor modifications.

BentleySettin, 2023-10-02:
In the assembly section of the Readme it states that the water level sensor uses OLED FeatherWing, RTC FeatherWing, Maxbotix, and Feather microcontroller. I used a Boron, RTC featherwing, and Maxbotix. Do you want me to put my wiring instructions even though I used different electronics?

SUPScientist, 2023-10-02:
This issue is specifically related to the [Getting Started Readme](https://github.com/COAST-Lab/Open-Water-Level/tree/main/Firmware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) as linked in the initial post. That doesn't state anything about the Feather microcontroller. The main readme in the repo's top directory definitely needs updating but this issue is specific to the [Getting Started Readme](https://github.com/COAST-Lab/Open-Water-Level/tree/main/Firmware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), so don't worry about other readme files in dealing with this issue.

BentleySettin, 2023-10-02:
Gotcha, I was looking at the wrong Readme. I just updated the first line in the Boron and Adalogger section and the first line in the Practice full code section. Do you want me to add images? I see that the example you sent previously included images also.

SUPScientist, 2023-10-02:
Excellent. Nice work. I'm looking at https://github.com/COAST-Lab/Open-Water-Level/commit/a9faafad45e96351497a7c57d1692e0f236c3dd9 and it looks like exactly the sorts of updates we needed. Yes, one good image showing the wire connections would help, and if you think there's anything else needed for someone to learn how to complete the physical setup following that guide. Thanks.

SUPScientist, 2023-11-28:
@BentleySettin, I think you may have completed this work but maybe not yet posted instructions and an image of the wire connections to this repository. Could you post the image in a relevant subdirectory and link to it from here, or if it's already in the repo somewhere, post a link here and I'll close this issue?

BentleySettin, 2023-11-28:
Here are the instructions: https://github.com/TinyCamML/Boron-and-OpenMV-Basics/commit/7c6f8948191d8e4c47ddbd254060045436634b3d

The wire connections are in this document and here it is in the "Boron-and-OpenMV-Basics" repo: https://github.com/TinyCamML/Boron-and-OpenMV-Basics/commit/7c6f8948191d8e4c47ddbd254060045436634b3d

SUPScientist, 2023-11-28:
I meant for the water level sensor project in this repo (not the OpenMV one). This is an old thread that I'm revisiting because we never closed it when you were working on it two months ago.

BentleySettin, 2023-11-30:
Here is the document with added instructions and linked images within document if this is what you are referring to :

https://github.com/COAST-Lab/Open-Water-Level/commit/8dd33a6dfeefda5d930ce61ae7488d19acd91512

SUPScientist, 2023-11-30:
Looks good, thanks! Closing as complete...

Closed 2023-11-30.

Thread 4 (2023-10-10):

Beautify your code!

SUPScientist, 2023-10-10:
Arduino/Wiring/Particle's Device OS/C/C++/etc... do not care about if/how you indent your code, but it is far more readable if nested loops (loops inside loops, or if/for blocks, etc.) show increasing levels of indentation. This isn't hard to do by hand (keyboard) and VS Code tries to help you out along the way. But it can occasionally be very helpful to use a free online formatter/beautifier to do it for you.

Check out https://codebeautify.org/cpp-formatter-beautifier as an example. Put in your code chunk, or entire script, and see it spit out nicely formatted code. Note that the link above is for C++ (which covers Arduino/Particle) but there are other flavors for Python and other languages, too.

@BentleySettin, @hseppey, et al., please use that occasionally to ensure nicely formatted and more readable code. It won't just help others; it will help you follow your own code better!

SUPScientist, 2025-05-06:
This issue should be converted to general info on the COAST Lab wiki or other getting started guide rather than an always-open issue in this repo.

BentleySettin, 2025-05-07:
Sounds good. I can move this to "other notes" in the COAST Lab repo unless you prefer another place.

SUPScientist, 2025-05-07:
Rachel is working on a wiki to eventually live [here](https://github.com/COAST-Lab/COAST-Lab.github.io/wiki) for stuff like this, so we can sit on it for a sec.

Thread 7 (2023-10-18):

Make single data buffer for serial, SD, and publish writing

SUPScientist, 2023-10-18:
Code currently repeats versions of what it intends to serial print, SD log, or publish. Create a single data buffer and serial print, SD log, and/or publish that buffer as desired.

E.g., current code shows
https://github.com/COAST-Lab/Open-Water-Level/blob/20a093c28c221f682e9bd088dc9954c6d17718ae/Firmware/SLR_Boron_Maxbotix_MB7092_cm/src/SLR_Boron_Maxbotix_MB7092_cm.in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

followed by
https://github.com/COAST-Lab/Open-Water-Level/blob/20a093c28c221f682e9bd088dc9954c6d17718ae/Firmware/SLR_Boron_Maxbotix_MB7092_cm/src/SLR_Boron_Maxbotix_MB7092_cm.in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

and
https://github.com/COAST-Lab/Open-Water-Level/blob/20a093c28c221f682e9bd088dc9954c6d17718ae/Firmware/SLR_Boron_Maxbotix_MB7092_cm/src/SLR_Boron_Maxbotix_MB7092_cm.in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

Fill this final buffer earlier in code and use it throughout.

SUPScientist, 2023-10-18:
Attempted fix in https://github.com/COAST-Lab/Open-Water-Level/commit/b6b4c36b9efedac537f859ba2a237e7fdca54750. Compiled but untested.

SUPScientist, 2023-10-19:
Tested and works as intended. Closing.

Closed 2023-10-19.

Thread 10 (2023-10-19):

Accurate timing depends on good cloud connection

SUPScientist, 2023-10-19:
Timing of sleep and therefore wakeup uses `Time.now()` which is completely inaccurate without a good recent cloud connection. On first wake/power-up, clock resets to Sat Jan 01 2000, so all subsequent wakes happen at intervals from there, unrelated to real time. Not sure if there's a robust fix to this but it's good to note that first sample or maybe a couple could have terribly inaccurate timestamps.

SUPScientist, 2024-01-04:
Does it make sense to add logic block that looks to see if date is in 2000 (or at least before some year closer to present) and not publish that data if so?

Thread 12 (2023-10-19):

If SD card doesn't connect, system gets stuck in expensive cell connection loop

SUPScientist, 2023-10-19:
If SD stuff fails in these chunks:
https://github.com/COAST-Lab/Open-Water-Level/blob/a136a71cb4b3972a8e5b6aeaf3e89f752977792d/Firmware/SLR_Boron_Maxbotix_MB7092_cm/src/SLR_Boron_Maxbotix_MB7092_cm.in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
then the firmware will restart at the top without any sleep. It will therefore stay connected indefinitely by continuously taking a sample and trying to save it to SD card, but likely always failing and therefore restarting the firmware. Never makes it to PUBLISH_STATE nor SLEEP_STATE.

SUPScientist, 2023-10-19:
One possible solution is to use a `while(1)` loop to force the device to hang if SD card stuff isn't working.

A better but harder solution would be to separate sampling from the DATALOG_STATE and if SD doesn't work, it could still try PUBLISH_STATE or SLEEP_STATE according to PUBLISHING definition.

SUPScientist, 2023-10-19:
Temporary fix here: https://github.com/COAST-Lab/Open-Water-Level/commit/07ea9f39437c375042c1267e6dedeea19c17c7c1. This just forces code to hang, which is not a real solution, but hopefully minimizes data operations while sensor not working.

SUPScientist, 2023-10-19:
Update: it doesn't actually hang in while loop. It just moves right on past it. `while(1)` statement is a complete waste.
https://github.com/COAST-Lab/Open-Water-Level/blob/c1495ac5710489bb421941316cdee38f318033c5/Firmware/SLR_Boron_Maxbotix_MB7092_cm/src/SLR_Boron_Maxbotix_MB7092_cm.in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

SUPScientist, 2024-03-04:
Update SD logic to prevent hanging. It would hang on `while(1)`, contrary to comment above.

Updated in https://github.com/COAST-Lab/Open-Water-Level/commit/0af4f6e1b60785f17403fc15a08bfeb9ed8cfcaf

New logic has it print error but not hang.

Closed 2024-03-04.

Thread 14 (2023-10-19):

Enclosure subdirectory is badly out of date

SUPScientist, 2023-10-19:
Old SolidWorks drawings for laser cut enclosure haven't been used in 3 years. Update with new housing drawings when possible.

SUPScientist, 2023-10-26:
Updated parts files (designed in Fusion, exported to .stl for 3D printing) are now here: https://github.com/COAST-Lab/Open-Water-Level/tree/main/Enclosure/PVC-End-Caps. Several modifications still needed:

- [ ] Threads didn't show up in STL. That is, they were in F3D file, but didn't export. This support article seems to know about the issue but didn't solve it: https://www.autodesk.com/support/technical/article/caas/sfdcarticles/sfdcarticles/Threads-do-not-show-up-in-an-exported-STL-file-from-Fusion-360.html.
- [ ] The pipe gripper that seals the top of the top end cap needs a lip to sit on. It currently rests on an inner slope of the top end cap's ugly angled flange and doesn't rest down on a lip like it should, and therefore doesn't seal the way it should. Make a lip (1.9–2" diameter).
- [ ] Better flange needed for solar panel with screw holes for mounting panel.
- [ ] Hole needed for solar power cable.

SUPScientist, 2023-11-06:
See https://github.com/COAST-Lab/Open-Water-Level/issues/15 for issue specific to top end cap

SUPScientist, 2023-11-16:
@acl3053, check out a few updates here: https://github.com/COAST-Lab/Open-Water-Level/tree/main/Enclosure/PVC-End-Caps. Note that GitHub renders STLs nicely in the browser!

I modified your bottom end cap design to open up the part of the hole that is not threaded. I used an NPT tap/drill chart to choose the new diameter.

(Side note: when I tried to export your end cap design into the Inventor file format (.ipt; in case in the future someone wanted to open it in Inventor), Fusion 360 created a folder that contains also the threaded part in addition to the part you designed so that I guess it can do the subtraction.)

acl3053, 2023-11-16:
@SUPScientist, has the thread itself changed at all? I thought that the subtraction method didn't seem to work based on the print I made a couple of weeks ago. I made the part again in Inventor to see if that would work but threads do not model in Inventor when exported to .stl. I uploaded it to my fork here: https://github.com/acl3053/Open-Water-Level/blob/main/Enclosure/PVC-End-Caps/WaterLevel_BottomCap_InventorTest.ipt if anyone can figure out a way around this limitation.

SUPScientist, 2023-11-16:
No, the thread itself has not changed. The small change I made as mentioned above might allow an NPT tap to open up the existing threads slightly, though. It's not ideal to both print threads and tap threads (usually I pick one or the other!), but this may be a workable solution. We'll see.

acl3053, 2023-11-17:
Here is link for a solution to the lack of thread modeling in Fusion 360 (using the above stated subtraction method) for future reference: https://forums.autodesk.com/t5/fusion-360-design-validate/modeled-npt-tapped-threads/td-p/11653018.

SUPScientist, 2024-01-04:
Improvements may be necessary, but closing with https://github.com/COAST-Lab/Open-Water-Level/commit/fcdc1154d399747b5f7f4f890c0da2b4f97ea5d8 given marked improvements to design and file organization

Closed 2024-01-04.

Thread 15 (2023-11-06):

Design better top end-cap

SUPScientist, 2023-11-06:
Need top end cap that can:

- [x] Mate with 1.5" schedule 40 PVC. To be epoxied in place.
- [x] Cover and provide waterproofing for electronics.
- [x] Allow for easy access to electronics (e.g., using [1.5" gripper](https://www.lowes.com/pd/Oatey-Gripper-1-1-2-in-x-1-1-2-in-x-1-1-2-in-x-1-1-2-in-dia-PVC-Schedule-40-Test-Plug-Fitting/3824165)).
- [x] Provide flange onto which solar panel can be fastened and held at appropriate angle for a given latitude. Angle is ~ 30º in Wilmington, NC. Solar panel is https://www.adafruit.com/product/5367.
- [x] Entry for solar panel cable into main PVC housing.

SUPScientist, 2023-11-16:
New end cap designed in https://github.com/COAST-Lab/Open-Water-Level/commit/88754392173e74e9530ac1191b0084599ffcc6ce.
See https://github.com/COAST-Lab/Open-Water-Level/tree/main/Enclosure/PVC-End-Caps for files. Top end cap still does not have and will (likely need):

- [ ] Drain hole(s) to allow rain to drain off of end cap and not pool around the gripper plug
- [ ] Hole(s) to route solar panel cable into housing

SUPScientist, 2023-11-22:
Design for 4 of 6 holes in https://cdn-shop.adafruit.com/product-files/5367/5367_Voltaic+Systems+P105+R7D.pdf.

1. Side of end-cap parallel to short side of panel is 133.2 mm between holes and 2 x 7.4 mm to edge = 148 mm.
2. Side of end-cap parallel to long side of panel is intended to accommodate two of three mounting holes on both sides. The distance required to cover the two holes is 103.6 mm between holes and 2 x 7.9 mm = 119.4 mm. This edge is on the hypotenuse of a 30-60-90 triangle. The sketched side is adjacent to the 30º angle. Therefore, that side measures 119.4 mm  x cos(30º) = 103.4 mm.

SUPScientist, 2023-11-27:
Closing with https://github.com/COAST-Lab/Open-Water-Level/commit/f3a72e136955216568e4b4c922427dae63a2731e

Closed 2023-11-27.

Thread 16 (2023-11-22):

Design and build chassis for electronics

SUPScientist, 2023-11-22:
Design and 3D print or mill/route part that slides into PVC housing and serves as chassis for
- Boron and stacked Adalogger Featherwing
- Battery pack
- Cell antenna

gracelower, 2024-07-18:
Chassis designs:
[Fabrication/PVC-Enclosure/Enclosure-and-Assembly](https://github.com/COAST-Lab/Open-Water-Level/tree/791c02cdef5b158903b8f5a916721b1455ee3ed0/Fabrication/PVC-Enclosure/Enclosure-and-Assembly)
[Fabrication/Polycase-Enclosure/Enclosure-and-Assembly](https://github.com/COAST-Lab/Open-Water-Level/tree/791c02cdef5b158903b8f5a916721b1455ee3ed0/Fabrication/Polycase-Enclosure/Enclosure-and-Assembly)

Closed 2024-11-06.

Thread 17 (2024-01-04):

Document fabrication

SUPScientist, 2024-01-04:
Document steps to fabricate open water level sensors and put in a .md file in appropriate location
Here's a rough draft
- Chop 1.5” sch-40 pvc into 8” sections (nb: may want shorter so that cables reach)
- Drill 9/64” hole 5 cm from top of pvc
- 3D print top end cap, sand
- 3D print bottom end cap, sand
- Re-tap NPT threads
- Cut solar panel cable terminator
- Pass solar cable into pvc, taking care to give enough slack inside to make connection/solder to microUSB connector and enough outside to be able to maneuver solar panel onto top end cap
- Solder microUSB connector to solar cable
- Solder stacking headers onto adalogger featherwing
- Update system firmware on Boron
- Insert microSD card into featherwing
- Stack boron on featherwing
- Attach cellular antenna
- Solder 3-pin cable with female receptacle onto featherwing spare pins
- Solder 3-pin cable with male block onto ultrasonic distance sensor
- Drill holes in top end cap for solar mounting screws
- If end caps are sanded enough to slide onto PVC all the way, epoxy in place. Allow to fully dry/cure.
- Thread distance sensor into bottom end cap with pipe tape around sensor threads (3 wraps in proper direction)
- Connect 3-pin cables for distance sensor, through inside of PVC
- Insert remaining electronics

SUPScientist, 2024-02-19:
Added in https://github.com/COAST-Lab/Open-Water-Level/commit/c44f5f31689934bf184f9ae92092e76f9a2d3afd

Closed 2024-02-19.

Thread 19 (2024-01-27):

Update BOM

SUPScientist, 2024-01-27:
Sourced a few new parts:
- Larger battery
- Larger solar panel
- Cables for sensor connection
- Slicing solar panel cable onto micro-USB jack

SUPScientist, 2024-01-27:
Closing (for now) with https://github.com/COAST-Lab/Open-Water-Level/commit/afa7a6b64de6d0c43911f22ad7473666488be392

Closed 2024-01-27.

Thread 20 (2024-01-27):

Add mechanical/plumbing parts to BOM

SUPScientist, 2024-01-27:
- Resin
- PVC
- Pipe plug
- Pipe tape
- Screws for solar panel

gracelower, 2024-07-18:
Bills of Materials:
[Fabrication/PVC-Enclosure/BOM](https://github.com/COAST-Lab/Open-Water-Level/tree/791c02cdef5b158903b8f5a916721b1455ee3ed0/Fabrication/PVC-Enclosure/BOM)
[Fabrication/Polycase-Enclosure/BOM](https://github.com/COAST-Lab/Open-Water-Level/tree/791c02cdef5b158903b8f5a916721b1455ee3ed0/Fabrication/Polycase-Enclosure/BOM)

SUPScientist, 2025-03-05:
Several BOMs in development in parallel, but each addresses key points here. Closing.

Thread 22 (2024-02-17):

Add thru holes to top end cap for solar panel mounting screws

SUPScientist, 2024-02-17:
- Find hole pattern for solar panel
- Add thru holes to top end cap
- 4-40 screw fits solar panel thru holes

SUPScientist, 2025-03-05:
Newest versions use off-the-shelf Voltaic panel/battery pack combo and therefore do not need this mounting scheme which was conceived for a prior panel-only design.

Closed 2025-03-05.

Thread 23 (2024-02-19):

Add table of contents to top of main readme

SUPScientist, 2024-02-19:
A key improvement to the repository's main readme (i.e., the readme.md file that renders when you go to this repository's highest level folder) would be to add a table of contents that links to the important documents that can be found elsewhere. E.g., the getting started guide, the fabrication guide, ... what else would someone want to know when they first showed up at this repo?

SUPScientist, 2024-03-04:
@dylan9081, I just pulled and merged changes from https://github.com/COAST-Lab/Open-Water-Level/pull/26.

The repo's main readme should be the next target. See comment above. I recommend starting with a blank page rather than working off of the existing readme. Write an outline of the information that you think should be described on the repo's homepage (or in other words the main readme file). Share that outline with me (e.g., online word doc in onedrive) so that I can contribute, and then start to fill it out using markdown. We can pull in text from the existing readme, but the existing readme is so irrelevant at this stage that I'd prefer you start with a blank page.

The main readme is meant to address the question: "what would you want to know if you found yourself staring at this repository's homepage/main readme?" The answer can come in the form of both well organized text as well as hyperlinks.

SUPScientist, 2024-03-22:
Some improvements in https://github.com/COAST-Lab/Open-Water-Level/pull/27. Still in progress.

SUPScientist, 2024-03-25:
Noting more progress in https://github.com/COAST-Lab/Open-Water-Level/pull/29 and several recent commits such as https://github.com/COAST-Lab/Open-Water-Level/commit/52d44031ac312f37193f55b04293dc6768f483ba. @dylan9081, please give this another read and click on the links on the main readme to confirm everything works. You may close this issue if you think the readme accomplishes its goal, or continue adding to it if not (let me know if the latter via a comment here).

dylan9081, 2024-03-26:
I did a couple of small text/grammar edits, but everything looks good. All links worked.

Closed 2024-03-26.

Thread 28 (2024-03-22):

Optimize sleep config

SUPScientist, 2024-03-22:
Current sleep configuration uses `SystemSleepNetworkFlag::INACTIVE_STANDBY` which was selected for < 10' sleep duration of original design. Current sampling period is 60', so `INACTIVE_STANDBY` burns power wastefully.

https://github.com/COAST-Lab/Open-Water-Level/blob/0efb8d7127e500b1fe9524e049f246ad905534ea/Firmware/SLR_Boron_Maxbotix_MB7092_cm/src/SLR_Boron_Maxbotix_MB7092_cm.in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

Get rid of `INACTIVE_STANDBY` flag, at least for longer sampling intervals. Make sure to add back in if interval returns to ~ 6' period.

SUPScientist, 2024-04-09:
Fixed, seemingly, with https://github.com/COAST-Lab/Open-Water-Level/commit/95b8029a5a3109da641ae0f197c54f86aa2ce130

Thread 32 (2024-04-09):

Fit parts inside in more protected and reliable way

SUPScientist, 2024-04-09:
In new polycase enclosure, parts are essentially stuffed inside:
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
Find a better way to mount parts inside with, for example, a 3D-printed chassis that holds the electronics and wires in specified locations.

SUPScientist, 2024-04-09:
@dylan9081, do you want to take a stab at this one?

SUPScientist, 2024-04-10:
See also https://github.com/COAST-Lab/Open-Water-Level/blob/main/Fabrication/Datasheets/polycase_2d_drawings.pdf for interior dimensions

gracelower, 2024-07-18:
Chassis designs:
[Fabrication/PVC-Enclosure/Enclosure-and-Assembly](https://github.com/COAST-Lab/Open-Water-Level/tree/791c02cdef5b158903b8f5a916721b1455ee3ed0/Fabrication/PVC-Enclosure/Enclosure-and-Assembly)
[Fabrication/Polycase-Enclosure/Enclosure-and-Assembly](https://github.com/COAST-Lab/Open-Water-Level/tree/791c02cdef5b158903b8f5a916721b1455ee3ed0/Fabrication/Polycase-Enclosure/Enclosure-and-Assembly)

Closed 2024-11-06.

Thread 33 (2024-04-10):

Switch from Serial.print to Log.info

SUPScientist, 2024-04-10:
### Problem
Firmware currently uses `Serial.print()` type statements frequently.

### Solution
- According to https://community.particle.io/t/jsn-sr04-callback-confusion/65888/2, it is preferable to use `Log.info()` type statements. However, it's not as simple as just a text-based find and replace operation.
- Read the docs on logging here: https://docs.particle.io/reference/device-os/api/logging/logging/
- Replace Serial.print-type statements (i.e., including Serial.println, and any formatted print statements) with Log.info type statements.

SUPScientist, 2024-06-21:
@ gracelower, this would be a great next issue for you to tackle.

Recommended approach:
- Fork the repo, or if you have a fork, make sure it's caught up with the main repo/branch here.
- Create a branch called something like log_info
- Read the issue as described above and begin wrapping in these changes. Some of the swaps from Serial.print to Log.info will be extremely quick and easy, but some where formatting is needed may present a bit more of a challenge, but I'm confident you're up to it!

gracelower, 2024-06-24:
@SUPScientist Sounds good - I'll get to this ASAP!

gracelower, 2024-07-10:
Solution for errors in Line 255:

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

gracelower, 2024-07-10:
Updated code with Log.info statements and adjusted Getting_Started instructions (in Firmware folder) to reflect these changes [https://github.com/COAST-Lab/Open-Water-Level/commit/c8fbb673e3e3e8fefc8327921a47488ecf37b049](url)

gracelower, 2024-07-18:
- [x] Find solution to Serial.print issue; document
- [ ] Change sample code in Firmware folder; upload to GH
- [ ] Edit Getting-Started instructions

gracelower, 2024-07-18:
New proposal: combination of Serial.print + Log.info statements

- Serial.print sends data locally to the serial monitor
- Log.info uses a Particle logging library and is useful for viewing messages in Particle Workbench + remote monitoring
- "If you want to ensure that a message is seen both locally and remotely, use both Serial.print and Log.info for the same message"

A `WORK-IN-PROGRESS` file was created in the Firmware > SLR_Maxbotix_... folder to house code that combines these two statement types. Resulting zeros in the data are only for battery voltage and battery level (due to the device being powered by a computer, not battery).

Please note that part of this proposal was generated in part by AI.

SUPScientist, 2024-07-18:
Everything sounds like it's on the right trajectory till this last comment that starts "New proposal." Not sure I follow. The goal is to switch completely away from `Serial.print()` type statements and use only `Log.info()` type statements, so I don't think the combo idea is what we want.

I think the issue is that I disagree with the last bullet of your AI-generated proposal

> "If you want to ensure that a message is seen both locally and remotely, use both Serial.print and Log.info for the same message"

`Log.info()` will print to screen in my understanding.

gracelower, 2024-07-18:
I had initially switched all `Serial.print` statements to `Log.info` statements to eliminate all instances of Serial.print as you mentioned. The code compiled and flashed successfully, but I ran into a problem where no results were being returned at all to the serial monitor, instead simply showing the serial monitor opening and closing. When I added some of the `Serial.print` statements back into the code, I was able to see data in the serial monitor once more.

I will do some more research on this and refer back to the Particle Community forum for ways to navigate this issue without reinstating any Serial.print statements. Thanks!

gracelower, 2024-07-19:
Added `SerialLogHandler logHandler;` to Global objects list before void_setup(void) {

- changed Serial.print statements to Log.info statements
- condensed final two Serial.print statements into single line: `Log.info("Sleeping for %i", seconds_to_sleep);`
- compiled/flashed line-by-line to check results
- updated screenshot of what results should look like in serial monitor & embedded in instructions

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

Changes staged; will commit & submit pull request once current pull request is merged.

gracelower, 2024-07-25:
Pull request https://github.com/COAST-Lab/Open-Water-Level/pull/45 addresses this issue

SUPScientist, 2024-07-25:
Agreed. https://github.com/COAST-Lab/Open-Water-Level/pull/45 solves the issue. Closing. Nice work!

Closed 2024-07-25.

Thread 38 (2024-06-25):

Reorganize "Fabrication" folder to reflect new versions of sensor

gracelower, 2024-06-25:
Reorganize "Fabrication" folder to reflect new versions of sensor

- [x] Create folders within Fabrication specific to the Polycase enclosure, PVC enclosure, and old content
- [x] Create readme.md file explaining the need for multiple designs and separate folders, plus how to choose the best enclosure option for various applications
- [x] Create readme.md files for assembly guides using old instructions
- [x] Update assembly instructions + add step-by-step photos (for both designs)
- [x] Build BOMs for both designs
- [x] Upload finalized parts list spreadsheets
- [x] Add datasheets for components

gracelower, 2024-07-08:
https://github.com/COAST-Lab/Open-Water-Level/pull/40#issue-2389139746

gracelower, 2024-07-25:
Pull requests pertaining to this issue:
https://github.com/COAST-Lab/Open-Water-Level/pull/40
https://github.com/COAST-Lab/Open-Water-Level/pull/41
https://github.com/COAST-Lab/Open-Water-Level/pull/43
https://github.com/COAST-Lab/Open-Water-Level/pull/44

Closed 2024-11-06.

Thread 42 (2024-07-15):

Questions & Next Steps

gracelower, 2024-07-15:
Opening this issue to document questions I come across and potential NEXT STEPS for the Open Water Level Sensor project.

- [x] PVC end caps
- [x] Parts spreadsheets
- [x] Solar system assembly
- [x] Metal vs. cellular antenna
- [x] Returning zeros (Log.info)
- [x] Get-Involved
- [x] Polycase design
- [x] Getting-Started instructions
- [x] **Close issues that have been completed**

gracelower, 2024-07-15:
PARTS SPREADSHEETS
- I have built two separate spreadsheets (one for Polycase enclosure, another for PVC enclosure), located in my Student Projects folder in the SharePoint
- Update these spreadsheets once all parts are finalized & upload .pdf or .csv to BOM folders

gracelower, 2024-07-15:
ASSEMBLY INSTRUCTIONS
- I wrote new instructions for assembling the two sensor models, but more updates are needed to ensure a comprehensive and accurate assembly guide
- Specifically, SOLAR SYSTEM ASSEMBLY in both models needs work
- Need to take photos of assembly process & label them alongside instructions for visual & written guide

gracelower, 2024-07-15:
METAL SCREWS VS. CELLULAR ANTENNA
- This may not be an issue, but is something to watch out for!
- To enhance cell reception of the antenna, it should be no less than 10mm from metal objects ... while this was considered in the Polycase chassis design, it's not perfect (especially because of screws in the Polycase and chassis).
- Keep this in mind when deploying the sensor & assessing resulting data! Could potentially be an area for improvement.

gracelower, 2024-07-15:
RETURNING ZEROS
- Previously, the code+sensor was returning too many zeros in testing. I adjusted the code to transition `Serial.print` statements to `Log.info` statements, which seems to have resolved this problem. I am opening this issue just as a reminder to look out for zeros moving forward.
- NOTE: When using the "Getting-Started" instructional guide, the sensor is powered by a PC, not a battery or solar system, so "battery level" WILL return zeros.
- Watch out for zeros in future testing & deployment; they shouldn't arise, but if they do, another factor may be at play.

gracelower, 2024-07-15:
GET INVOLVED
- As the project progresses, expanding the contents of the [Get Involved](https://github.com/COAST-Lab/Open-Water-Level/tree/main/Get-Involved) folder may be a nice touch! Not pertinent to the mechanics of the project, but important nonetheless.
- I have started a spreadsheet of potential partners in my Student Projects folder in the SharePoint; if the sensor eventually gets to a distribution stage, feel free to use this resource as a starting point for deployment and educational partnerships!

gracelower, 2024-07-16:
POLYCASE DESIGN
- Potential project: work with IO Rodeo for ideas to improve Polycase enclosure

gracelower, 2024-07-23:
Relates to https://github.com/COAST-Lab/Open-Water-Level/commit/b33ade3fdd9305f02514a217aa43f8a5b14825cd

gracelower, 2024-07-24:
GETTING-STARTED INSTRUCTIONS
- A few photos in the Getting-Started Instructions markdown code are embedded but no longer exist; I believe these were photos included in previous versions of the repo, but are no longer present and therefore have 404/nonexistent pathways. These issues are marked in bold within the actual code.
- The last section of instructions ("practice full code") has been simplified in the number of steps by actually changing the sample code itself; not sure if this is something we want to do for the other sections of the instructions, too. None of the other instruction sections are _incorrect_ per se, just might be able to be simplified.

Closed 2025-03-05.

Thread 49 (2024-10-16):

Water level monitoring code does not work for the Argon.

crs8973, 2024-10-16:
The original code calls for cellular to be turned off for the Boron, but this call needs to be changed as we are working with Argon devices that utilize WiFi instead of cellular. To fix this issue, the Cellular.off() function should be changed to WiFi.off().

SUPScientist, 2025-03-05:
Deliberately duplicated in #51 and #52 for Smart Coasts class. Solved with https://github.com/COAST-Lab/Open-Water-Level/commit/fa5ed18f3dbffe352705beb524a5ad2929c5a4fa.

Closed 2025-03-05.

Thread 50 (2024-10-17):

Investigate need for an internal battery

BentleySettin, 2024-10-17:

Closed 2025-03-05.

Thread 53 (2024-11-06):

Adapting for deeper range and use within a well

gotjoshua, 2024-11-06:
I am considering to drive into this diy for our 7.5m deep well.

I see that the brand of sensor you use also has some with deeper range:
https://maxbotix.com/products/mb7066

Can you give an indication how complicated it will be too adapt the code and design to work with a different sensor?

Not asking you to make that happen, just for a reality check and some guidance. If I go for it, I'll be happy to submit a PR

SUPScientist, 2025-03-05:
Given that we're using the sensor's analog output and that your proposed sensor adaptation uses that as well, code changes would likely be straightforward. I imagine it would simply be a matter of proper ADC count to distance conversion, which for us happens in https://github.com/COAST-Lab/Open-Water-Level/blob/831b5fd010759d1795c42bbcbe54730bb942a039/Firmware/SLR_Boron_Maxbotix_MB7092_cm/src/SLR_Boron_Maxbotix_MB7092_cm.cp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.

(PS: apologies for the terribly belated reply. We hadn't properly configured notifications for this repo in our organization and am seeing this issue for the first time just now.)

gotjoshua, 2025-03-06:
Many thanks for your reply... We are also very slow to get started with the project, but it's great to know that you are around if we run into issues!

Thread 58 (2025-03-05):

Top end cap needs to be heightened to avoid plug bolt hitting solar panel.

SUPScientist, 2025-03-05:

SUPScientist, 2025-03-05:
New power design (voltaic panel/pack) obviates this issue.

Closed 2025-03-05.

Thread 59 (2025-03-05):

Would be better to be able to twist top end cap or whole unit to face south. Solar panel cable comes out of one side and prevents rotation. Could end caps be assembled without epoxy?

SUPScientist, 2025-03-05:

SUPScientist, 2025-03-05:
New power design (voltaic panel/pack) obviates this issue.

Closed 2025-03-05.

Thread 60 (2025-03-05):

Epoxying solar cable penetration instead of using a gland seal may be a failure point

SUPScientist, 2025-03-05:

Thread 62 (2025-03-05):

Short battery life. ~ 10% and 0.08 V depletion over 22 hours on a reasonably sunny day (though low sun angle in winter)

SUPScientist, 2025-03-05:

Closed 2025-03-05.

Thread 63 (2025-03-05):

Water level sensor leads too short and brittle for plug/socket to be easily connected. One solder joint broke on sensor after assembly.

SUPScientist, 2025-03-05:

SUPScientist, 2025-03-05:
Current PVC design is shorter to accommodate length issue. Brittleness not accounted for in this design but https://github.com/COAST-Lab/Open-Water-Level-SK-15-Enclosure utilizes a custom PCB solution with better cable/socket options.

Closed 2025-03-05.

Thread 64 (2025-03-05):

Add desiccant to build and BOM

SUPScientist, 2025-03-05:
Follow best practices for field-deployed instrumentation (e.g., Boron and other PCBs, internal battery pack) and include a desiccant pack in new builds.

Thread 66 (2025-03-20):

Look into SDI-12 interface for particle products

BentleySettin, 2025-03-20:
CTD meter uses SDI-12 Interface and I need to determine how to integrate this with Particle Boron.

SUPScientist, 2025-03-20:
Thanks for creating this issue for the sake of project management, @BentleySettin! Please document your process and knowledge here as well both for posterity and so that I can chime in. I sent some ideas via email last week, so you can copy those into this thread. It sounded from Alex as though the UART block on the Boron could be used, albeit with a different library and not the typical `Serial1` that we use all the time.

SUPScientist, 2025-05-05:
Picked up over here (https://github.com/BentleySettin/SDI12_Boron/issues/1) so closing in this repo.

Closed 2025-05-05.

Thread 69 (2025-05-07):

Investigate logic to test Boron with max publish state at 11 minutes.

BentleySettin, 2025-05-07:
Is there a way to force the Boron to undergo an ISMI switch or full hardware reset during data collection to determine effectiveness of an 11 minute max publishing time?

BentleySettin, 2025-07-28:
@SUPScientist Sounds great, I will flash this today and let it run for 2-3 days to see if there are any hiccups.

SUPScientist, 2025-07-29:
Noting that this issue is closely related to, if not identical to, #68.

BentleySettin, 2025-07-31:
Sounds good, I closed it with a thread back to this conversation.

@SUPScientist
I have had the [new code ](https://github.com/COAST-Lab/Open-Water-Level/issues/69#issuecomment-3127709863) running for the past two days and am seeing some **percieved** connectivity issues within the lab. One of two things usually happen. 1)The first time it wakes up or the few times I have reset it, I have seen some new behavior. The boron will connect to the particle cloud and then for about 2-5 minutes go through a cycle of flashing cyan, two orange, some green and so on. According to particle files this means that it could not connect to internet. After these few minutes the boron flashes slow cyan (connected to internet) then white and then off. 2) The boron wakes up and uses the full time to try to connect to internet but doesn't.

I majority of the runs the boron will not wake up on the hour. I am testing code we know works to determine if this is an internet or firmware issue. I have switched the antenna too but that did not change anything.

BentleySettin, 2025-07-31:
On the particle console it has notes for waterLevel_0008 : "This Boron was deployed with the waterLevel_0005 device at BMC-RAND from 10-Mar-2025 through 25-Mar-2025 but stopped transmitting on 17-Mar-2025. The BMC-RAND site received a new Boron after testing isolated this Boron as seemingly the problem. New Boron installed at 1415 EDT 25-Mar-2025." This may be the issue as this was a boron that was not transmitting well at FMB, granted we also concluded that whole site may have been off with poor internet reception.

BentleySettin, 2025-08-01:
After switching to a new Boron (waterLevel_0010) the updated code is successfully running. The previous boron is in tinker mode with an antenna trying to connect to the cloud. After about 2 hours, still no success.

SUPScientist, 2025-08-01:
OK, let's separate these two issues even though they became apparent through the same process. Testing the timeout_test branch to solve the title issue here is ongoing (through the weekend to get multiple 24 hr cycles).

Separately, we need a new issue for troubleshooting (or, if needed, disposing of) waterLevel_0008.

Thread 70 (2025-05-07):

Update PVC end cap design to have more compatible o-ring grooves

BentleySettin, 2025-05-07:
Currently we see issues with the end cap o-ring grooves. When we try to place the PVC printed end cap into the PVC pipe the o-ring does not fully fit in the groove so the o-ring tends to pop out partially which is a risk of breaking the o-ring.

SUPScientist, 2025-05-19:
Nice work, and thanks for the detailed explanation.

Scenario 2 sounds promising, particularly,

> This new depth still checked all the parameters for o-ring grooves.

Let's go with that!

SUPScientist, 2025-05-19:
Please update the part files in the repo, make a PR referencing this issue, and then I can pull the changes/close the comment once the PR is merged.

SUPScientist, 2025-05-20:
Resolved (we believe) with https://github.com/COAST-Lab/Open-Water-Level/pull/74.

Closed 2025-05-20.

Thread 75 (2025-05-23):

Improve micro-USB connector from solar to Boron

SUPScientist, 2025-05-23:
### Challenge
We are currently cutting the Voltaic cable and splicing it onto a micro-USB cable to plug the male micro-USB plug into the Boron's micro-USB female socket. This is inefficient and error prone.

### Recommendation
Source a connector solution to go from the male 3.5 x 1.1 mm power plug on the Voltaic pack to the Boron's female micro-USB socket. In other words, we need something that starts with female 3.5 x 1.1 mm and converts to male micro-USB.

SUPScientist, 2025-05-23:
Voltaic sells such an adapter (https://voltaicsystems.com/A101/) but the right angle geometry won't fit in our PVC housing.

Another option would be to go with a two-part solution. First, female 3.5 x 1.1 mm socket to male USB-C (https://voltaicsystems.com/A125/) then female USB-C to male micro-USB.

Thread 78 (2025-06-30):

Create a separate eventname for testing water level sensors

BentleySettin, 2025-06-30:
Currently all published data from water level sensors go to "waterLevel" eventname which is connected to our google sheet. It would be helpful for during testing scenerios to use a separate eventname so that data from tests and real deployments are not intermingled.

SUPScientist, 2025-07-25:
That eventname also pushes data to the CORMP webpages, so for the same reason, it makes sense to have another eventname as well as an additional google sheet.

### Recommendations

- [ ] 1. Add a line below https://github.com/COAST-Lab/Open-Water-Level/blob/1709e3a53e8c88ff1828647cdf860f8a6e215f0f/Firmware/OWL_Boron_Maxbotix_MB7092_cm/src/OWL_Boron_Maxbotix_MB7092_cm.cp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 that is something like `const char * eventName = "testing";` Leave one uncommented and comment out the other.
- [ ] 2. Add `Log.info()` statements where data are printed out in loop below that also prints out the `eventName` so that we have it right in front of our eyes.
- [ ] 3. Add note in pre-deployment checklist to confirm that `PUBLISHING` is set to 1 and `eventName` to waterLevel.
- [ ] 4. Create new google sheet that catches the testing events.

BentleySettin, 2025-07-30:
**Firmware:**

I am currently using this chunk of code as my eventname:
" const char * eventName = "waterLevel_0008"; "

**Google Sheets Integration & Webhook Creation:**

I used protocol from our repo: https://github.com/COAST-Lab/Open-Water-Level/tree/main/Particle_Integration
There is currently a webhook for waterLevel and waterLevel_0008.

**Current Status:**

As of now waterLevel_0008 seems to be having connectivity issues within the lab and is therefore not reporting anything to the either google sheet or particle console. When I forced a reset, data printed on our master google sheet but not the separate WL_0008 google sheet I created. I am investigating where I may have gone wrong or where Particle may have had some integration/webhook updates.

BentleySettin, 2025-08-01:
After integrating a new boron I am succesfully seeing water level data for the new boron (waterLevel_0010) printing on both the large sheet and the personal sensor sheet.

I followed protocol from this page: https://github.com/COAST-Lab/Open-Water-Level/tree/main/Particle_Integration
The only change I made was that I commented out lines 50-52 from the .js.

Closed 2025-08-01.

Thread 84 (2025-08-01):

waterLevel_0008 intermittently (at best) connecting to cell networks

SUPScientist, 2025-08-01:
> Separately, we need a new issue for troubleshooting (or, if needed, disposing of) waterLevel_0008.

 _Originally posted by @SUPScientist in [#69](https://github.com/COAST-Lab/Open-Water-Level/issues/69#issuecomment-3145559371)_

See additional context in that issue thread.

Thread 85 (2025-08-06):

Three OWLs simultaneously lost cell service

SUPScientist, 2025-08-06:
### Problem
On 15-Jul-2025 at 0400, all four operational OWLs successfully sampled. Beginning at 0500, only the "RAND" site (waterLevel_0005) sampled and all three others ceased sampling for several days.
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

### Hypothesized cause
Only waterLevel_0005 had been updated to Device OS 6.2.1 (due to issues at the Randall site that we have been troubleshooting). All three other deployed units were still running 4.2.0. This seems likely to be more than a coincidence.

Suggest updating all other units (KERR, 23ST, and CHES) to Device OS 6.2.1 and latest FW.

SUPScientist, 2025-08-06:
Tagging @BentleySettin and @efarq just as an FYI based on yesterday's conversation.

BentleySettin, 2025-08-12:
Interesting that the last time we heard from waterLevel_0003 transmission took about 7 minutes. Could the SIM have undergone an IMSI switch which somhow affected its failure? Trying to use clues from connectivity conversation with [Rikkas](https://community.particle.io/t/confusing-boron-connectivity-issues/69438/3).

SUPScientist, 2025-08-15:
Updating after several days to say that both waterLevel_0003 and waterLevel_0006 which were upgraded to Device OS 6.2.1 and latest OWL user firmware have been unresponsive for at least several days. waterLevel_0003 worked @ 100% uptime for 72 hours post update while waterLevel_0006 worked for 16 hours post update. Both dropped to 0% uptime after that elapsed time.

Potentially of note, both these devices had Device OS upgraded via the Workbench Particle: Flash Device OS and User Firmware command (rather than Device Restore USB web tool, which is what had been used to update waterLevel_0005, which is still going very strong (> 99% uptime since 24-June while running Device OS 6.2.1).

Recommend updating to 6.3.3. We should also examine options for a system reset using hibernate mode according to https://community.particle.io/t/difficulty-reconnecting-to-cell-network/69817/7.

SUPScientist, 2025-10-06:
Re:

> Recommend updating to 6.3.3. We should also examine options for a system reset using hibernate mode according to https://community.particle.io/t/difficulty-reconnecting-to-cell-network/69817/7.

Hibernate is not likely an option for the Boron 404X according to https://docs.particle.io/reference/device-os/api/sleep-sleep/hibernate-systemsleepmode/. The Boron could likely go into Hibernate mode, but it cannot wake from a timer—only a WKP pin. A WKP pin is not a good solution in our case.

However, the other useful tidbit from that same Particle community thread is rickkas's:

> You should wait 12-15 minutes of failing to connect to cellular, not 5 minutes, to allow Device OS to do a full modem reset after 10 minutes

We need to try `MAX_TIME_TO_PUBLISH_MS = 900000`.

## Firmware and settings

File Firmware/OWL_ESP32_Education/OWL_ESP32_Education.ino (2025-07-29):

#include <Adafruit_GFX.h>
#include <Adafruit_SSD1306.h>
#include <SdFat.h>
#include <Wire.h>
#include <SPI.h>

//------------------SD SPI Configuration Details--------------------------------
const int SD_CHIP_SELECT = 10; // Pin 10
SdFat sd;

//------------------Display Configuration----------------------------------------
Adafruit_SSD1306 display(128, 32, &Wire); // Declare at global scope

//------------------LED Setup---------------------------------------------------
int led = 13; // Using onboard LED for Arduino
bool led_state = HIGH; // Starting state

//------------------Maxbotix Sensor---------------------------------------------
float distance_unconverted; // Raw analog read
float range_cm;

unsigned long real_time;
char data[120];

void setup() {
  pinMode(led, OUTPUT);

  Serial.begin(9600);
  Serial.println("Open Water Level - Fast Update Mode");

  // Initialize SD card
  if (!sd.begin(SD_CHIP_SELECT)) {
    Serial.println("SD card initialization failed!");
  } else {
    Serial.println("SD card initialized.");
  }

  // Initialize display
  if (!display.begin(SSD1306_SWITCHCAPVCC, 0x3C)) {
    Serial.println("SSD1306 initialization failed!");
    while (true); // Halt if the display initialization fails
  }
  // Rotate display 180 degrees
  display.setRotation(2); 

  // Show startup screen
  display.clearDisplay();
  display.setTextSize(2);
  display.setTextColor(SSD1306_WHITE);
  display.setCursor(0, 0);
  display.println("SEAS the");
  display.println("  day!");
  display.display(); // Show splash screen
  delay(1000); // Wait for the user to see it

  display.clearDisplay(); // Clear display for new data
}

void loop() {
  // Read sensor
  distance_unconverted = analogRead(A1);
  range_cm = distance_unconverted * 0.25;

  // Get current time in seconds
  real_time = millis() / 1000;

  // Save to SD
  snprintf(data, sizeof(data), "%lu,%.5f", real_time, range_cm);
  File dataFile = sd.open("distance.csv", FILE_WRITE);
  if (dataFile) {
    dataFile.println(data);
    dataFile.close();
    Serial.println("Data saved to SD:");
    Serial.println(data);
  } else {
    Serial.println("Error opening distance.csv");
  }

  // Update OLED display
  display.clearDisplay();
  display.setTextSize(2);
  display.setTextColor(SSD1306_WHITE);
  display.setCursor(0, 0);
  display.println("Dist (cm):");
  display.println(range_cm, 1); // 1 decimal place
  display.display();

  // Optional: blink LED to show activity
  digitalWrite(led, led_state);
  led_state = !led_state;

  // Wait 1 second before next read
  delay(1000);
}

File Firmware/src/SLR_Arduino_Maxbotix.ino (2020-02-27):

#include <SPI.h>
#include <Wire.h>
#include <Adafruit_GFX.h>
#include <Adafruit_SSD1306.h>
 
Adafruit_SSD1306 display = Adafruit_SSD1306(128, 32, &Wire);
 
// OLED FeatherWing buttons map to different pins depending on board:
#if defined(ESP8266)
  #define BUTTON_A  0
  #define BUTTON_B 16
  #define BUTTON_C  2
#elif defined(ESP32)
  #define BUTTON_A 15
  #define BUTTON_B 32
  #define BUTTON_C 14
#elif defined(ARDUINO_STM32_FEATHER)
  #define BUTTON_A PA15
  #define BUTTON_B PC7
  #define BUTTON_C PC5
#elif defined(TEENSYDUINO)
  #define BUTTON_A  4
  #define BUTTON_B  3
  #define BUTTON_C  8
#elif defined(ARDUINO_FEATHER52832)
  #define BUTTON_A 31
  #define BUTTON_B 30
  #define BUTTON_C 27
#else // 32u4, M0, M4, nrf52840 and 328p
  #define BUTTON_A  9
  #define BUTTON_B  6
  #define BUTTON_C  5
#endif

// Use these analog voltage variable, representing ultrasonic sensor output and conversions, later
//const int anPin = A0;
//long V_ultraS, mm, inches;

//int V_ultraS = A0;

int adcin    = A0;
int adcvalue = 0;
float mv_per_lsb = 3600.0F/8192.0F; // 14-bit ADC split in half with 3.6 V input range
float in_per_mv = 254.0F/3600.0F; // 254 in range sensor over 3.6 V input range
float mv, in;

void setup() {

  analogReadResolution(14); // Can be 8, 10, 12 or 14
  
  Serial.begin(9600);
 
  Serial.println("OLED FeatherWing test");
  // SSD1306_SWITCHCAPVCC = generate display voltage from 3.3V internally
  display.begin(SSD1306_SWITCHCAPVCC, 0x3C); // Address 0x3C for 128x32
 
  Serial.println("OLED begun");
 
  // Show image buffer on the display hardware.
  // Since the buffer is intialized with an Adafruit splashscreen
  // internally, this will display the splashscreen.
  display.display();
  delay(1000);
 
  // Clear the buffer.
  display.clearDisplay();
  display.display();
 
  Serial.println("IO test");
 
  pinMode(BUTTON_A, INPUT_PULLUP);
  pinMode(BUTTON_B, INPUT_PULLUP);
  pinMode(BUTTON_C, INPUT_PULLUP);
 
  // text display tests
  display.setTextSize(2);
  display.setTextColor(SSD1306_WHITE);
  display.setCursor(0,0);
  display.println("It's alive!");
  display.setCursor(0,0);
  display.display(); // actually display all of the above
  
  delay(2500);
}
 
void loop() {
//  V_ultraS = analogRead(anPin);  // Read analog pin
//
//  mm = V_ultraS*5; // Takes bit count and converts it to mm
//  inches = mm/25.4; // Takes mm and converts it to inches

  // Get a fresh ADC value
  adcvalue = analogRead(adcin);
  mv = (float)adcvalue * mv_per_lsb;
  in = mv*in_per_mv;
  
  display.clearDisplay();
  display.setTextSize(2);
  display.setTextColor(SSD1306_WHITE);
  display.setCursor(0,0);
  display.println("Dist (in):");
  display.println(in); //Counts * (V range/count range) * (Inch range/V range)
  display.display();

  delay(1000);
}

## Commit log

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2020-03-02 Rework OLED addition to UART reader
    [SLR_Arduino_Maxbotix.ino]
2020-03-03 Add enclosure SolidWorks parts, drawings, assembly and laser cutter file PDF
    [Back.SLDPRT, Bottom.SLDPRT, Enclosure Drawing.SLDDRW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]
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2022-08-04 Add how-to guide PDF
    [CORMP-CMSDOCK.csv, CORMP-CMSDOCK_WL.csv, Calibration_LukeEdwards.csv]
2022-08-04 Update calibration notebook
    [full_trial_test_data_raw.csv]
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2022-08-18 Add power budget
    [Power Budget.xlsx]
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2023-09-22 Delete Firmware/Getting Started With Particle for Water Level Sensor Images/5.jpg
    Removed image to replace with new one.
2023-09-29 add bills of materials
    [Alternate BOM 1.xlsx, Alternate BOM 2.xlsx, Primary Cellular BOM.xlsx]
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2023-10-18 condense prints a la https://github.com/COAST-Lab/Open-Water-Level/issues/7
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2023-10-25 add end caps for PVC-based housing
    [WaterLevel_BottomCap v2.f3d, WaterLevel_BottomCap v3.stl, WaterLevel_TopCap v5.f3d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]
2023-11-16 Update end caps
    [44615K415_Standard-Wall Steel Pipe Nipple.ipt, Part4.ipt, WaterLevel_BottomCap v3.stl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]
2023-11-22 update end-caps and printing orientation
    [WaterLevel_Top v10.f3d, WaterLevel_Top v10.stl, WaterLevel_Top v9.f3d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]
2023-11-28 rearrange 3D files
    [44615K415_Standard-Wall Steel Pipe Nipple.ipt, Part4.ipt, WaterLevel_BottomCap v2.f3d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]
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2024-01-27 update BOM excel sheet
    [Primary Cellular BOM.xlsx]
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2024-03-04 document sheets integration process a la https://github.com/COAST-Lab/Open-Water-Level/issues/24
2024-03-05 add data analysis from Smith Creek; remove adalogger and old transponder data/analysis
    [CORMP-CMSDOCK.csv, CORMP-CMSDOCK_WL.csv, Calibration_LukeEdwards.csv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]
2024-03-12 update readme to reference old repository
    [Smith Creek Deployment Log.xlsx]
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2024-03-28 new bracket for new solar panel/battery combo
    [Polycase-Voltaic-Bracket v7.f3d, Polycase-Voltaic-Bracket v7.stl, Polycase-Voltaic-Bracket_shorter.stl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]
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2024-04-01 realign solar panel mounting holes with bracket holes
    [Polycase-Voltaic-Bracket v12.f3d, Polycase-Voltaic-Bracket v12.stl]
2024-04-08 Update readme.md
    fixing table, there was a | in the cable glad part description
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2024-07-08 Added chassis 3D print files to repo
    [AntennaFrame_20240702.stl, Chassis_PVC_20240701(1).stl, Chassis_Polycase_20240702.stl]
2024-07-09 Updated descriptions for Polycase chassis
    [Chassis_Polycase_Combined_20240709.stl]
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2024-07-10 Fixed `Serial.print` issue with `Log.info` statements and updated Getting_Started instructions to reflect these changes!
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2024-07-11 updates to PVC End caps documentation
    [44615K415_Standard-Wall Steel Pipe Nipple.ipt, Part4.ipt, WaterLevel_BottomCap_ACL v2.f3d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]
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2024-07-15 uploaded new polycase chassis .stl file
    [Chassis_Polycase_Simplified_20240709.stl, Chassis_Polycase_Simplified_20240715.stl]
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2024-07-17 In SLR_Boron_Maxbotix_... file within Firmware, changed all Serial.print statements to Log.info statements. See Issue pertaining to Serial.print statements for more detail on code
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2024-07-18 added new chassis CAD files (7/18/24) and reorganized photos
    [AntennaFrame_20240702.stl, Chassis_PVC_20240701(1).stl, Chassis_PVC_20240718.stl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]
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2024-07-19 Update SLR_Boron_Maxbotix_MB7092_cm.ino
    Reverted .ino file from incorrect Log.info format to original Serial.print format
2024-07-19 deleted .md file with incorrect solution proposal and reverted SLR... .cpp file from Log.info to Serial.print
2024-07-19 Update SLR_Boron_Maxbotix_MB7092_cm.cpp
    Reverted .cpp file from incorrect Log.info format to original Serial.print format
2024-07-19 fixed photo pathways and sizing for assembly instructions PVC
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2024-07-24 changes in this commit address the simplified steps mentioned in the previous commit. I simplified the instructions to set up the sensor's firmware by lessening the number of changes to code a user w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
    [Chassis_PVC_20240724.stl]
2024-07-25 moved outdated .stl files for PVC chassis into "old" folder
    [Chassis_PVC_20240718.stl]
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2024-07-29 added assembly photos and finished (for now) assembly instructions (note: doesn't include instructions for physically setting up the whole entity to a stable surface)
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2024-07-30 moved outdated files into "Old"
    [44615K415_Standard-Wall Steel Pipe Nipple.ipt, Part4.ipt, Polycase-Voltaic-Bracket v11.f3d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]
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2024-07-30 uploaded parts spreadsheets to BOM folders + updated BOMs
    [Parts_PVCEnclosure.csv, Parts_PolycaseEnclosure.csv]
2024-10-21 Added collected data
    Added data file to data folder
    [102124_WL_Measurement.csv]
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2024-12-18 Play with copilot and run notebook in vs code; update notebook for dark background and latest data
    [Water Level 2024 - Sheet1 - 20241218.csv]
2025-01-16 Updated part of the PVC readme and added PVCTop design.
    I still need to update the photos within the readme
    [44615K415_Standard-Wall Steel Pipe Nipple.ipt, PVCTop.stl, Part4.ipt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]
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2025-02-17 update google sheet analysis notebook
    [Water Level 2024 - Sheet1 - 20250217.csv]
2025-02-18 create new power budget for boron, delete old Adalogger M0 based power budget
    [Power Budget.xlsx, Power-budget.xlsx]
2025-03-05 update data analysis with latest data
    [Water Level 2024 - Sheet1 - 20250225.csv]
2025-03-13 remove log with particle info
    [Smith Creek Deployment Log.xlsx]
2025-04-01 update time-series analysis with latest data
    [Water Level 2024 - Sheet1 - 20250325.csv, Water Level 2024 - Sheet1 - 20250401.csv]
2025-05-16 update data analysis and data
    [Water Level 2024 - Sheet1 - 20250404.csv, Water Level 2024 - Sheet1 - 20250425.csv]
2025-05-20 Updated PVC end cap files
    [PVCEndCap.ipt, PVCTopUpdated.ipt, PVCTopUpdated.stl]
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2025-08-07 add file manually downloaded from wl03
    [distance_wl_0003_20250806.csv]
2025-08-07 add simple dataviz script for data from micro-SD card
    [distance_wl_0003_20250806.csv, distance_wl_0003_20250806_truncate.csv]
2025-08-11 add raw data from BMC-RAND, waterLevel_0006
    [distance_wl_0006_20250811.csv]
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2025-08-21 add field notes doc
    [distance_wl_0003_20250821.csv]
2025-09-15 add manually downloaded data
    [distance_wl_0005_20250826.csv]
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2025-10-06 add downtime analysis to main
    [Downtime Analysis.xlsx]
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2026-02-13 update data download and analysis
    [distance_wl_0003_20260129.csv]
2026-05-18 rerun analysis to check single sensor (Kerr) battery voltage
    [distance_wl_0003_20260129_process.csv, distance_wl_0006_20260305.csv, wl-cormp_20240504-20260318.csv]
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
